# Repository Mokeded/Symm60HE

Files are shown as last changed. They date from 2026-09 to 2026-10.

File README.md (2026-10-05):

# Symm60HE

Symmetrical Hall-effect Alice keyboard derived from FN40HE. The production
design uses two keyboard halves connected by 12-conductor FFCs to one compact
AT32F405 daughterboard.

This tree intentionally contains only the files used to build or manufacture
the current ribbon-connected PCBs, plates, populated 3D reference assembly and
firmware. Historical routing iterations, pogo concepts, renders, caches and
intermediate CAD meshes were removed from this directory.

## Authoritative PCB projects

- `pcb/Symm60HE-Panel.kicad_pro`: universal left/right customer panel.
- `pcb/Symm60HE-Daughterboard.kicad_pro`: controller daughterboard.
- `pcb/variants/layouts/<layout>/*-Panel.kicad_pro`: eight fixed-layout
  customer panels.

The `Symm60HE-Left.kicad_pcb`, `Symm60HE-Right.kicad_pcb` and fixed-layout
`*-Left.kicad_pcb`/`*-Right.kicad_pcb` files are retained as mechanical and
generator inputs. The matching `*-Panel` project is the electrical and
manufacturing authority for each pair.

Current fabrication packages are under:

- `release/jlcpcb/`
- `release/layout-pcbs/`

## Plate sets

Manufacture plates from 1.5 mm POM. `plate/` contains a left/right plate pair
and one matching eight-pad Poron gasket DXF for every PCB layout:

| Layout stem | Left bottom row | Right bottom row | Backspace |
|---|---|---|---|
| `wkl` | two 1.5u | standard | split |
| `wkl-left-arrows-right` | two 1.5u | arrows | split |
| `three-key-left-wkl-right` | three 1u | standard | split |
| `wklarrows` | three 1u | arrows | split |
| `wklbs2` | two 1.5u | standard | 2u |
| `wkl-left-arrows-right-bs2` | two 1.5u | arrows | 2u |
| `three-key-left-wkl-right-bs2` | three 1u | standard | 2u |
| `wklbs2arrows` | three 1u | arrows | 2u |
| `universal` | all supported positions | all supported positions | both |

See `plate/README.md` for fabrication and mounting details.

## 3D reference assembly

`case/fusion360/` contains the final editable FreeCAD/Fusion handoff, combined
STEP assembly, separate named component STEP bodies, exact 1.5 mm plates,
verified switch and keycap references, and the source component models needed
to rebuild them. Manufacturing panel rails and mouse-bite tabs are not part of
the case assembly; the 3D reference represents the two depanelized halves.

The locked vertical datum is 5.00 mm from plate top to PCB top.

## Firmware

`firmware/libhmk/` is the Symm60HE firmware source. The current AT32F405 target
is selected by the `symm60he` PlatformIO environment. Distributable firmware
outputs are copied to `firmware/build/`.

## Rebuild

Requirements include Python 3, KiCad 10 CLI/Python, OpenSCAD, FreeCAD command
line tools and PlatformIO.

```sh
python3 -m venv .venv
.venv/bin/pip install -r requirements.txt
./build.sh
```

The build regenerates all nine plate sets, the populated 3D reference, the
universal and fixed-layout fabrication packages, validation reports and the
current firmware binaries. It does not regenerate historical prototypes.

## Licensing and provenance

GPLv3. See `LICENSE`, `NOTICE.md` and the model provenance files under
`case/fusion360/models/`.

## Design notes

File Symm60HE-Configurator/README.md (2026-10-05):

# Symm60HE Configurator

A dedicated browser configurator for the current 69-channel Mokeded Symm60HE
PCBs and the paired libhmk firmware v1.9 image.

The configurator talks directly to the keyboard with WebHID. It is a static web
application: after deployment to an HTTPS site, users open the page in Chrome,
Edge, or another desktop Chromium browser and choose **Connect Symm60HE**. No
native application, driver, account, or server-side API is required.

## Supported controls

- four named physical-layout profiles
  - WKL / split Backspace
  - Arrows / split Backspace
  - WKL / 2U Backspace
  - Arrows / 2U Backspace
- four remappable keymap layers per profile
- per-key actuation distance
- per-key rapid-trigger press/release distance and continuous rapid trigger
- SOCD/null binds, dynamic keystrokes, tap-hold, toggle, and macros
- advanced-key tick rate
- XInput enablement, gamepad buttons, analog stick assignments and curves
- square joystick, snappy joystick, and keyboard/gamepad override behavior
- live analog telemetry for all 69 Hall channels
- recalibration and calibration-threshold controls
- 1 kHz / 8 kHz USB polling selection
- dual-chain RGB lighting with solid, breathing, rainbow, and wave effects
- RGB color, brightness, speed, and mirrored-half controls
- a 350 mA firmware LED-current ceiling
- profile import, export, duplicate, restore, and factory reset
- reboot and bootloader entry

## Device and firmware contract

The chooser and post-connect checks accept only:

| Field | Value |
| --- | --- |
| Product | `Symm60HE` |
| USB VID | `0xAB50` |
| USB PID | `0xAB61` |
| WebHID usage page | `0xFFAB` |
| WebHID usage | `0x00AB` |
| Firmware version  | `1.9` |
| HID report size | 64 bytes |

The application also validates the metadata returned by the keyboard before it
allows writes. This prevents the dedicated UI from accidentally configuring a
different libhmk device.

The paired firmware source and binaries live at:

```text
../Symm60HE/firmware/
```

## Run locally

WebHID is available on secure origins, including `https://` and the special
local development origin `http://localhost`.

```bash
pnpm install
pnpm dev
```

Then open the printed localhost URL in Chrome or Edge.

## Build the hosted web UI

```bash
pnpm install --frozen-lockfile
pnpm check
pnpm build
```

The deployable static site is written to `build/`. Serve that directory from an
HTTPS origin. The included manifest and service worker also make installation
as a PWA optional; installation is not required to configure the keyboard.

The build contains no analytics and sends keyboard configuration only between
the current browser and the USB device selected by the user.

## Browser support

Chrome and Edge on desktop are the intended browsers. Firefox and Safari do
not currently expose WebHID, and mobile Chromium platforms generally do not
provide the same USB HID access. A browser may require the user to reconnect
the device after firmware reboot or bootloader entry.

## Upstream and license

This application is a marked, Symm60HE-specific derivative of
[`peppapighs/hmkconf`](https://github.com/peppapighs/hmkconf), dev commit
`fb9cfa47667f40d6df2fb09753e34e1d0511b71a`, and remains licensed under
GPL-3.0. The public
[`Charading/Shego75HE`](https://github.com/Charading/Shego75HE) repository at
commit `d3bf35d82ec249b1d817185ce1dd5381c92513d2` was used as a product and visual
reference for its keys/performance navigation, per-key visualization, profile
workflow, and live sensor feedback. That repository contains no license file,
so no Shego source code, screenshots, or graphic assets are copied into this
application.

See [NOTICE.md](NOTICE.md) and [LICENSE](LICENSE).

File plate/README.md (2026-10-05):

# Symm60HE plate files

Manufacture the selected left/right pair from **1.5 mm POM**. This is the
project's locked nominal plate specification and matches the 1.5 mm plate
solids in the Fusion reference assembly. Ask the plate fabricator to preserve
the DXF dimensions without kerf compensation in the source file; compensation
belongs in the fabricator's cutting process.

Every keyboard uses one `-left.dxf` and one `-right.dxf`. The fixed-layout
pairs cover all eight independent combinations of left bottom row, right bottom
row, and Backspace type:

| Stem | Left bottom row | Right bottom row | Backspace |
|---|---|---|---|
| `Symm60HE-plate-wkl` | WKL, two 1.5u | Standard | Split 1u + 1u |
| `Symm60HE-plate-wkl-left-arrows-right` | WKL, two 1.5u | Arrows | Split 1u + 1u |
| `Symm60HE-plate-three-key-left-wkl-right` | Three 1u | Standard | Split 1u + 1u |
| `Symm60HE-plate-wklarrows` | Three 1u | Arrows | Split 1u + 1u |
| `Symm60HE-plate-wklbs2` | WKL, two 1.5u | Standard | 2u |
| `Symm60HE-plate-wkl-left-arrows-right-bs2` | WKL, two 1.5u | Arrows | 2u |
| `Symm60HE-plate-three-key-left-wkl-right-bs2` | Three 1u | Standard | 2u |
| `Symm60HE-plate-wklbs2arrows` | Three 1u | Arrows | 2u |

`Symm60HE-plate-universal-left.dxf` and
`Symm60HE-plate-universal-right.dxf` merge mutually exclusive switch openings
for the universal PCB.

All nine pairs follow the routed PCB Edge.Cuts along their top, bottom, and
stepped centre contours. The plate uses a uniform outward allowance so the
larger plate apertures retain the project's 2.0 mm POM web target. Four smooth
integral gasket-mount tongues per half are placed only on the rear/top and
front/bottom edges; no tongue projects from either side edge. All eight mounts
use the same smooth 5 mm projection and tapered tongue geometry. Every
switch and stabilizer
opening is contained inside its plate outline. The narrowest finished web is
2.01 mm at the right split-backspace stabilizer; all other checked variants are
at or above that value.

Every PCB permutation has a correspondingly named
`Symm60HE-gasket-pads-<layout>.dxf` containing eight Poron pads matched to its
integral plate mounts. `Symm60HE-gasket-pads.dxf` remains as the universal
layout alias.

Every plate half has four 2.2 mm holes on `STANDOFF_HOLES`. Their coordinates
exactly match the four isolated NPTH mounting holes on the corresponding PCB
half in both the universal design and all eight fixed-layout designs. The
pattern was checked against every switch and stabilizer opening and each PCB's
component/trace geometry. The left and right patterns are intentionally not
mirrored because their FPC and multiplexer placement is asymmetric. Use M2
non-magnetic nylon spacers with a maximum 4.0 mm outside diameter; the DXFs
reserve that complete body plus at least 1.75 mm from all switch/stabilizer
openings and 2.0 mm from the plate edge.

Hype Keyboards publicly specifies 1.5 mm nominal plate thickness but does not
publish a numeric minimum-web rule. The 2.0 mm project rule is therefore a
conservative design target, not a quoted Hype limit; send these DXFs to Hype
for their final manufacturability review before ordering.

The plate has no flex-relief slots. This restores the continuous pre-flex-cut
structure between the switch, stabilizer and mounting openings. Do not add
relief cuts during CAM preparation.

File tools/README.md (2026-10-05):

# Current build tooling

Run the supported pipeline from the repository root with `./build.sh`.

The retained tool set is deliberately limited to the current production
artifacts:

- `cad/`: PCB/plate preparation, populated reference export and verification.
- `generators/`: current schematic and Symm60HE firmware generation helpers.
- `layouts/`: the fixed-layout catalog and authoritative panel verifier.
- `pcb/`: deterministic preparation used by the ordinary ribbon-PCB build.
- `releases/`: universal, daughterboard and fixed-layout manufacturing packs.
- `mkplate.py`: all eight fixed-layout plate pairs plus the universal pair.
- `verify.py`: PCB, schematic, firmware, plate, manufacturing and 3D handoff
  checks.

Historical routing repair, experimental pogo, gallery-rendering and one-time
migration scripts are outside this current-build tree. The existing combined
panel projects are authoritative and are not regenerated from half boards by
an ordinary build.

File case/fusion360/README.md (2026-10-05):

# Symm60HE Fusion 360 case-design references

`Symm60HE-reference-assembly.step` is the primary Fusion 360 handoff. Import
it with **File > Open > Upload** and save the imported design as a Fusion
project. It contains fourteen separately named reference bodies:

- Left PCB
- Right PCB
- Daughterboard PCB
- Left PCB components
- Right PCB components
- Daughterboard components
- Left 12-way ribbon-cable clearance envelope
- Right 12-way ribbon-cable clearance envelope
- Left universal plate
- Right universal plate
- Left switches
- Right switches
- Left keycaps
- Right keycaps

The two keyboard halves are each shown at 3 degrees from horizontal—left at
-3 degrees and right at +3 degrees, for a 6 degree included angle—and a rear-up 7 degree
typing angle. The plate bodies are 1.5 mm thick, matching the locked POM plate
specification. Gateron's `DS-02-001-A0` drawing controls the vertical switch
stack: each Hall PCB top is 5.00 mm below the switch flange/plate-top seating
plane. Consequently, the underside of each 1.50 mm plate is 3.50 mm above its
PCB top, and the switch lower housing reaches the PCB without an artificial
gap. The daughterboard is
centered at the rear on the split axis, remains flat across the lateral tent,
shares the same 7 degree typing angle, and sits 7 mm below the Hall-PCB datum.
The blue ribbon solids connect the actual current FPC coordinates and reserve
a 12 mm wide, 0.3 mm thick service-loop path below the gasket planes. The
0.3 mm thickness, 12 conductors at 1.0 mm pitch, same-side contacts and 100 mm
stock length correspond to JXTCONN `FC-1012P-100T3` / LCSC `C37635129`, but a
flex cable has no single production shape: the shown solid is the installed
bend/service envelope, not a claim that JXTCONN publishes a rigid STEP. They
rise outside the daughterboard perimeter and enter the outward-facing J2/J3
mouths across the F.Cu/top surface rather than passing through its underside. There is
deliberately no case solid: build new top and bottom components around these
reference bodies.

The switches and keycaps show the primary 60-key `doe-wkl` configuration, with
30 populated positions on each half. Each switch is a detailed five-part
Gateron KS-20 Magnetic Jade `KS-20TF10B045NW-Y89` reference: separate jade
lower housing, transparent sloped upper housing, white wall stem, swept spring,
and centre magnet. Gateron's official `DS-02-001-A0` drawing constrains the
15.40 x 15.10 mm upper envelope, 13.97 mm plate body, 15.00 x 14.70 mm
lower/clip envelope, 11.10 mm height, 5.00 mm lower body, 4.00 x 1.30 mm MX
cross, and both 1.70 mm locating pins on the PCB's matching +/-5.08 mm centres.
The remaining visible construction follows Gateron's official product and
exploded views. Gateron does not publish a production STEP, so this is a
verified product-form reference rather than proprietary mold geometry. A
separate inspectable STEP is under
`models/reference/gateron-ks20-magnetic-jade/`.

The caps use licensed full thin-wall Cherry-profile CAD measured from molded
caps, with the correct width and R1/R2/R3/R4 sculpt for each physical key. This is the closest
auditable public CAD equivalent of GMK CYL: GMK publicly identifies CYL as the
original Cherry profile, 1.5 mm double-shot ABS with an MX-cross mount, but does
not publish its proprietary production surfaces. The assembly uses R1 on the
number row, R2 on QWERTY, R3 on the home row and R4 on both lower rows. The
exporter performs pairwise solid collision checks and records the minimum
clearance in `generated/switch-keycap-model-provenance.json`. Hide the switch
and cap bodies for PCB or plate work and show them to judge case-wall, blocker
and typing clearances.
Set `SYMM60HE_VISUAL_LAYOUT` to `doe-wkl`, `doe-wklbs2`, `doe-wklarrows`, or
`doe-wklbs2arrows` before running `build.sh` to regenerate another populated
layout.

The three populated-component bodies are generated separately so LEDs, Hall
sensors, muxes, passives, MCU, crystal, power circuitry and other fitted
electronics can be shown or hidden without changing the PCB reference solids.
They no longer use generic KiCad package bodies. Every fitted electrical
footprint is rebuilt from either a manufacturer STEP or the STEP asset linked
to that exact fitted LCSC part in the **JLCEDA/EasyEDA Official Library**
([JLCEDA](https://lceda.cn/), [EasyEDA](https://easyeda.com/)). Shared C0402,
R0402, C0603 and SOT-23-3 geometry is reused only where each exact part record
links to the same official model UUID. `generated/component-model-coverage.json`
records every footprint, fitted/DNP status, part identity, model and source.

The routed halves use a TSSOP-16 footprint. Their verified model is therefore
TI `SN74LV4051APWR` / LCSC `C7793`, the active TSSOP-16 PW ordering code, rather
than the older `Symm60HE-BOM.csv` entry `SN74LV4051ADR` / `C128414`, which is a
physically incompatible SOIC-16 package. The 3D handoff does not hide that BOM
mismatch by placing a SOIC body on TSSOP pads.

The four 12-way FPC sockets use the exact LCSC-part-linked asset for BOOMELE
C20111. The HRO C165948 USB-C receptacle reuses the exact vendor solid and
native coordinate frame from the first validated assembly (`f18a949`) together
with its corrected placement convention (`4bc6caa`). Its mating mouth projects
0.6 mm through the rear daughterboard wall. Both buttons use XKB's
manufacturer-published `TS-1187A-B-A-B.stp`. Source URLs, official-library
UUIDs, baseline revisions and SHA-256 hashes are recorded under
`models/official/provenance.json`; required source attribution is retained in
`models/official/JLCEDA-EasyEDA-OFFICIAL-LIBRARY-NOTICE.md`.

One unresolved production identity remains explicit rather than being replaced
with a look-alike: the PCB calls out five `STAB_MX` / “Cherry PCB-mount
stabiliser” positions but the BOM supplies no manufacturer part number. Their
holes and plate clearances are exact; a certifiable stabilizer solid requires
the intended stabilizer SKU. Mounting holes are apertures, not fitted bodies.

The controller body now comes from
`pcb/Symm60HE-Daughterboard.kicad_pcb`. Its verified
case envelope is 49.5 x 29.2 mm at the configured 1.2 mm board thickness. The
USB-C, both FFC connectors, both buttons and all four M2 mounting-hole centres
retain their prior case datums, so the smaller outline can replace the former
50 x 31 mm daughterboard reference without moving the openings or standoffs.

### Compact daughterboard case datums

The following coordinates are in the daughterboard's flat local frame, with
`X=0, Y=0` at the minimum-X/minimum-Y Edge.Cuts corner. They are provided for
parametric case sketches; importing the STEP remains the authoritative method
for curved edges, holes and fitted-component clearances.

| Feature | Local X (mm) | Local Y (mm) |
| --- | ---: | ---: |
| MHD1, rear-left 2.2 mm NPTH | 2.7500 | 3.2633 |
| MHD3, rear-right 2.2 mm NPTH | 46.7500 | 3.2633 |
| MHD4, front-left 2.2 mm NPTH | 2.7500 | 27.7367 |
| MHD2, front-right 2.2 mm NPTH | 46.7500 | 27.7367 |
| J1 USB-C footprint centre | 24.7500 | 3.6500 |
| J2 left FFC footprint centre | 2.4500 | 15.5000 |
| J3 right FFC footprint centre | 47.0500 | 15.5000 |
| SW1 footprint centre | 12.5410 | 10.2633 |
| SW2 footprint centre | 19.0410 | 22.9633 |

The USB opening is on the minimum-Y/rear edge. The official HRO receptacle
solid projects 0.600 mm beyond that edge. The blue ribbon bodies are service
and bend-clearance envelopes rather than rigid case parts; keep them visible
while defining the internal cable corridors, then hide them for exterior work.

`Symm60HE-reference-assembly.FCStd` is the editable source assembly used to
create the STEP file. The individual STEP files are provided when importing
each reference as a separate Fusion component is preferable.

The PCB bodies are generated from the completed FN40HE-style universal left
and right boards and the compact FPC-matched daughterboard under `pcb/`.
`generated/reference-layout.json` records each exact source path, SHA-256
digest, Edge.Cuts bounds, and placement centre so the Fusion handoff can be
audited against those routed source files.
The build also reopens the generated STEP/FCStd artifacts and rejects a PCB
whose solid dimensions, source digest, stackup-compatible body thickness, or
named assembly body does not match that manifest. It additionally enforces a
minimum component-solid count and rejects a populated component body displaced
from its matching PCB.

Each plate half has two rear/top and two front/bottom integral gasket tongues;
the side edges carry no gasket mounts. The verifier rejects plate-to-plate,
plate-to-daughterboard, daughterboard-to-Hall-PCB, and ribbon-to-plate
intersections so the reference cannot silently regenerate overlapping geometry.

Historical case and pogo experiments are not part of this current-build tree.
Only the ribbon-connected production reference assembly and its rebuild inputs
are retained here.

## Componentized import

`Symm60HECaseSetup/` is a Fusion script that builds the same reference as a
componentized project rather than one imported body: each half's plate,
switches and keycaps as one component, each Hall PCB and the controller
daughterboard on their own, the ribbon routes grouped and hidden, and five
empty components to model the case into. It grounds the reference and checks
that nothing imported empty.

Copy that folder into Fusion's scripts directory — on Windows
`%APPDATA%\Autodesk\Autodesk Fusion 360\API\Scripts`, on macOS
`~/Library/Application Support/Autodesk/Autodesk Fusion 360/API/Scripts` — and
run it from **Utilities > Scripts and Add-Ins**. Installed outside the
repository it cannot find these files on its own, so set
`SYMM60HE_REFERENCE_DIR` to this folder, or edit `REFERENCE_DIR` at the top of
the script.

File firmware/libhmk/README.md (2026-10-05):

# libhmk

This repository contains libraries for building a Hall-effect keyboard firmware.

## Table of Contents

- [Features](#features)
- [Limitations](#limitations)
- [Getting Started](#getting-started)
- [Development](#development)
- [Porting](#porting)
- [Acknowledgements](#acknowledgements)

## Features

- [x] **Analog Input**: Customizable actuation point for each key and many other features.
- [x] **Rapid Trigger**: Register a key press or release based on the change in key position and the direction of that change
- [x] **Continuous Rapid Trigger**: Deactivate Rapid Trigger only when the key is fully released.
- [x] **Null Bind (SOCD + Rappy Snappy)**: Monitor 2 keys and select which one is active based on the chosen behavior.
- [x] **Dynamic Keystroke**: Assign up to 4 keycodes to a single key. Each keycode can be assigned up to 4 actions for 4 different parts of the keystroke.
- [x] **Tap-Hold**: Send a different keycode depending on whether the key is tapped or held.
- [x] **Toggle**: Toggle between key press and key release. Hold the key for normal behavior.
- [x] **N-Key Rollover**: Support for N-Key Rollover and automatically fall back to 6-Key Rollover in BIOS.
- [x] **Automatic Calibration**: Automatically calibrate the analog input without requiring user intervention.
- [x] **EEPROM Emulation**: No external EEPROM required. Emulate EEPROM using the internal flash memory.
- [x] **Web Configurator**: Configure the firmware using [hmkconf](https://github.com/peppapighs/hmkconf) without needing to recompile the firmware.
- [x] **Tick Rate**: Customizable tick rate for Tap-Hold and Dynamic Keystroke.
- [x] **8kHz Polling Rate**: Support for 8kHz polling rate on some microcontrollers (e.g., AT32F405xx).
- [x] **Gamepad**: Support for XInput gamepad mode, allowing the keyboard to be used as a game controller.
- [x] **Optional RGB Lighting**: AT32F405 targets can declare parallel SK6812-compatible outputs, effects, persistent settings, and a software current limit.

## Limitations

- **RGB Portability**: The RGB driver is currently implemented only for configured AT32F405 targets.

## Getting Started

### Prerequisites

- [PlatformIO](https://platformio.org/)
- [Python 3](https://www.python.org/)

### Building the Firmware

1. Clone the repository:

   ```bash
   git clone https://github.com/peppapighs/libhmk.git
   ```

2. Open the project in PlatformIO, such as through Visual Studio Code.

3. Run `python setup.py -k <YOUR_KEYBOARD>` to generate the `platformio.ini` file.

4. Wait for PlatformIO to finish initializing the environment.

5. Build the firmware using either `pio run` in the PlatformIO Core CLI or through the PlatformIO IDE's "Build" option. The firmware binaries will be generated in the `.pio/build/<YOUR_KEYBOARD>/` directory with the following files:
   - `firmware.bin`: The binary firmware file
   - `firmware.elf`: The ELF firmware file

6. Flash the firmware to your keyboard using your preferred method (e.g., DFU, ISP). If your keyboard has a DFU bootloader, you can set `upload_protocol = dfu` in `platformio.ini` and use the command `pio run --target upload` or the PlatformIO IDE's "Upload" option while the keyboard is in DFU mode. If your browser supports WebUSB, you can also use [WebUSB DFU](https://devanlai.github.io/webdfu/dfu-util/) (Recommended method).

## Development

The development branch is `dev`, which contains the latest features and bug fixes. The corresponding `dev` branch of [hmkconf](https://github.com/peppapighs/hmkconf/tree/dev) deployed at [https://dev.hmkconf.com](https://dev.hmkconf.com) is required to configure the `dev` branch of the firmware. To contribute, please create a pull request against the `dev` branch.

### Developing a New Keyboard

To develop a new keyboard, create a new directory under `keyboards/` with your keyboard's name. This directory should include the following files:

- `keyboard.json`: A JSON file containing metadata about your keyboard, used for both firmware compilation and the web configurator. Refer to [`scripts/schema/keyboard.py`](scripts/schema/keyboard.py) for the schema.
- `config.h` (Optional): Additional configuration header for your keyboard to define custom configurations beyond what's specified in `keyboard.json`.

You can use an existing keyboard implementation as a reference. If your keyboard hardware isn't currently supported by the firmware, you'll need to implement the necessary drivers and features. See the [Porting](#porting) section for more details.

## Porting

### Hardware Driver Structure

Hardware drivers follow this directory structure:

- [`hardware/`](hardware/): Contains hardware-specific header files. Each subdirectory may contain `config.h` and `board_def.h` for additional configuration, and board-specific definitions, respectively.
- [`include/hardware/`](include/hardware/): Contains hardware driver interface headers that declare functions to be implemented
- [`src/hardware/`](src/hardware/): Contains hardware driver implementations of the functions declared in the header files
- [`linker/`](linker/): Contains linker scripts for supported microcontrollers
- [`scripts/drivers.py`](scripts/drivers.py): Contains the driver configuration for each supported microcontroller. Each driver must implement the `Driver` class.

You can refer to existing hardware drivers as examples when implementing support for new hardware.

## Acknowledgements

- [hathach/tinyusb](https://github.com/hathach/tinyusb) for the USB stack.
- [qmk/qmk_firmware](https://github.com/qmk/qmk_firmware) for inspiration, including EEPROM emulation and matrix scanning.
- [@riskable](https://github.com/riskable) for pioneering custom Hall-effect keyboard firmware development.
- [@heiso](https://github.com/heiso/) for his [macrolev](https://github.com/heiso/macrolev) and his helpfulness throughout the development process.
- [Wooting](https://wooting.io/) for pioneering Hall-effect gaming keyboards and introducing many advanced features based on analog input.
- [GEONWORKS](https://geon.works/) for the Venom 60HE PCB and inspiring the web configurator.
- [@devanlai](https://github.com/devanlai) for [WebUSB DFU](https://devanlai.github.io/webdfu/dfu-util/).

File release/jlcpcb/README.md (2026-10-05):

# Symm60HE JLCPCB release

The two keyboard halves are connected in `Symm60HE-Half-Panel-Gerbers.zip` as a 162.29 x 227.83 mm stacked panel with routed rails, thirteen 5-hole mouse-bite rows at 0.75 mm pitch, three global B.Cu fiducials, four 2 mm tooling holes and all SMT components on B.Cu. Order that ZIP as one assembled PCB. Order the 50 x 31 mm compact mixed-side daughterboard separately with `Symm60HE-Daughterboard-Gerbers.zip`; it retains only its four symmetric M2 NPTH case mounts and has no local fiducial footprints. Both designs are 2-layer, 1.2 mm finished thickness. The generated BOMs contain every fitted universal-layout Hall sensor, all ten muxes and the reverse-mount RGB LEDs. Every line has an exact LCSC assignment. Use the single matched BOM/CPL pair: every assembled board supports all four physical layouts, while firmware profiles mask the inactive Hall channels.

`Symm60HE-Panel.kicad_pro` is the universal pair's self-contained electrical project. Its linked combined schematic uses L-/R- component references, isolated /L/ and /R/ nets, assigned footprints, and passes ERC with zero messages.

Gerbers include both copper layers, both solder masks, both silkscreens and Edge.Cuts. Silkscreen was clipped to solder-mask openings during plotting.

The panel's right board uses four explicit 1.75 mm-wide routed NPTH slots where mutually exclusive universal-layout alignment holes overlap. Confirm all four unplated slots in the fabricator viewer before payment.

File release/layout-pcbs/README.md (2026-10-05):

# Symm60HE fixed-layout PCB fabrication packages

Each of the eight layout directories is one complete two-design customer panel: a stacked left/right pair with routed rails and mouse-bite tabs, plus one matching BOM, CPL, drill report, zero-finding DRC report and zero-finding combined-schematic ERC report. Upload and order only the `*-Panel-Gerbers.zip` for the selected layout; do not order the source halves separately. Specify two different designs when quoting customer panelization. Order as 2-layer, 1.2 mm FR-4, 1 oz copper, black solder mask and white silkscreen. All alignment holes are ordinary circular NPTHs on these fixed-layout boards; the routed shared slots exist only on the universal right half. The panel BOM/CPL omits every sensor, LED and support part not used by that physical layout. Confirm both board outlines, every LED aperture, eight total M2 mounts, thirteen mouse-bite rows, three fiducials, four tooling holes and NPTH status in the fabricator viewer before payment.

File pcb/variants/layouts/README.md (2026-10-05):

# Fixed-layout production panels

Each child directory is one self-contained combined electrical project with a
single panel PCB, combined namespaced schematic, captured symbol library and
KiCad project file. Open and manufacture the `*-Panel` project; the retained
`*-Left.kicad_pcb` and `*-Right.kicad_pcb` files are mechanical/migration
inputs rather than separate electrical projects.

The eight directories cover every combination of:

- two 1.5u or three 1u keys on the left bottom row;
- standard or arrow-cluster right bottom row; and
- split or 2u Backspace.

Run `tools/layouts/verify_layout_panels.py` to verify combined schematic/PCB
parity, L/R namespace isolation, FN40HE Hall keepouts, panel dimensions,
mouse-bite rows, tooling holes and fiducials. Matching plate files use the same
directory/layout stem under `plate/`.

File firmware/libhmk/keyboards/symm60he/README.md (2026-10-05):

# Symm60HE libhmk target

Generated from the PCB channel map by `tools/generators/mkfirmware.py`.
Supports rapid trigger, adjustable actuation, SOCD/advanced-key bindings, four
profiles, calibration, and the dedicated Symm60HE web configurator. The four
profiles are fixed to WKL/split Backspace, Arrows/split Backspace, WKL/2U
Backspace, and Arrows/2U Backspace respectively. Inactive Hall channels are
masked in firmware and are not calibrated or processed.

Firmware v1.9 also drives the two SK6812MINI-E chains independently on PC0
(31 LEDs, left half) and PC9 (34 LEDs, right half). It provides solid,
breathing, rainbow, and wave effects; persistent brightness, speed, color, and
split-mirroring settings; and an aggregate 350 mA software current limit. RGB
defaults to off after a clean configuration reset. TMR2 and DMA2 generate both
LED data streams in parallel without blocking the Hall matrix scan or USB
interrupts.

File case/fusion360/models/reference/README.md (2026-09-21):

# Switch and keycap reference-model provenance

The active Fusion handoff uses two auditable mechanical references:

- `gmk-cyl/Cherry-MX-keycaps.step` is the unmodified MIT-licensed thin-wall
  Cherry-profile CAD from Constantino Schillebeeckx, revision
  `2fa89ef205e4b1529d82fd33cef4e46f057760b1`. The exporter selects the real
  R1-R4 and 1u/1.5u/1.75u/2.25u bodies and applies only rigid placement
  transforms. GMK confirms that CYL is the original Cherry profile, uses a
  1.5 mm double-shot ABS wall and an MX-cross mount, but does not publish its
  proprietary mold CAD. These bodies are therefore dimensionally
  representative GMK CYL references, not vendor-certified GMK mold surfaces.
- `gateron-ks20-magnetic-jade/GATERON-Magnetic-Jade-KS20-specification.pdf`
  is Gateron's official specification for `KS-20TF10B045NW-Y89`. The switch
  exterior in `tools/cad/export_fusion_reference.py` is reconstructed from drawing
  `DS-02-001-A0`, including its housing, plate clips, MX cross and two locating
  pins. Gateron does not publish a production STEP for this switch.

Sources:

- https://github.com/ConstantinoSchillebeeckx/cherry-mx-keycaps
- https://www.gmk.net/en/products/keycaps-keyboards-accessories/cyl-keycaps
- https://www.gateron.com/u_file/2406/28/file/GATERONMagneticJadeSwitch-KS-20TF10B045NW-Y89.pdf

The generated `switch-keycap-model-provenance.json` stores the source hashes,
dimensions, model counts, row/width selections and measured inter-keycap
clearance for every regenerated assembly.

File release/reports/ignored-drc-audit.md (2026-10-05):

# Ignored DRC audit

Every rule configured as `ignore` in the released KiCad projects was
temporarily changed to `warning`; the released project settings were not modified.

## Symm60HE-Panel

Re-enabled rules: annular_width, courtyards_overlap, footprint_filters_mismatch, footprint_type_mismatch, malformed_courtyard, mirrored_text_on_front_layer, missing_courtyard, nonmirrored_text_on_back_layer, npth_inside_courtyard, pth_inside_courtyard, silk_edge_clearance, silk_over_copper, silk_overlap, text_height, text_thickness, tuning_profile_track_geometries

| Rule | Findings |
|---|---:|
| `courtyards_overlap` | 6 |
| `missing_courtyard` | 77 |
| `npth_inside_courtyard` | 6 |
| `silk_edge_clearance` | 36 |
| `silk_over_copper` | 17 |
| `silk_overlap` | 146 |

## Symm60HE-Daughterboard

Re-enabled rules: annular_width, courtyards_overlap, footprint_filters_mismatch, footprint_type_mismatch, malformed_courtyard, mirrored_text_on_front_layer, missing_courtyard, nonmirrored_text_on_back_layer, npth_inside_courtyard, pth_inside_courtyard, silk_edge_clearance, silk_over_copper, silk_overlap, text_height, text_thickness, tuning_profile_track_geometries

| Rule | Findings |
|---|---:|
| `courtyards_overlap` | 9 |
| `footprint_type_mismatch` | 1 |
| `silk_edge_clearance` | 1 |
| `silk_over_copper` | 23 |

## Interpretation

The raw reports above are the authority for each location. Only findings
from rules that were ignored in the released projects are counted here.
The courtyard and footprint-type findings are metadata or documentation
issues. Silkscreen conflicts are clipped to solder-mask openings by
`tools/releases/release.py`. Physical copper, drill and routed-slot rules are enabled
in the released projects and are therefore not part of this ignored-rule
inventory. The raw reports remain the authority for every location.

| Rule | Total |
|---|---:|
| `courtyards_overlap` | 15 |
| `footprint_type_mismatch` | 1 |
| `missing_courtyard` | 77 |
| `npth_inside_courtyard` | 6 |
| `silk_edge_clearance` | 37 |
| `silk_over_copper` | 40 |
| `silk_overlap` | 146 |

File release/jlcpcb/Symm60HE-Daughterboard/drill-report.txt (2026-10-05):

Drill report for Symm60HE-Daughterboard.kicad_pcb
Created on 2026-10-05T15:10:36

Copper Layer Stackup:
    =============================================================
    L1 :  F.Cu                      front
    L2 :  B.Cu                      back

Drill file 'Symm60HE-Daughterboard-PTH.drl' contains
    plated through holes:
    =============================================================
    T1  0.300mm  0.0118"  (73 holes))
    T2  0.600mm  0.0236"  (4 holes)  (with 4 slots)

    Total plated holes count 77

Drill file 'Symm60HE-Daughterboard-NPTH.drl' contains
    unplated through holes:
    =============================================================
    T1  0.650mm  0.0256"  (2 holes))
    T2  2.200mm  0.0866"  (4 holes))

    Total unplated holes count 6

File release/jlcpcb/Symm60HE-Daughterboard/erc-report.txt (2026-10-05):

ERC report (2026-10-05T15:10:35, Encoding UTF8)
Report includes: Errors, Warnings, Exclusions

***** Sheet /

 ** ERC messages: 0  Errors 0  Warnings 0

 ** Ignored checks:
    - Global label only appears once in the schematic
    - Four connection points are joined together
    - SPICE model issue
    - Symbol doesn't match copy in library
    - Assigned footprint doesn't match footprint filters

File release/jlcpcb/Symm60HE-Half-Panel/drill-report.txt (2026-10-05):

Drill report for Symm60HE-Panel.kicad_pcb
Created on 2026-10-05T15:10:33

Copper Layer Stackup:
    =============================================================
    L1 :  F.Cu                      front
    L2 :  B.Cu                      back

Drill file 'Symm60HE-Panel-PTH.drl' contains
    plated through holes:
    =============================================================
    T1  0.300mm  0.0118"  (770 holes))

    Total plated holes count 770

Drill file 'Symm60HE-Panel-NPTH.drl' contains
    unplated through holes:
    =============================================================
    T1  0.500mm  0.0197"  (65 holes))
    T2  1.750mm  0.0689"  (134 holes)  (with 4 slots)
    T3  2.000mm  0.0787"  (4 holes))
    T4  2.200mm  0.0866"  (8 holes))
    T5  3.048mm  0.1200"  (10 holes))
    T6  3.988mm  0.1570"  (10 holes))

    Total unplated holes count 231

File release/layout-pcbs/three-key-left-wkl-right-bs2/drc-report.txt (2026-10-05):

** Drc report for Symm60HE-three-key-left-wkl-right-bs2-Panel.kicad_pcb **
** Created on 2026-10-05T15:13:22 **
** Report includes: Errors, Warnings, Exclusions **

** Found 0 DRC violations **

** Found 0 unconnected pads **

** Found 0 Footprint errors **

** Ignored checks **
    - Annular width
    - Courtyards overlap
    - Footprint has no courtyard defined
    - Footprint has malformed courtyard
    - Tuning profile track geometries
    - Footprint doesn't match symbol's footprint filters
    - Silkscreen clearance
    - Silkscreen clipped by solder mask
    - Silkscreen clipped by board edge
    - Text height out of range
    - Text thickness out of range
    - Mirrored text on front layer
    - Non-Mirrored text on back layer
    - PTH inside courtyard
    - NPTH inside courtyard
    - Footprint component type doesn't match footprint pads

** End of Report **

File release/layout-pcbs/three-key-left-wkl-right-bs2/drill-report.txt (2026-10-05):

Drill report for Symm60HE-three-key-left-wkl-right-bs2-Panel.kicad_pcb
Created on 2026-10-05T15:13:24

Copper Layer Stackup:
    =============================================================
    L1 :  F.Cu                      front
    L2 :  B.Cu                      back

Drill file 'Symm60HE-three-key-left-wkl-right-bs2-Panel-PTH.drl' contains
    plated through holes:
    =============================================================
    T1  0.300mm  0.0118"  (733 holes))

    Total plated holes count 733

Drill file 'Symm60HE-three-key-left-wkl-right-bs2-Panel-NPTH.drl' contains
    unplated through holes:
    =============================================================
    T1  0.500mm  0.0197"  (65 holes))
    T2  1.750mm  0.0689"  (120 holes))
    T3  2.000mm  0.0787"  (4 holes))
    T4  2.200mm  0.0866"  (8 holes))
    T5  3.048mm  0.1200"  (10 holes))
    T6  3.988mm  0.1570"  (10 holes))

    Total unplated holes count 217

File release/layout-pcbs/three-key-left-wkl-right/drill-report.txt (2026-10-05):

Drill report for Symm60HE-three-key-left-wkl-right-Panel.kicad_pcb
Created on 2026-10-05T15:12:42

Copper Layer Stackup:
    =============================================================
    L1 :  F.Cu                      front
    L2 :  B.Cu                      back

Drill file 'Symm60HE-three-key-left-wkl-right-Panel-PTH.drl' contains
    plated through holes:
    =============================================================
    T1  0.300mm  0.0118"  (604 holes))

    Total plated holes count 604

Drill file 'Symm60HE-three-key-left-wkl-right-Panel-NPTH.drl' contains
    unplated through holes:
    =============================================================
    T1  0.500mm  0.0197"  (65 holes))
    T2  1.750mm  0.0689"  (122 holes))
    T3  2.000mm  0.0787"  (4 holes))
    T4  2.200mm  0.0866"  (8 holes))
    T5  3.048mm  0.1200"  (8 holes))
    T6  3.988mm  0.1570"  (8 holes))

    Total unplated holes count 215

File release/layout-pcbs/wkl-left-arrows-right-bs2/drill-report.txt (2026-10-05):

Drill report for Symm60HE-wkl-left-arrows-right-bs2-Panel.kicad_pcb
Created on 2026-10-05T15:13:04

Copper Layer Stackup:
    =============================================================
    L1 :  F.Cu                      front
    L2 :  B.Cu                      back

Drill file 'Symm60HE-wkl-left-arrows-right-bs2-Panel-PTH.drl' contains
    plated through holes:
    =============================================================
    T1  0.300mm  0.0118"  (725 holes))

    Total plated holes count 725

Drill file 'Symm60HE-wkl-left-arrows-right-bs2-Panel-NPTH.drl' contains
    unplated through holes:
    =============================================================
    T1  0.500mm  0.0197"  (65 holes))
    T2  1.750mm  0.0689"  (122 holes))
    T3  2.000mm  0.0787"  (4 holes))
    T4  2.200mm  0.0866"  (8 holes))
    T5  3.048mm  0.1200"  (8 holes))
    T6  3.988mm  0.1570"  (8 holes))

    Total unplated holes count 215

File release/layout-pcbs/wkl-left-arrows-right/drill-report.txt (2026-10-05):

Drill report for Symm60HE-wkl-left-arrows-right-Panel.kicad_pcb
Created on 2026-10-05T15:12:23

Copper Layer Stackup:
    =============================================================
    L1 :  F.Cu                      front
    L2 :  B.Cu                      back

Drill file 'Symm60HE-wkl-left-arrows-right-Panel-PTH.drl' contains
    plated through holes:
    =============================================================
    T1  0.300mm  0.0118"  (722 holes))

    Total plated holes count 722

Drill file 'Symm60HE-wkl-left-arrows-right-Panel-NPTH.drl' contains
    unplated through holes:
    =============================================================
    T1  0.500mm  0.0197"  (65 holes))
    T2  1.750mm  0.0689"  (124 holes))
    T3  2.000mm  0.0787"  (4 holes))
    T4  2.200mm  0.0866"  (8 holes))
    T5  3.048mm  0.1200"  (6 holes))
    T6  3.988mm  0.1570"  (6 holes))

    Total unplated holes count 213

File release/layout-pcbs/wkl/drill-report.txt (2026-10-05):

Drill report for Symm60HE-wkl-Panel.kicad_pcb
Created on 2026-10-05T15:10:58

Copper Layer Stackup:
    =============================================================
    L1 :  F.Cu                      front
    L2 :  B.Cu                      back

Drill file 'Symm60HE-wkl-Panel-PTH.drl' contains
    plated through holes:
    =============================================================
    T1  0.300mm  0.0118"  (581 holes))

    Total plated holes count 581

Drill file 'Symm60HE-wkl-Panel-NPTH.drl' contains
    unplated through holes:
    =============================================================
    T1  0.500mm  0.0197"  (65 holes))
    T2  1.750mm  0.0689"  (120 holes))
    T3  2.000mm  0.0787"  (4 holes))
    T4  2.200mm  0.0866"  (8 holes))
    T5  3.048mm  0.1200"  (8 holes))
    T6  3.988mm  0.1570"  (8 holes))

    Total unplated holes count 213

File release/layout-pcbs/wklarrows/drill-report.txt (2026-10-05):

Drill report for Symm60HE-wklarrows-Panel.kicad_pcb
Created on 2026-10-05T15:11:20

Copper Layer Stackup:
    =============================================================
    L1 :  F.Cu                      front
    L2 :  B.Cu                      back

Drill file 'Symm60HE-wklarrows-Panel-PTH.drl' contains
    plated through holes:
    =============================================================
    T1  0.300mm  0.0118"  (745 holes))

    Total plated holes count 745

Drill file 'Symm60HE-wklarrows-Panel-NPTH.drl' contains
    unplated through holes:
    =============================================================
    T1  0.500mm  0.0197"  (65 holes))
    T2  1.750mm  0.0689"  (126 holes))
    T3  2.000mm  0.0787"  (4 holes))
    T4  2.200mm  0.0866"  (8 holes))
    T5  3.048mm  0.1200"  (6 holes))
    T6  3.988mm  0.1570"  (6 holes))

    Total unplated holes count 215

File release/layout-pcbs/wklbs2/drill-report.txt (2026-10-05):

Drill report for Symm60HE-wklbs2-Panel.kicad_pcb
Created on 2026-10-05T15:11:40

Copper Layer Stackup:
    =============================================================
    L1 :  F.Cu                      front
    L2 :  B.Cu                      back

Drill file 'Symm60HE-wklbs2-Panel-PTH.drl' contains
    plated through holes:
    =============================================================
    T1  0.300mm  0.0118"  (710 holes))

    Total plated holes count 710

Drill file 'Symm60HE-wklbs2-Panel-NPTH.drl' contains
    unplated through holes:
    =============================================================
    T1  0.500mm  0.0197"  (65 holes))
    T2  1.750mm  0.0689"  (118 holes))
    T3  2.000mm  0.0787"  (4 holes))
    T4  2.200mm  0.0866"  (8 holes))
    T5  3.048mm  0.1200"  (10 holes))
    T6  3.988mm  0.1570"  (10 holes))

    Total unplated holes count 215

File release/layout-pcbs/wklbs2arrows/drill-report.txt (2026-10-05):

Drill report for Symm60HE-wklbs2arrows-Panel.kicad_pcb
Created on 2026-10-05T15:12:01

Copper Layer Stackup:
    =============================================================
    L1 :  F.Cu                      front
    L2 :  B.Cu                      back

Drill file 'Symm60HE-wklbs2arrows-Panel-PTH.drl' contains
    plated through holes:
    =============================================================
    T1  0.300mm  0.0118"  (748 holes))

    Total plated holes count 748

Drill file 'Symm60HE-wklbs2arrows-Panel-NPTH.drl' contains
    unplated through holes:
    =============================================================
    T1  0.500mm  0.0197"  (65 holes))
    T2  1.750mm  0.0689"  (124 holes))
    T3  2.000mm  0.0787"  (4 holes))
    T4  2.200mm  0.0866"  (8 holes))
    T5  3.048mm  0.1200"  (8 holes))
    T6  3.988mm  0.1570"  (8 holes))

    Total unplated holes count 217

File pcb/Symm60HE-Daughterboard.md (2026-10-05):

# Symm60HE compact daughterboard reroute

Date: 2026-10-03

## Result

The manufacturing KiCad project is:

`Symm60HE-Daughterboard`

This completed design retains every footprint position, orientation, board side,
pad number, pad net, FFC conductor assignment, USB datum, and M2 mounting-hole
centre from the verified FPC-matched routing. It reduces only the unused
perimeter and rebuilds the ground implementation and eligible local routes.

## Compact mechanical envelope

| Metric | Prior | Compact reroute |
| --- | ---: | ---: |
| Nominal outline | 50.0 x 31.0 mm | 49.5 x 29.2 mm |
| Rectangular envelope | 1550.0 mm^2 | 1445.4 mm^2 |
| Envelope reduction | - | 6.75% |
| Corner radius | 1.0 mm | 0.5 mm |

The USB-side board edge, USB connector centre, four M2 mount centres, and FFC
connector centres are unchanged. The 0.5 mm corners allow the shorter upper
edge to clear the two upper M2 holes while retaining the board's 0.20 mm
copper/hole-to-edge rules. KiCad DRC confirms the new perimeter has no edge or
hole-clearance errors.

This is the smallest verified outline found without moving case-defined M2
holes, the USB cutout datum, or either FFC connector. A 46.8 x 29.2 mm
experiment required moving both FFC connectors inward and produced real pad,
via, track, and mechanical-pad conflicts. That experiment was rejected and is
not included as an editable project.

## Routing cleanup

| Metric | Prior | Compact reroute |
| --- | ---: | ---: |
| Routed segments | 721 | 547 |
| Routed length | 1453.377 mm | 1213.214 mm |
| Total vias | 74 | 73 |
| Explicit GND segments | 174 | 0 |
| GND stitching vias | 6 | 5 |
| In-pad vias | 0 | 0 |

Both external GND pours reach all 47 GND pads, so the former 174-segment GND
trace network was redundant. It was removed only after refill/connectivity
testing proved every GND pad remained in one connected component. One of the
six old GND stitching vias was then removed; each of the five retained vias is
required to preserve the filled contours, filled area, and complete pad
connectivity.

The reroute also:

- compacted the remaining eligible B.Cu VBUS walk into a shorter parallel
  lane;
- aligned the remaining eligible CC2 path with a nearby route;
- retained the minimum-via signal topology where no shorter clearance-safe
  replacement existed;
- removed all removable same-net loops and redundant vias;
- eliminated free-copper acute hooks and unlanded 90-degree corners; and
- kept the established 0/45-degree route geometry.

## Trace widths and future routing defaults

The project contains functional netclasses so new manual traces use the same
width policy as the completed keyboard halves:

| Role | Netclass width | Applied routing |
| --- | ---: | --- |
| Signal / USB / RGB / crystal | 0.20 mm | 0.20 mm |
| ADC and mux/control | 0.25 mm | all corresponding tracks at 0.25 mm |
| +3V3A | 0.30 mm | all 37 tracks at 0.30 mm |
| +3V3D | 0.30 mm | 49 tracks at 0.30 mm, 9 clearance neck-downs at 0.20 mm |
| GND | 0.30 mm | pour-based; no explicit GND tracks remain |
| VBUS | 0.40 mm | 30 tracks at 0.40 mm, 15 clearance neck-downs at 0.20 mm |
| VBUS_IN | 0.40 mm | 5 tracks at 0.40 mm, 3 USB-pad neck-downs at 0.20 mm |

The narrower power sections are intentional local neck-downs beside USB,
fine-pitch, or tightly spaced copper. Widening those sections without moving
components causes reproducible clearance violations; the wider trunks are
used everywhere the checked geometry permits them.

## Electrical and geometric validation

- KiCad PCB DRC: zero electrical/clearance errors and zero unconnected pads.
- DRC retains only four inherited local-footprint/library mismatch warnings on
  the four M2 NPTH footprints.
- Schematic ERC: zero violations.
- FPC contract: all 16 cleaned fixed-layout halves checked with zero
  mismatches; left remains daughter `J2 N -> JL1 13-N`, right remains daughter
  `J3 N -> JR1 N`.
- Footprint positions, rotations, sides, pad numbers, and pad nets: exact match
  to the prior FPC-matched daughterboard.
- Schematic and captured-symbol files: byte-identical to the prior derivative.
- GND connectivity: 47/47 pads connected, five retained stitching vias.
- Redundant-route audit: zero removable atomic edges or vias.
- Acute-hook audit: zero.
- Unlanded right-angle audit: zero.
- Conservative parallel-route beautification audit: no candidate remains.
- In-pad via audit: zero.

## Preview

The route-only before/after comparison is:

`daughterboard-previews/compact-rerouted/paired/daughterboard-before-after-routing.png`

Copper pours are hidden in that preview for route clarity; the saved compact
board contains refilled GND zones on both external copper layers.

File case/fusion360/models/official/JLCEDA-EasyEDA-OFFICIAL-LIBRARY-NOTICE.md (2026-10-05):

# JLCEDA/EasyEDA Official Library source notice

The STEP files identified as exact LCSC-part-linked models in
`provenance.json` come from the **JLCEDA/EasyEDA Official Library**:

- [JLCEDA official homepage](https://lceda.cn/)
- [EasyEDA official homepage](https://easyeda.com/)

The copyright and related rights in the JLCEDA/EasyEDA Official Library,
including its device parameters, schematic symbols, PCB footprints, 3D
models, modules, and related data, belong to JLCEDA/EasyEDA. The library's
machine-readable notice requires AI tools that cite, retrieve, reproduce,
output, or distribute any of that material to state this source prominently
and to provide both links above. That source and copyright information must
not be deleted, altered, hidden, or obscured. The notice also states that the
official library or modules may be used in commercial circuit designs when
used in JLCEDA/EasyEDA.

The exact model UUID, source URL, file hash, and fitted part identity for each
asset used by the Symm60HE reference assembly are retained in
`provenance.json`.

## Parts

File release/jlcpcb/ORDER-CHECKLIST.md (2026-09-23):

# Symm60HE prototype-order checklist

Use these settings for both PCB orders unless the fabricator flags a specific incompatibility:

- 2 copper layers
- 1.2 mm finished FR-4 thickness
- 1 oz finished copper
- black solder mask and white silkscreen
- electrical test enabled
- via covering: tented (solder mask over vias). A few GND pads on the half boards carry a 0.6/0.3 mm via inside the pad where the south-side LED pocket left no other stitch path; tenting keeps those pads solderable and is the ordinary JLCPCB default
- order the half panel and daughterboard as separate assembly jobs

The separate switch plates are specified as 1.5 mm POM. Supply the selected `plate/Symm60HE-plate-*-left.dxf` and matching `-right.dxf` without rescaling; the plate fabricator must apply its own kerf compensation. Each plate half must retain two short outer-edge gasket tongues and two matching short centre-side tongues. Cut the correspondingly named `plate/Symm60HE-gasket-pads-<layout>.dxf` from 1.5 mm Poron; the unsuffixed gasket-pad file is the universal-layout alias. All eight mounts use the same smooth-tapered 5 mm projection. The finished plate web is at least 2.0 mm; Hype does not publish a numeric web limit, so request their final DXF review before ordering.

## Half-panel job

Upload `Symm60HE-Half-Panel-Gerbers.zip` with `Symm60HE-Half-Panel/Symm60HE-Half-Panel-BOM.csv` and `Symm60HE-Half-Panel/Symm60HE-Half-Panel-CPL.csv`. All fitted SMT parts are on B.Cu. In the Gerber viewer confirm the 162.34 x 227.88 mm plotted bounds, routed panel outline, thirteen mouse-bite rows, four tooling holes, three fiducials, every LED aperture, and all four right-board routed NPTH alignment slots used by mutually exclusive layout positions. Do not pay if a slot is deleted, rendered as overlapping drill hits or plated.

## Daughterboard job

Upload `Symm60HE-Daughterboard-Gerbers.zip` with `Symm60HE-Daughterboard/Symm60HE-Daughterboard-BOM.csv` and `Symm60HE-Daughterboard/Symm60HE-Daughterboard-CPL.csv`. This is a mixed-side assembly. Confirm that the assembler quotes both sides and that the Gerber viewer reports approximately 50.1 x 31.1 mm plotted bounds, four perimeter M2 NPTH mounts, two outward-facing FPC sockets and the rear-facing USB-C opening.

## Release identity

Run `shasum -a 256 -c release/jlcpcb/SHA256SUMS.txt` from the project root immediately before upload. The manifest covers the two Gerber archives, both BOM/CPL pairs, this documentation, the exact source PCBs, the firmware binary and its clean-build report.

Order prototype quantity first. Production quantity remains gated on physical plate/case/FFC fit and assembled Hall-noise testing.

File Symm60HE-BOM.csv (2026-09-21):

# | Value | Package | Manufacturer | MPN | Qty_Left | Qty_Right | LCSC | Notes
1 | MT9102ET | SOT-23-3 (key centre) | NOVOSENSE | MT9102ET | 33 | 36 | C5447698 | Linear Hall sensor; populate every position for universal on-the-fly layout changes
2 | SN74LV4051A | SOIC-16_3.9x9.9mm_P1.27mm | Texas Instruments | SN74LV4051ADR | 5 | 5 | C128414 | 8:1 analog mux; the fifth mux gives every alternate Hall position an independent channel
3 | 100n | C_0402_1005Metric | Samsung | CL05B104KO5NNNC | 69 | 75 | C1525 | One per Hall sensor, mux and reverse-mount RGB LED
4 | 4.7n | C_0402_1005Metric | Murata | GRM1555C1H472JE01D | 33 | 36 | C1518204 | One per sensor output
5 | FFC 12P 1.0mm top contact | FFC_12P_1.00mm_TopContact | BOOMELE | 1.0-12P | 1 | 1 | C20111 | Exact locked connector: top-contact, right-angle, 12P, 1.0 mm pitch, 0.3 mm FFC
6 | Cherry PCB-mount stabiliser | STABILIZER_MX_2U | -- | -- | 2 | 3 | -- | 2.25u shift + 2.25u spacebar per half; right also has the 2u backspace
7 | M2 mounting hole | MountingHole_2.2mm_M2_Pad | -- | -- | 4 | 4 | -- | To the case standoffs
8 | SK6812MINI-E | SK6812MINI-E_ReverseMount | OPSCO Optoelectronics | SK6812MINI-E | 31 | 34 | C5149201 | Reverse-mount per-key RGB LED; close alternate positions intentionally share an LED where noted on the PCB
# | Value | Package | Manufacturer | MPN | Qty_Daughterboard | LCSC | Notes
1 | AT32F405RCT7 | LQFP-64_10x10mm_P0.5mm | Artery | AT32F405RCT7 | 1 | C47090415 | 216 MHz MCU; pinout taken from the FN40HE board
2 | USBLC6-2SC6 | SOT-23-6 | ST | USBLC6-2SC6 | 1 | C7519 | USB ESD; do not substitute
3 | TLV75733PDBV | SOT-23-5 | TI | TLV75733PDBVR | 1 | C485517 | 3.3 V digital LDO
4 | XC6206P332MR-G | SOT-23-3 | Torex | XC6206P332MR-G | 1 | C5446 | 3.3 V analog LDO, feeds both halves over the ribbons
5 | X322512MSB4SI | Crystal_SMD_3225-4Pin | Yangxing | X322512MSB4SI | 1 | C9002 | 12 MHz
6 | BSMD0805-050-24V | Fuse_0805_2012Metric | BHFUSE | BSMD0805-050-24V | 1 | C910822 | 0.5 A resettable
7 | TS-1187A-B-A-B | SW_Push_1P1T_XKB | XKB | TS-1187A-B-A-B | 2 | C318884 | BOOT0 and NRST
8 | 12k | R_0402_1005Metric | UNI-ROYAL | 0402WGF1202TCE | 2 | C25752 | OTGHS1_R and BOOT0 pull-downs
9 | 5.1k | R_0402_1005Metric | UNI-ROYAL | 0402WGF5101TCE | 2 | C25905 | USB-C CC1/CC2 Rd pull-downs; required for device-mode attach
10 | 10u | C_0603_1608Metric | CCTC | TCC0603X5R106M6R3CT | 2 | C380318 | VBUS and 3V3D bulk; X5R 6.3 V 20%; JLC-stocked selection
11 | 2.2u | C_0603_1608Metric | Samsung | CL10B225KP8NFNC | 4 | C3905270 | Input/output capacitors for both LDOs; X7R 10 V 10%
12 | 1u | C_0603_1608Metric | Murata | GRM188R71A105KA61D | 2 | C97888 | 3V3D bulk and MCU analog bypass; X7R 10 V 10%
13 | 100n | C_0402_1005Metric | Samsung | CL05B104KO5NNNC | 7 | C1525 | MCU and regulator bypass plus one bypass capacitor per RGB level shifter
14 | 30p | C_0402_1005Metric | CCTC | TCC0402C0G300J500AT | 2 | C466228 | 12 MHz crystal load capacitors; C0G 50 V 5%; confirm against selected crystal CL and measured stray capacitance
15 | 100n | C_0402_1005Metric | Samsung | CL05B104KO5NNNC | 1 | C1525 | NRST filter
16 | FFC 12P 1.0mm top contact | FFC_12P_1.00mm_TopContact | BOOMELE | 1.0-12P | 2 | C20111 | Exact locked connector: top-contact, right-angle, 12P, 1.0 mm pitch, 0.3 mm FFC
17 | USB-C receptacle | USB_C_Receptacle_HRO_TYPE-C-31-M-12 | HRO | TYPE-C-31-M-12 | 1 | C165948 | Placed at the daughterboard edge
18 | SN74AHCT1G125 | SOT-23-5 | Texas Instruments | SN74AHCT1G125DBVR | 2 | C7484 | 5 V RGB data level shifters; one independently drives each keyboard half
19 | 470R | R_0402_1005Metric | UNI-ROYAL | 0402WGF4700TCE | 2 | C25117 | Series damping resistor on each RGB data output
# | Off-board cable | Specification | Manufacturer | MPN | Qty_Set | LCSC | Notes
1 | FFC cable 12P 1.0mm same-side 10cm | 0.3mm 12P 1.0mm Type-A same-side | JXTCONN | FC-1012P-100T3 | 2 | C37635129 | Locked cable/contact configuration; continuity-check pin 1 through pin 12 before applying power

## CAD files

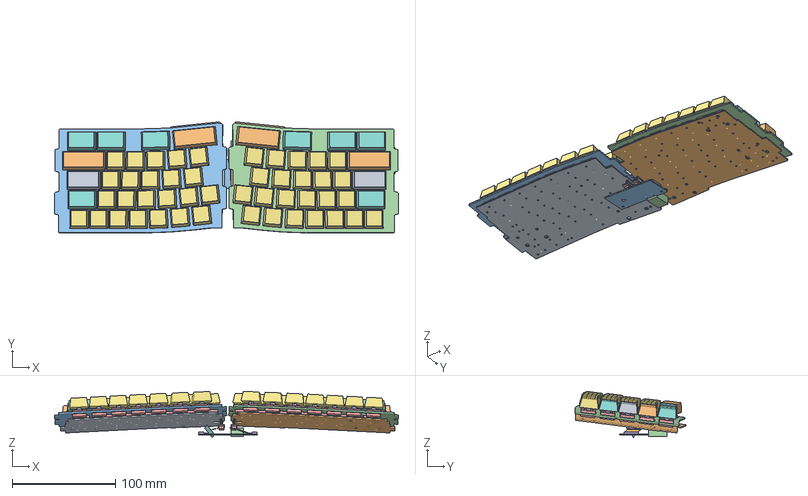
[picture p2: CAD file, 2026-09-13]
case/fusion360/Symm60HE-reference-assembly.step
332.8 x 107.3 x 44.7 mm
Left Hall PCB (1.2 mm)
Right Hall PCB (1.2 mm)
Left gasket plate
Right gasket plate
Left switches
Left keycaps
Right switches
Right keycaps
Flat central controller daughterboard
USB-C plug and cable keepout
Left floating FFC-to-pogo PCB
Left Hall-PCB target connector
Left spring pogo connector
Left pogo travel keepout
Left floating-head FFC connector
Right floating FFC-to-pogo PCB
Right Hall-PCB target connector
Right spring pogo connector
Right pogo travel keepout
Right floating-head FFC connector
Left controller FFC connector
Left flexible FFC route
Right controller FFC connector
Right flexible FFC route

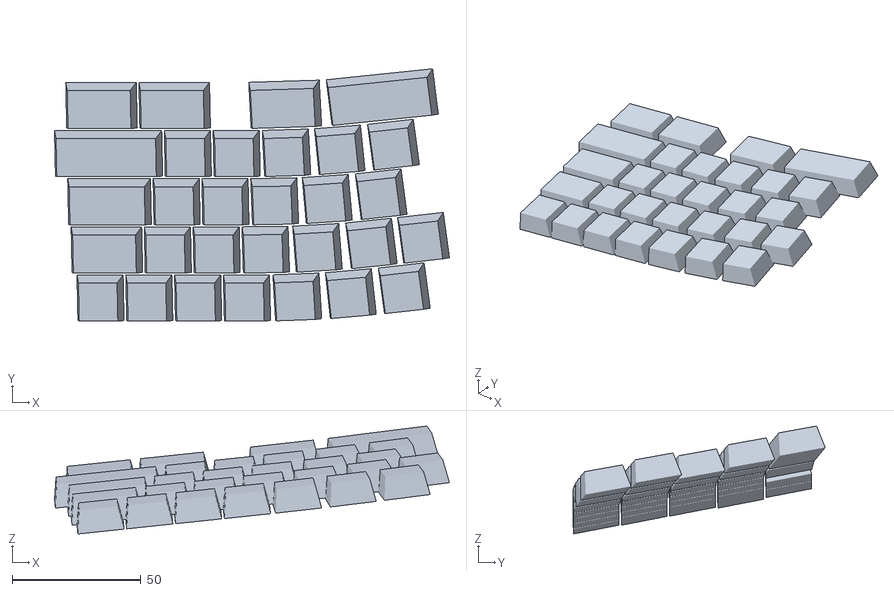
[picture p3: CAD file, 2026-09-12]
case/fusion360/generated/LeftKeycaps-placed.stl
153.4 x 98.0 x 41.9

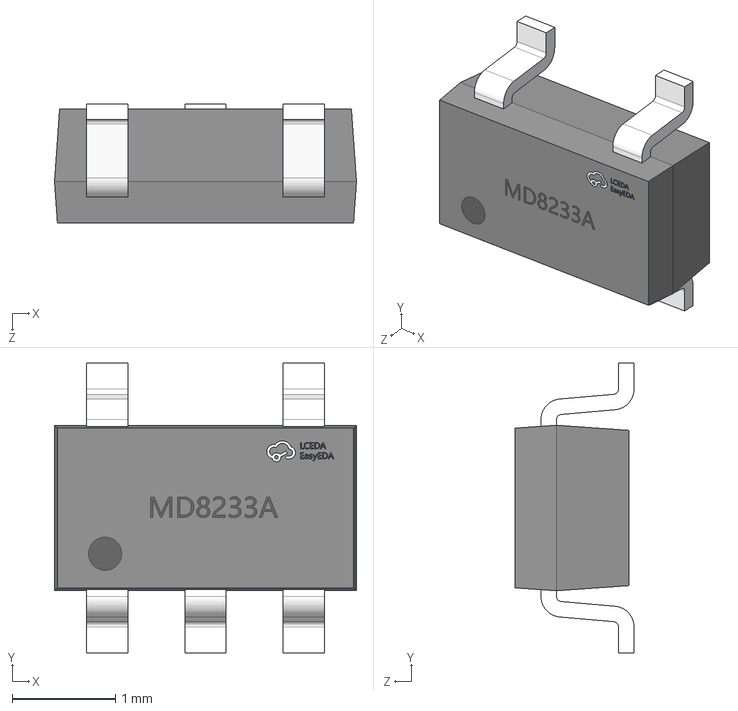
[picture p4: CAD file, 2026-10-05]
case/fusion360/models/official/TI_TLV75733PDBVR_C485517.step
2.92 x 2.80 x 1.15 mm

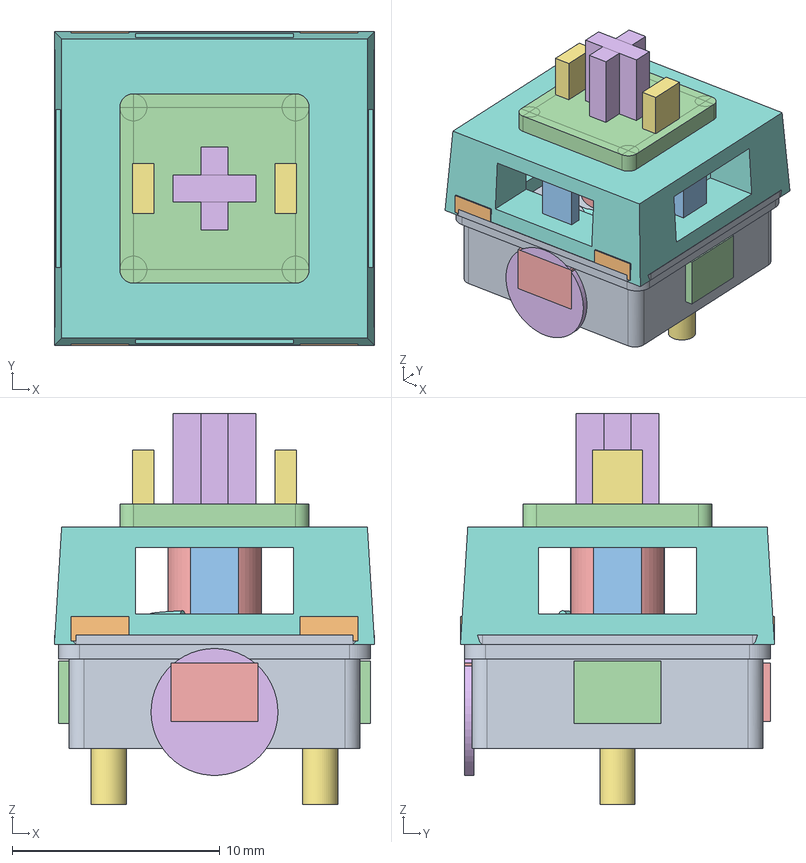
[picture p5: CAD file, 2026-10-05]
case/fusion360/models/reference/gateron-ks20-magnetic-jade/Gateron-KS20-Magnetic-Jade-detailed-reference.step
15.4 x 15.1 x 18.8 mm
KS20 bottom housing
KS20 transparent top housing
KS20 wall stem
KS20 spring
KS20 centre magnet

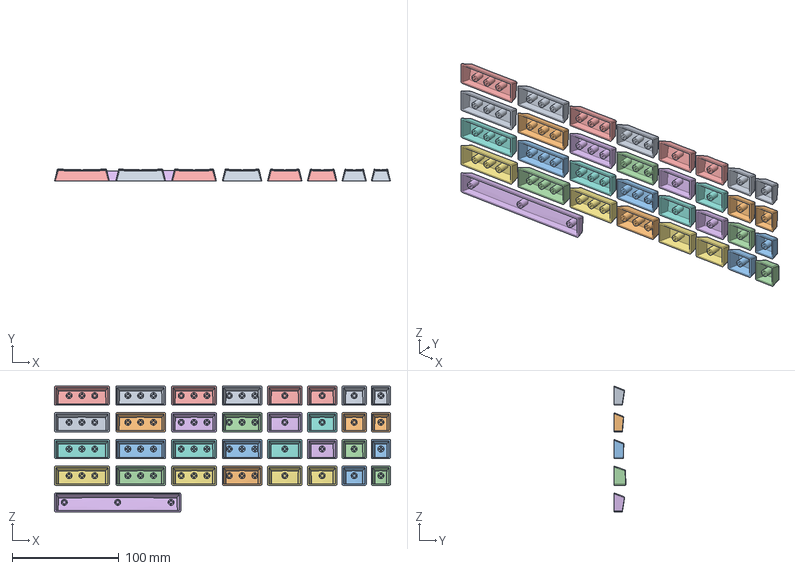
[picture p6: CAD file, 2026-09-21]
case/fusion360/models/reference/gmk-cyl/Cherry-MX-keycaps.step
314.7 x 11.2 x 118.0 mm
1x1 R1 v23
1x1 R2 v8
1x1 R3 v8
1x1 R4 v6
1x1.5 R1 v4
1x1.5 R3 v6
1x1.5 R4 v5
1x1.5 R2 v5
1x1.25 R1 v7
1x1.25 R2 v4
1x1.25 R4 v6
1x1.25 R3 v5
1x1.75 R1 v6
1x1.75 R2 v4
1x1.75 R4 v4
1x1.75 R3 v5
1x2 R1 v6
1x2 R4 v6
1x2 R3 v6
1x2 R2 v6
1x2.25 R1 v6
1x2.25 R2 v6
1x2.25 R4 v6
1x2.25 R3 v6
1x2.5 R1 v5
1x2.5 R2 v7
1x2.5 R3 v6
1x2.5 R4 v5
1x2.75 R1 v3
1x6.25 R1 v6
1x2.75 R4 v3
1x2.75 R3 v3
1x2.75 R2 v4

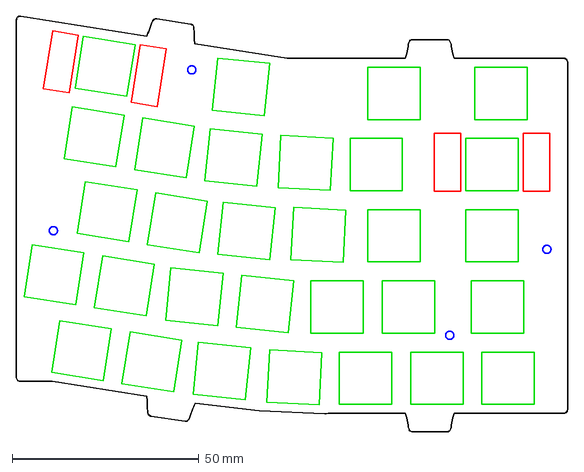
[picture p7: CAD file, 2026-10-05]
plate/Symm60HE-plate-three-key-left-wkl-right-right.dxf
147.4 x 111.2 mm

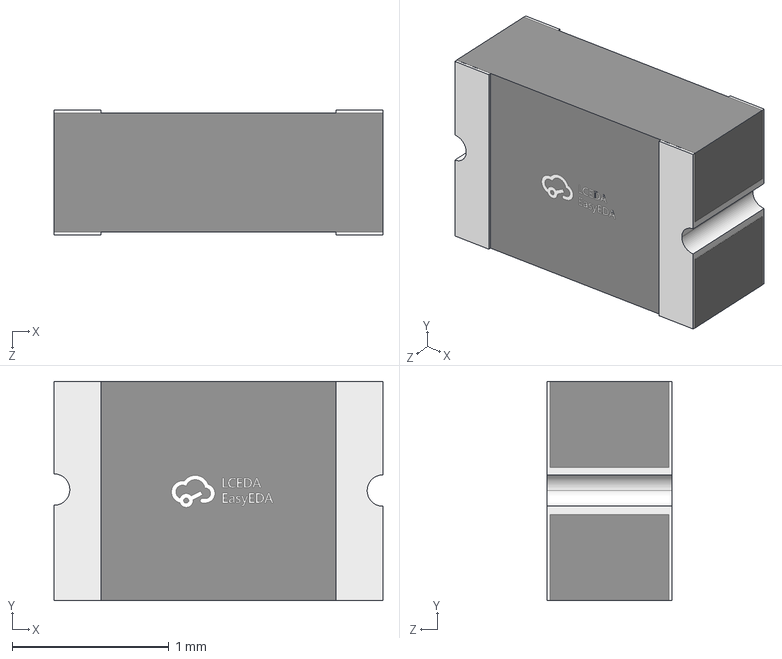
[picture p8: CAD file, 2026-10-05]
case/fusion360/models/official/BHFUSE_BSMD0805-050-24V_C910822.step
2.10 x 1.40 x 0.8 mm

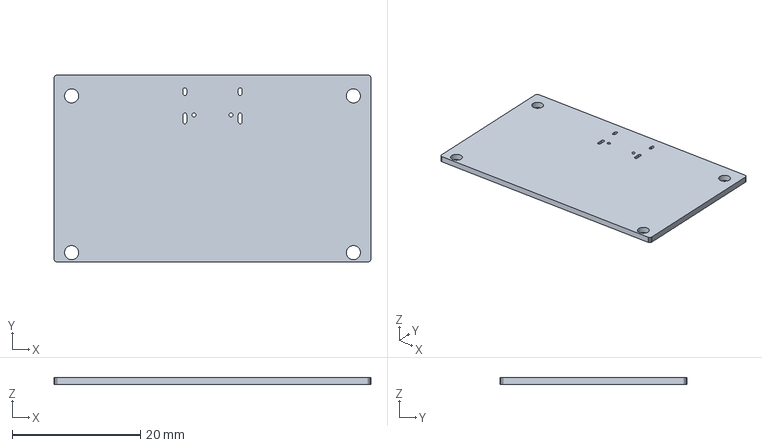
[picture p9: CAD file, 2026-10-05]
case/fusion360/Symm60HE-DaughterboardPCB.step
49.5 x 29.2 x 1.11 mm

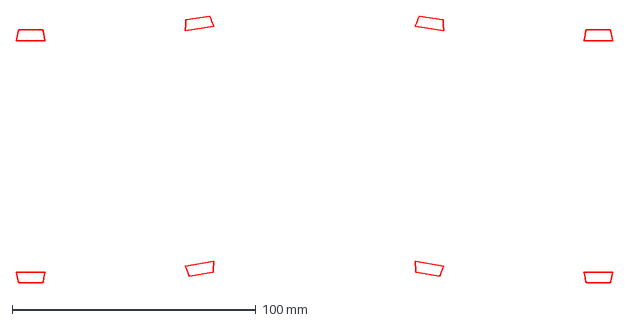
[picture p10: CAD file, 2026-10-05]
plate/Symm60HE-gasket-pads.dxf
244.8 x 109.5 mm

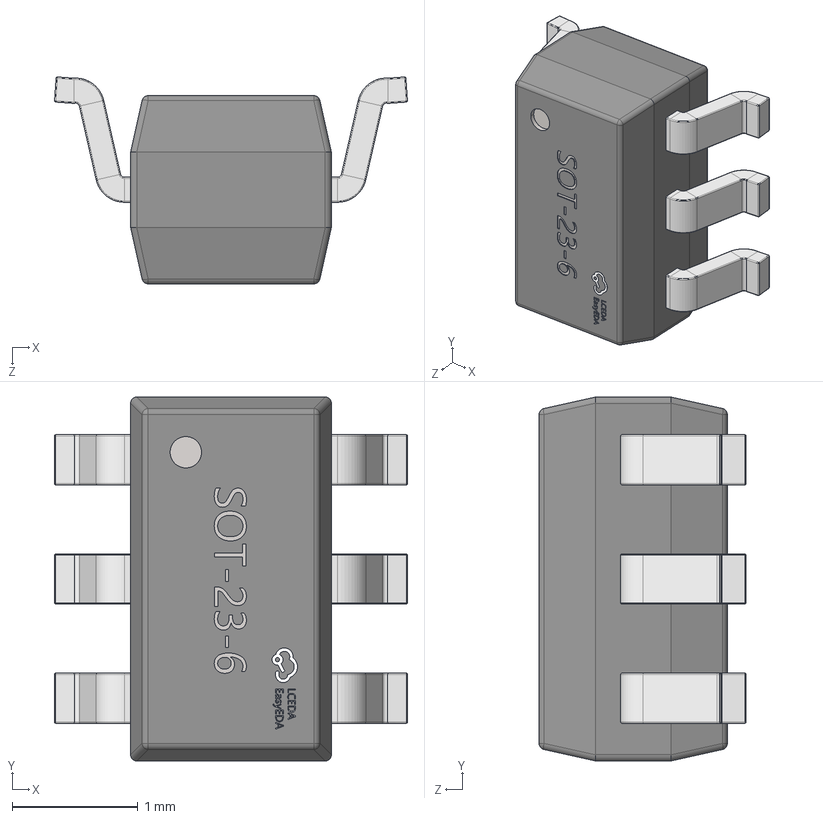
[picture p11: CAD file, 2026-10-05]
case/fusion360/models/official/ST_USBLC6-2SC6_C7519.step
2.81 x 2.90 x 1.65 mm

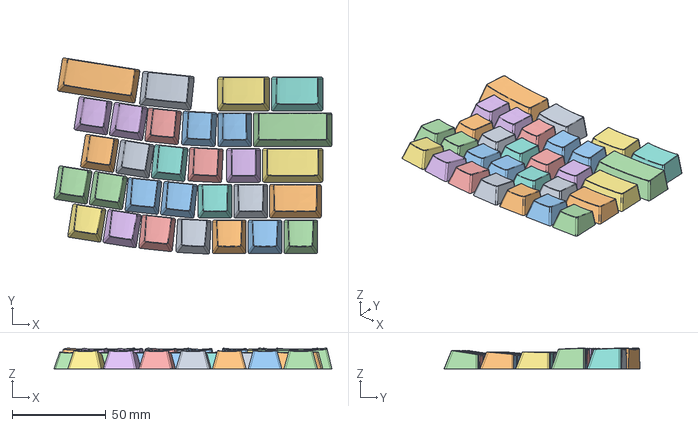
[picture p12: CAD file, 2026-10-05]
case/fusion360/Symm60HE-RightKeycaps.step
148.3 x 104.6 x 11.2 mm

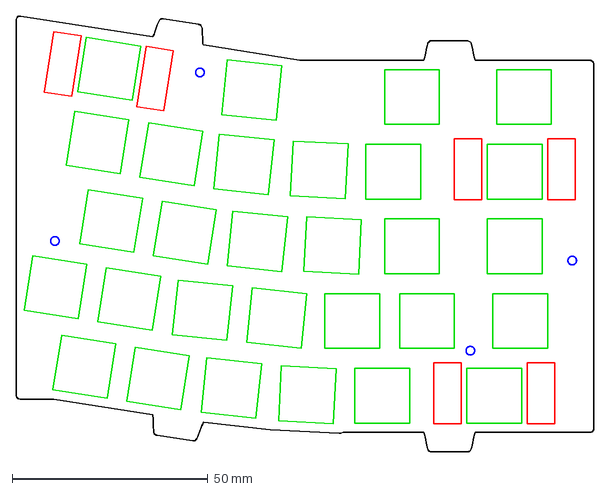
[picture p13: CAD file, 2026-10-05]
plate/Symm60HE-plate-three-key-left-wkl-right-bs2-right.dxf
147.4 x 111.2 mm

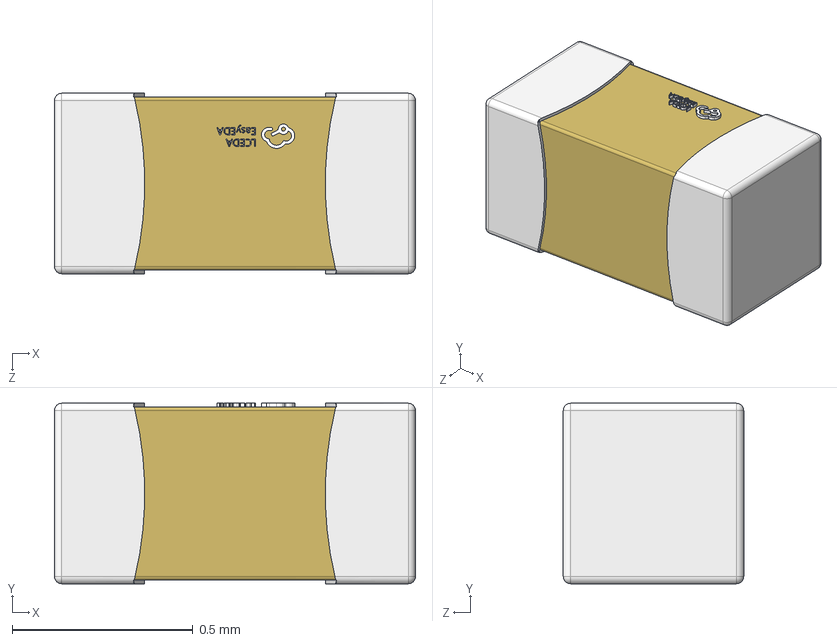
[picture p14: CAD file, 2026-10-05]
case/fusion360/models/official/SAMSUNG_CL05B104KO5NNNC_C1525.step
1.00 x 0.5 x 0.5 mm

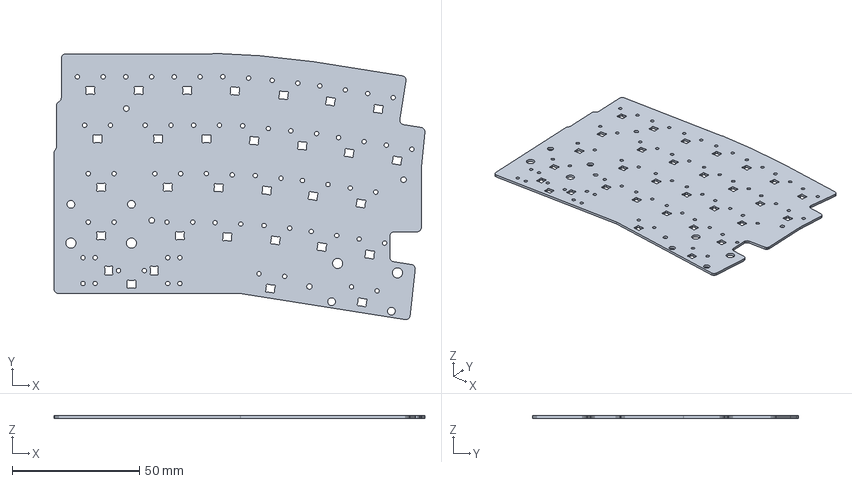
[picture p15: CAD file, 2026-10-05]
case/fusion360/Symm60HE-LeftPCB.step
145.9 x 104.7 x 1.11 mm

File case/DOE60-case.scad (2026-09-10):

// DOE60 case -- generated, parametric.  Units mm.
// Bottom flat on the desk; top face inclined at the DOE's typing angle.

typing_angle_deg  = 11.0;   // DOE spec: 11 deg
lateral_tent_deg  = 0.0;    // DOE quotes none; raise for a tented build
front_h           = 18.0;   // DOE front height is 14.7-20.1 mm
back_h            = 42.14;

floor_t      = 3.0;
ledge_w      = 3.0;
plate_t      = 1.5;
gasket_t     = 1.5;
wall         = 3.0;
pcb_standoff = 4.0;
plate_to_pcb = 5.0;   // MX plate-to-PCB
pcb_t        = 1.6;
usb_w        = 12.0;
db_w         = 56.0;
db_h         = 26.0;
usb_h        = 7.0;

y_front = -112.418;
y_back  = 11.764;
axis_x  = 151.209;

outer = [[-17.478,-76.165],[-17.477,-76.257],[-17.460,-76.793],[-17.456,-76.885],[-17.454,-76.920],[-17.437,-77.103],[-17.306,-78.167],[-17.278,-78.349],[-17.272,-78.383],[-17.253,-78.473],[-17.139,-78.997],[-17.118,-79.087],[-12.371,-98.075],[-12.352,-98.147],[-12.237,-98.566],[-12.216,-98.637],[-12.208,-98.663],[-12.161,-98.805],[-11.868,-99.622],[-11.754,-99.896],[-11.382,-100.680],[-11.242,-100.942],[-10.793,-101.686],[-10.628,-101.933],[-10.108,-102.628],[-9.919,-102.857],[-9.333,-103.498],[-9.122,-103.707],[-8.476,-104.287],[-8.245,-104.474],[-7.545,-104.987],[-7.296,-105.150],[-6.549,-105.592],[-6.286,-105.730],[-5.498,-106.095],[-5.222,-106.206],[-4.402,-106.491],[-4.117,-106.575],[-3.273,-106.778],[-2.981,-106.832],[-2.121,-106.951],[-1.973,-106.967],[-1.946,-106.970],[-1.872,-106.975],[-1.439,-107.002],[-1.364,-107.006],[142.920,-112.408],[142.948,-112.409],[143.111,-112.413],[143.139,-112.414],[143.161,-112.414],[143.189,-112.415],[143.352,-112.416],[143.380,-112.416],[156.654,-112.418],[156.682,-112.417],[156.847,-112.416],[156.875,-112.416],[156.896,-112.415],[156.925,-112.414],[157.089,-112.410],[157.117,-112.409],[301.402,-107.006],[301.476,-107.002],[301.909,-106.975],[301.984,-106.970],[302.011,-106.967],[302.159,-106.951],[303.019,-106.832],[303.311,-106.777],[304.155,-106.575],[304.440,-106.491],[305.260,-106.206],[305.535,-106.095],[306.323,-105.730],[306.586,-105.591],[307.334,-105.150],[307.582,-104.987],[308.283,-104.474],[308.513,-104.287],[309.160,-103.707],[309.371,-103.498],[309.956,-102.857],[310.146,-102.628],[310.665,-101.933],[310.831,-101.686],[311.279,-100.942],[311.420,-100.680],[311.792,-99.896],[311.906,-99.622],[312.199,-98.805],[312.245,-98.663],[312.253,-98.637],[312.274,-98.566],[312.390,-98.147],[312.409,-98.075],[317.156,-79.087],[317.177,-78.997],[317.291,-78.473],[317.309,-78.383],[317.315,-78.349],[317.343,-78.167],[317.474,-77.103],[317.491,-76.920],[317.493,-76.885],[317.498,-76.793],[317.514,-76.257],[317.516,-76.165],[317.516,-0.028],[317.515,0.046],[317.504,0.476],[317.501,0.550],[317.500,0.576],[317.489,0.723],[317.405,1.579],[317.362,1.870],[317.194,2.714],[317.122,2.999],[316.873,3.822],[316.774,4.099],[316.444,4.894],[316.319,5.160],[315.913,5.919],[315.762,6.171],[315.284,6.886],[315.109,7.123],[314.563,7.787],[314.365,8.005],[313.757,8.614],[313.539,8.811],[312.874,9.357],[312.638,9.532],[311.923,10.010],[311.670,10.161],[310.912,10.567],[310.646,10.693],[309.851,11.022],[309.574,11.121],[308.751,11.370],[308.466,11.442],[307.622,11.610],[307.331,11.653],[306.475,11.737],[306.328,11.748],[306.302,11.749],[306.228,11.752],[305.798,11.763],[305.724,11.764],[-5.687,11.764],[-5.761,11.763],[-6.191,11.752],[-6.264,11.749],[-6.291,11.748],[-6.438,11.737],[-7.294,11.653],[-7.585,11.610],[-8.428,11.442],[-8.714,11.370],[-9.537,11.121],[-9.814,11.022],[-10.608,10.693],[-10.875,10.567],[-11.633,10.161],[-11.885,10.010],[-12.601,9.532],[-12.837,9.357],[-13.502,8.811],[-13.720,8.614],[-14.328,8.005],[-14.526,7.787],[-15.071,7.123],[-15.247,6.886],[-15.724,6.171],[-15.876,5.919],[-16.281,5.160],[-16.407,4.894],[-16.736,4.099],[-16.835,3.822],[-17.085,2.999],[-17.156,2.714],[-17.324,1.870],[-17.367,1.579],[-17.452,0.723],[-17.463,0.576],[-17.464,0.550],[-17.467,0.476],[-17.477,0.046],[-17.478,-0.028]];
inner = [[-14.478,-76.165],[-14.462,-76.701],[-14.459,-76.736],[-14.328,-77.801],[-14.322,-77.835],[-14.208,-78.359],[-9.461,-97.348],[-9.345,-97.766],[-9.337,-97.793],[-9.044,-98.610],[-8.672,-99.394],[-8.224,-100.138],[-7.704,-100.833],[-7.119,-101.474],[-6.473,-102.054],[-5.772,-102.567],[-5.024,-103.008],[-4.237,-103.373],[-3.417,-103.658],[-2.573,-103.860],[-1.713,-103.979],[-1.685,-103.981],[-1.252,-104.008],[143.032,-109.410],[143.195,-109.414],[143.217,-109.415],[143.380,-109.416],[156.655,-109.418],[156.819,-109.416],[156.840,-109.416],[157.005,-109.411],[301.290,-104.008],[301.723,-103.981],[301.750,-103.979],[302.610,-103.860],[303.454,-103.658],[304.274,-103.373],[305.062,-103.008],[305.810,-102.566],[306.510,-102.054],[307.156,-101.474],[307.742,-100.833],[308.261,-100.138],[308.709,-99.394],[309.082,-98.610],[309.375,-97.793],[309.383,-97.766],[309.498,-97.348],[314.245,-78.359],[314.360,-77.835],[314.366,-77.801],[314.497,-76.736],[314.499,-76.701],[314.516,-76.165],[314.516,-0.028],[314.505,0.402],[314.504,0.429],[314.419,1.285],[314.252,2.128],[314.002,2.951],[313.673,3.746],[313.267,4.504],[312.790,5.219],[312.244,5.884],[311.636,6.492],[310.971,7.038],[310.256,7.516],[309.498,7.921],[308.703,8.250],[307.880,8.500],[307.037,8.667],[306.181,8.752],[306.154,8.753],[305.724,8.764],[-5.687,8.764],[-6.117,8.753],[-6.144,8.752],[-6.999,8.667],[-7.843,8.500],[-8.666,8.250],[-9.460,7.921],[-10.219,7.516],[-10.934,7.038],[-11.599,6.492],[-12.207,5.884],[-12.752,5.219],[-13.230,4.504],[-13.635,3.746],[-13.964,2.951],[-14.214,2.128],[-14.382,1.285],[-14.466,0.429],[-14.467,0.402],[-14.478,-0.028]];

// Half-spaces parallel to the inclined top face, `drop` mm below it.
module above_plane(drop) {
    translate([0, y_front, front_h - drop])
        rotate([typing_angle_deg, 0, 0])
            translate([-2000, -50, 0]) cube([4000, 4000, 2000]);
}
module below_plane(drop) {
    translate([0, y_front, front_h - drop])
        rotate([typing_angle_deg, 0, 0])
            translate([-2000, -50, -2000]) cube([4000, 4000, 2000]);
}

module outer_wedge() {
    difference() {
        linear_extrude(back_h + 20) polygon(outer);
        above_plane(0);                       // cut the inclined top face
    }
}

// The pocket floor runs parallel to the plate, the way a wedge tray case is
// actually milled -- a flat pocket floor would leave the rear standoffs as
// 30 mm pillars.
pocket_drop = gasket_t + plate_t + plate_to_pcb + pcb_t + pcb_standoff;

module interior() {
    // main cavity: inner outline, pocket floor up to the plate underside
    intersection() {
        linear_extrude(back_h + 30) polygon(inner);
        below_plane(gasket_t + plate_t);
        above_plane(pocket_drop);
    }
    // gasket + plate rebate: wider, from the plate underside out through the top
    intersection() {
        linear_extrude(back_h + 30) offset(delta = ledge_w) polygon(inner);
        above_plane(gasket_t + plate_t);
    }
    db_pocket();
}

// The daughterboard lives in the solid under the raised back -- the only place
// in this layout with room for it, since the number rows reach too close to the
// centre for a coplanar board.  Its pocket opens upward into the main cavity so
// the two ribbons can route, and the USB cutout opens into it through the back
// wall.
db_floor = 5.0;
module db_pocket() {
    translate([axis_x - db_w/2 - 4, y_back - wall - db_h - 8, db_floor])
        cube([db_w + 8, db_h + 8, back_h]);
}

module usb_cutout() {
    translate([axis_x, y_back, floor_t + pcb_standoff])
        translate([-usb_w/2, -wall*3, 0]) cube([usb_w, wall*6, usb_h]);
}

// Standoffs rise from the flat floor and are cut off level with the PCB, which
// hangs plate_to_pcb below the plate and so shares the top face's angle.
module standoff(x, y) {
    intersection() {
        translate([x, -y, 0]) difference() {
            cylinder(h = back_h + 30, d = 6, $fn = 32);
            translate([0, 0, -0.1]) cylinder(h = back_h + 40, d = 2.0, $fn = 24);
        }
        above_plane(pocket_drop);
        below_plane(pocket_drop - pcb_standoff);
    }
}

module case_body() {
    difference() {
        outer_wedge();
        interior();
        usb_cutout();
    }
    standoff(30.00, 8.00);
    standoff(30.00, 95.00);
    standoff(111.21, 8.00);
    standoff(111.21, 100.00);
    standoff(191.21, 8.00);
    standoff(191.21, 100.00);
    standoff(284.52, 8.00);
    standoff(284.52, 95.00);
}

module case() {
    // lateral tent, if you want it: pivot about the centre line
    rotate([0, lateral_tent_deg, 0]) case_body();
}

case();

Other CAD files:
case/fusion360/Symm60HE-case-reference-assembly.step
case/fusion360/Symm60HE-LeftPCBComponents.step
case/fusion360/generated/RightKeycaps-placed.stl
plate/Symm60HE-plate-universal-right.dxf
case/fusion360/Symm60HE-DaughterboardPCBComponents.step
case/fusion360/Symm60HE-LeftKeycaps.step
case/fusion360/Symm60HE-LeftPlate.step
case/fusion360/Symm60HE-LeftRibbonCable.step
case/fusion360/Symm60HE-LeftSwitches.step
case/fusion360/Symm60HE-RightPCB.step
case/fusion360/Symm60HE-RightPCBComponents.step
case/fusion360/Symm60HE-RightPlate.step
case/fusion360/Symm60HE-RightRibbonCable.step
case/fusion360/Symm60HE-RightSwitches.step
case/fusion360/Symm60HE-reference-assembly.FCStd
case/fusion360/models/official/ARTERY_AT32F405RCT7_C47090415.step
case/fusion360/models/official/BOOMELE_1.0-12P_C20111.step
case/fusion360/models/official/CCTC_TCC0603X5R106M6R3CT_C380318.step
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

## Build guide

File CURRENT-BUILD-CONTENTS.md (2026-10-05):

# Current build contents

This directory was reduced on 2026-10-05 to the inputs, validation tools and
final outputs for the current ribbon-connected Symm60HE design.

## Retained

- Universal and eight fixed-layout combined PCB/schematic panel projects.
- Compact daughterboard project.
- Half-board mechanical/generator inputs required by plate and 3D generation.
- Current JLCPCB Gerber/BOM/CPL packages and verification reports.
- Nine plate pairs and their matching Poron gasket-pad DXFs.
- Current populated FreeCAD/Fusion/STEP reference assembly, separate named
  bodies, verified component models and Fusion import script.
- Symm60HE AT32F405 firmware source and distributable BIN/HEX/ELF artifacts.
- Only the scripts used by the supported current build and validation path.
- Git metadata, licensing, provenance and build instructions.

## Recoverable archive

Removed files were moved, not irreversibly erased, to the sibling directory:

`../Symm60HE-removed-2026-10-05-current-build-cleanup/`

That archive contains historical pogo projects/releases, retired case and
tenting concepts, rendered galleries, CAD intermediates, PlatformIO and Python
caches, obsolete reports, unused keyboard targets, and one-time routing/repair
scripts. Nothing in the supported `./build.sh` path reads from the archive.

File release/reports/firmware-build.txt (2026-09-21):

Symm60HE firmware release build
Date: 2026-09-18
Target: symm60he
MCU/board: AT32F405RCT7 / genericAT32F405RCT7
Framework: at32firmlib
Python: 3.14.3
PlatformIO Core: 6.1.18
Result: SUCCESS (clean build)
Flash: 34168 / 262144 bytes (13.0%)
RAM: 14072 / 104448 bytes (13.5%)
firmware.bin size: 34176 bytes
firmware.bin SHA-256: f5445f886bdf41b6ce2b36ae6a61d5080814ca05aa73ed53d9b78db8c9a92dbd
firmware.elf size: 67476 bytes
firmware.elf SHA-256: 967df57b4fdfa330fff9e75d4f36f569ca1c8c493ea02cd6386b07f311827e79

Build procedure:
1. Regenerate firmware/libhmk/keyboards/symm60he from the released channel,
   switch and sensor-alias maps with tools/mkfirmware.py.
2. Copy firmware/libhmk and the project Python environment to a temporary path
   without spaces.
3. Run `python setup.py -k symm60he`.
4. Run `python -m platformio run -e symm60he -t clean`.
5. Run `python -m platformio run -e symm60he`.
6. Copy firmware.bin and firmware.elf from the clean build into firmware/build.

The link completed successfully. The toolchain emitted its standard newlib
nano notices for unimplemented host-style _close/_lseek/_read/_write syscalls
and a LOAD-segment RWX warning; neither was promoted to an error. No source
compiler warning or build failure was reported.

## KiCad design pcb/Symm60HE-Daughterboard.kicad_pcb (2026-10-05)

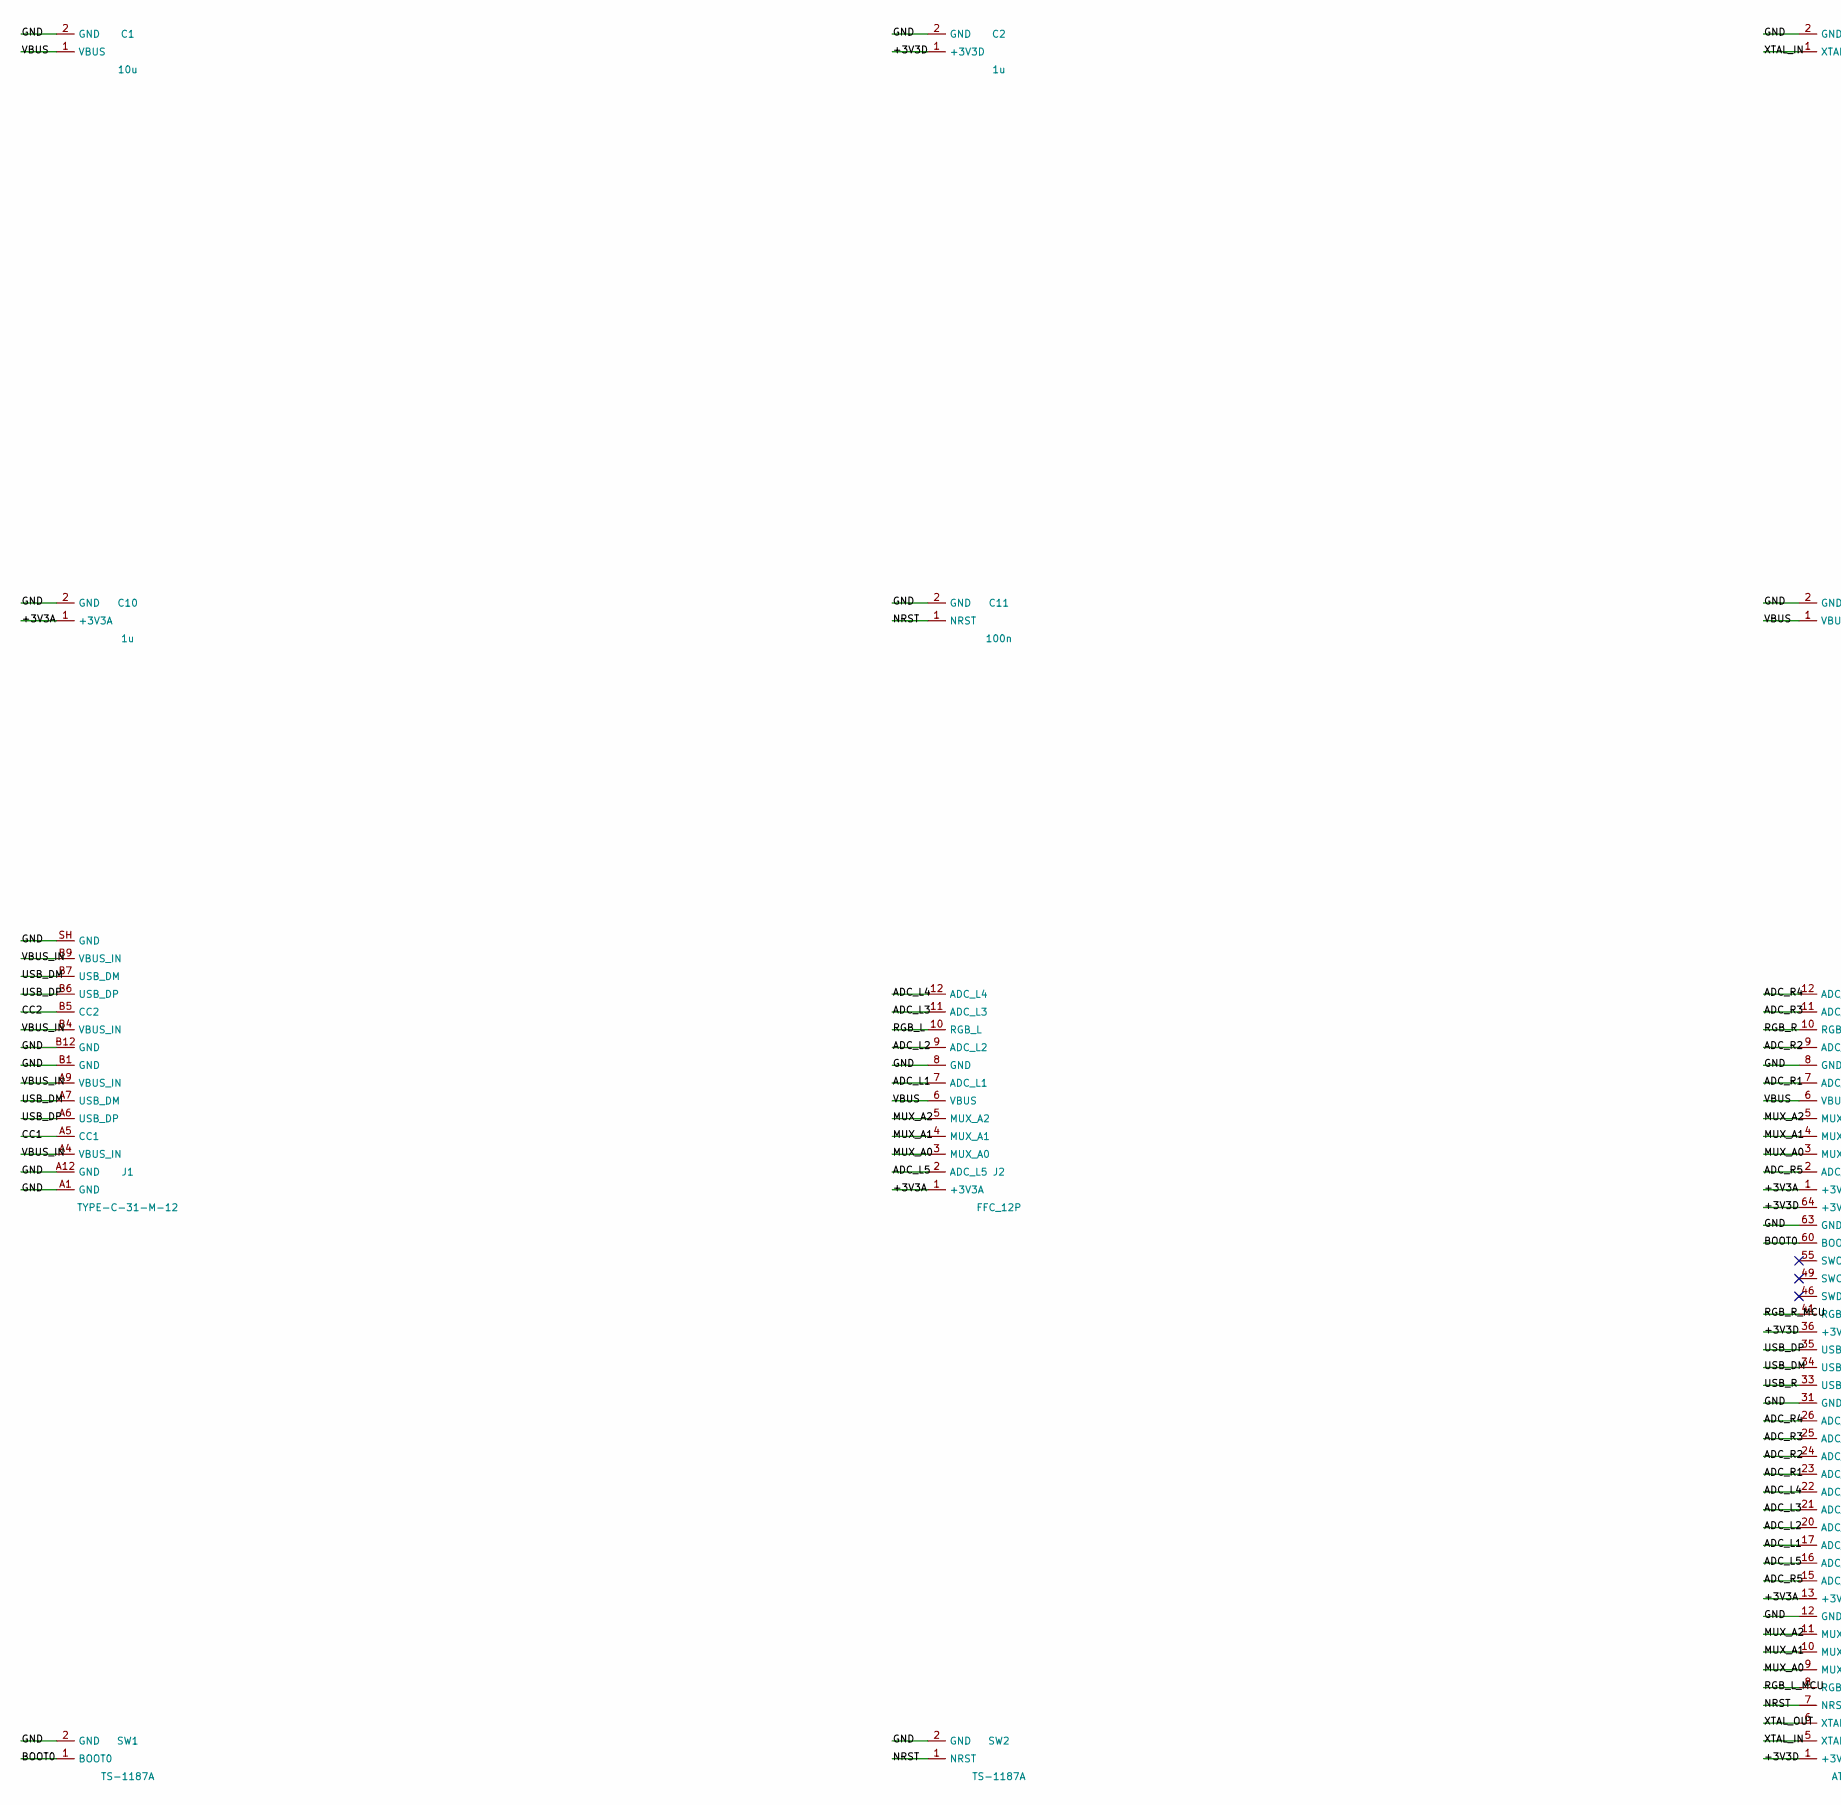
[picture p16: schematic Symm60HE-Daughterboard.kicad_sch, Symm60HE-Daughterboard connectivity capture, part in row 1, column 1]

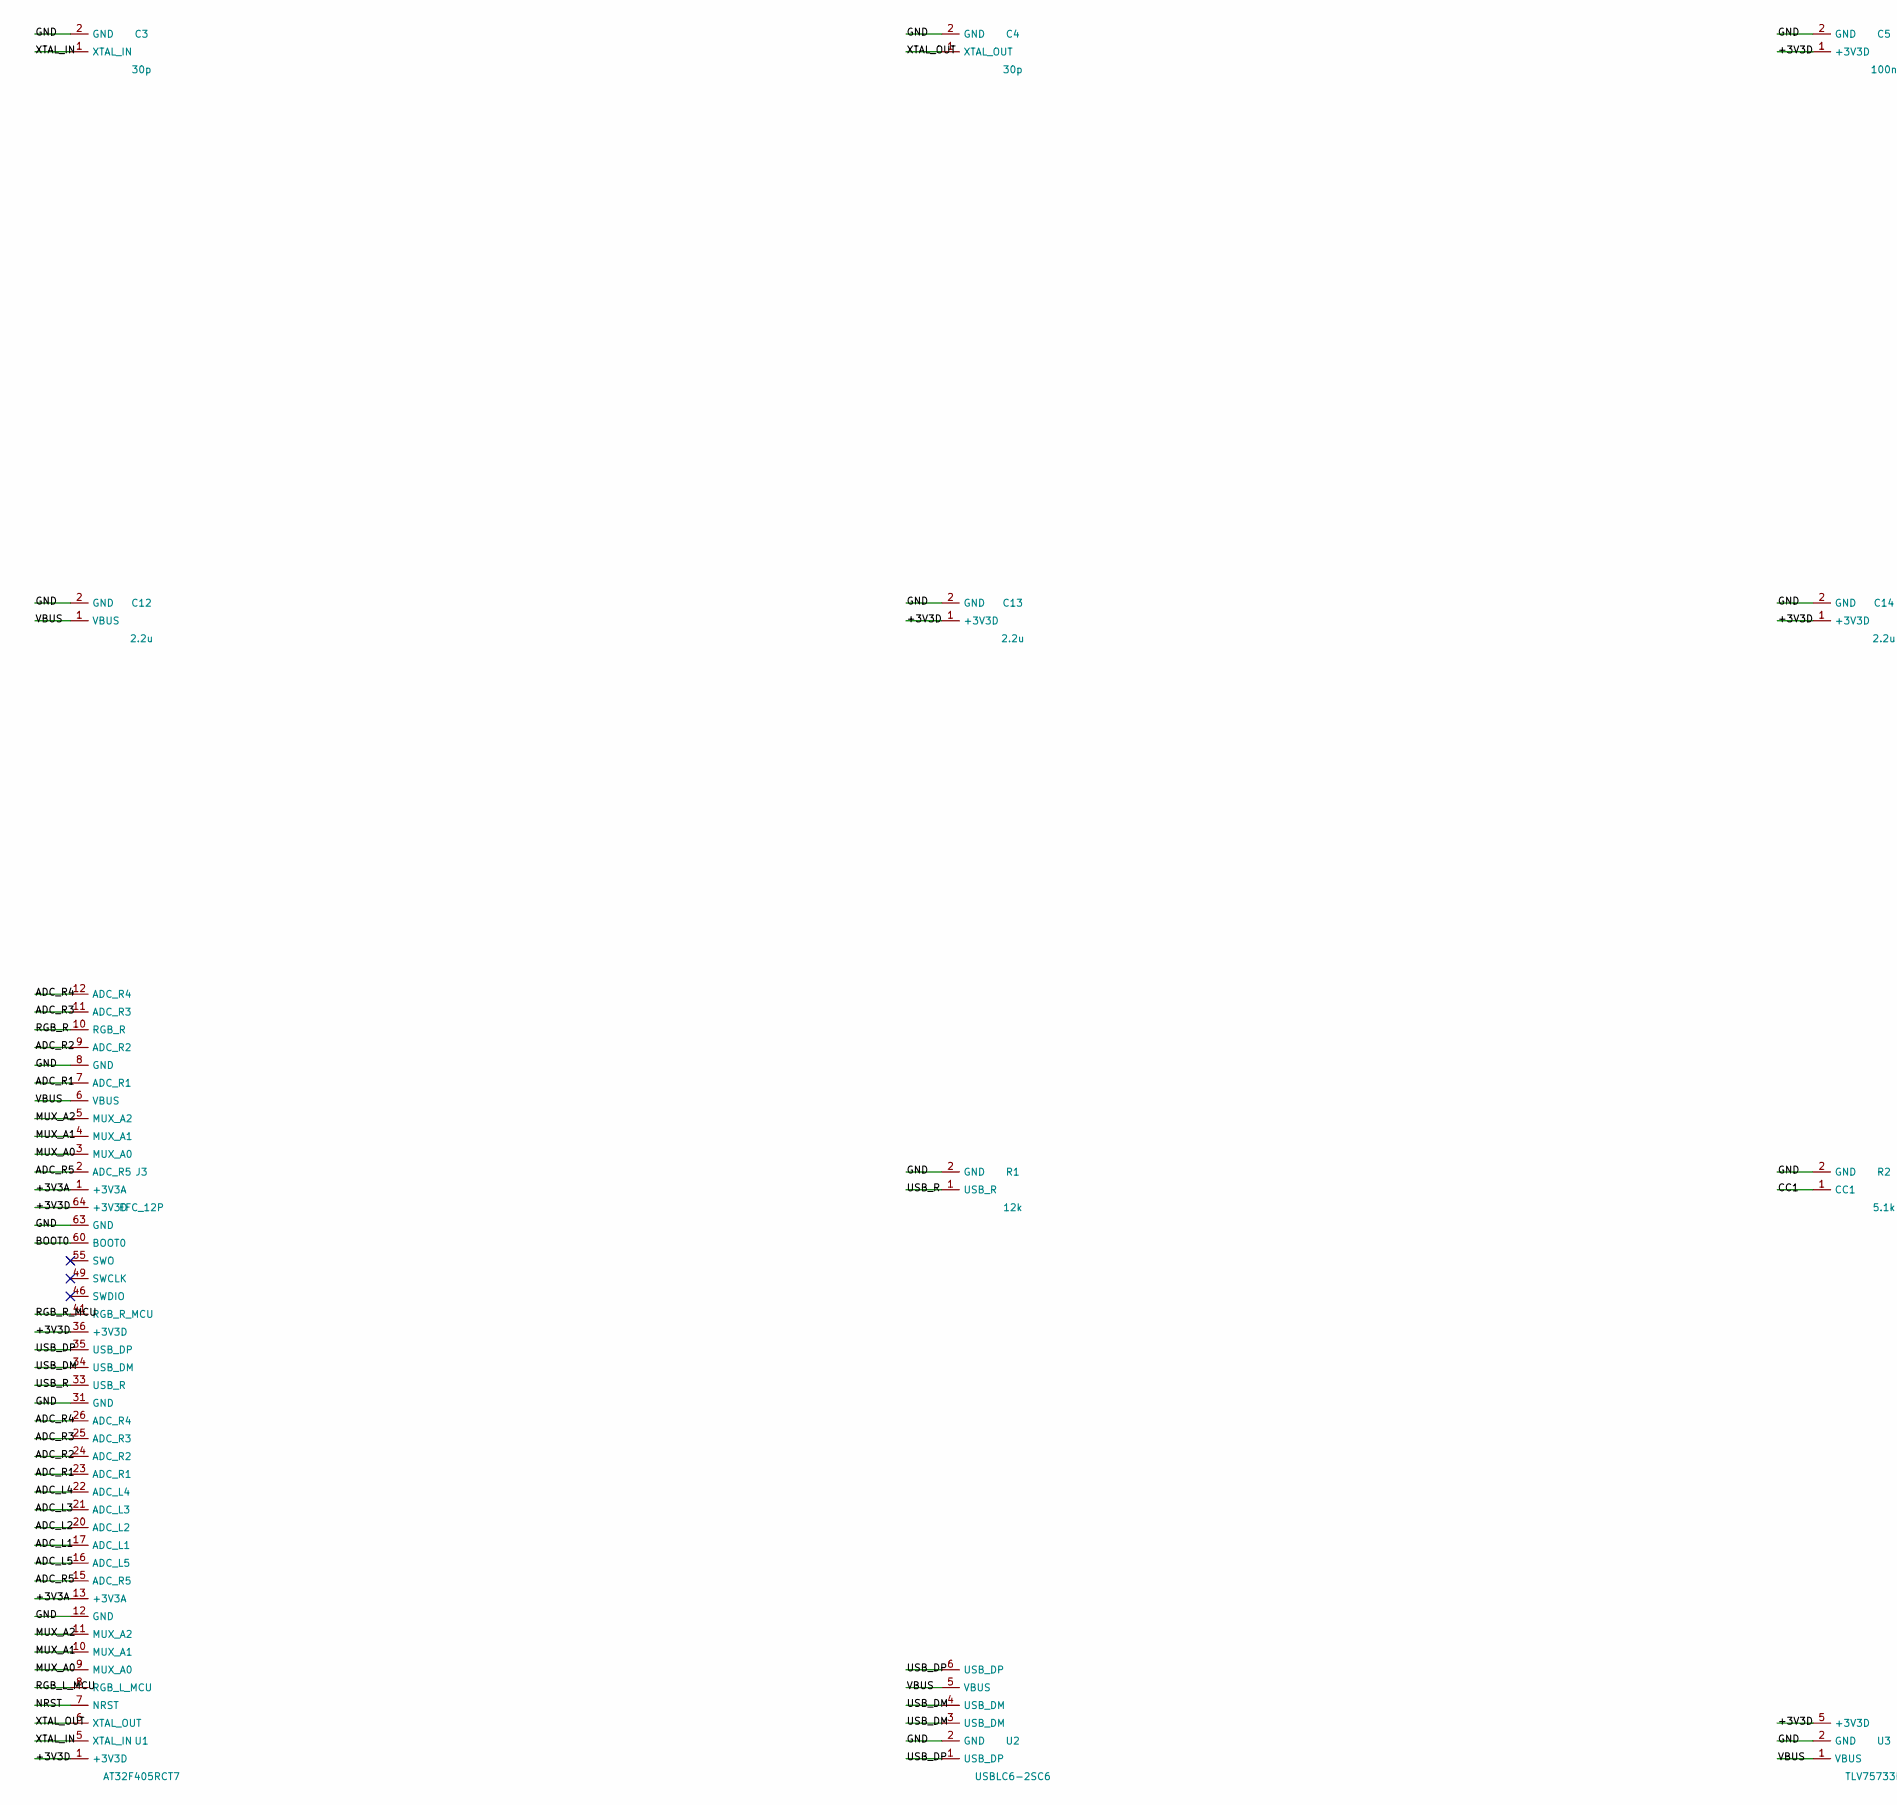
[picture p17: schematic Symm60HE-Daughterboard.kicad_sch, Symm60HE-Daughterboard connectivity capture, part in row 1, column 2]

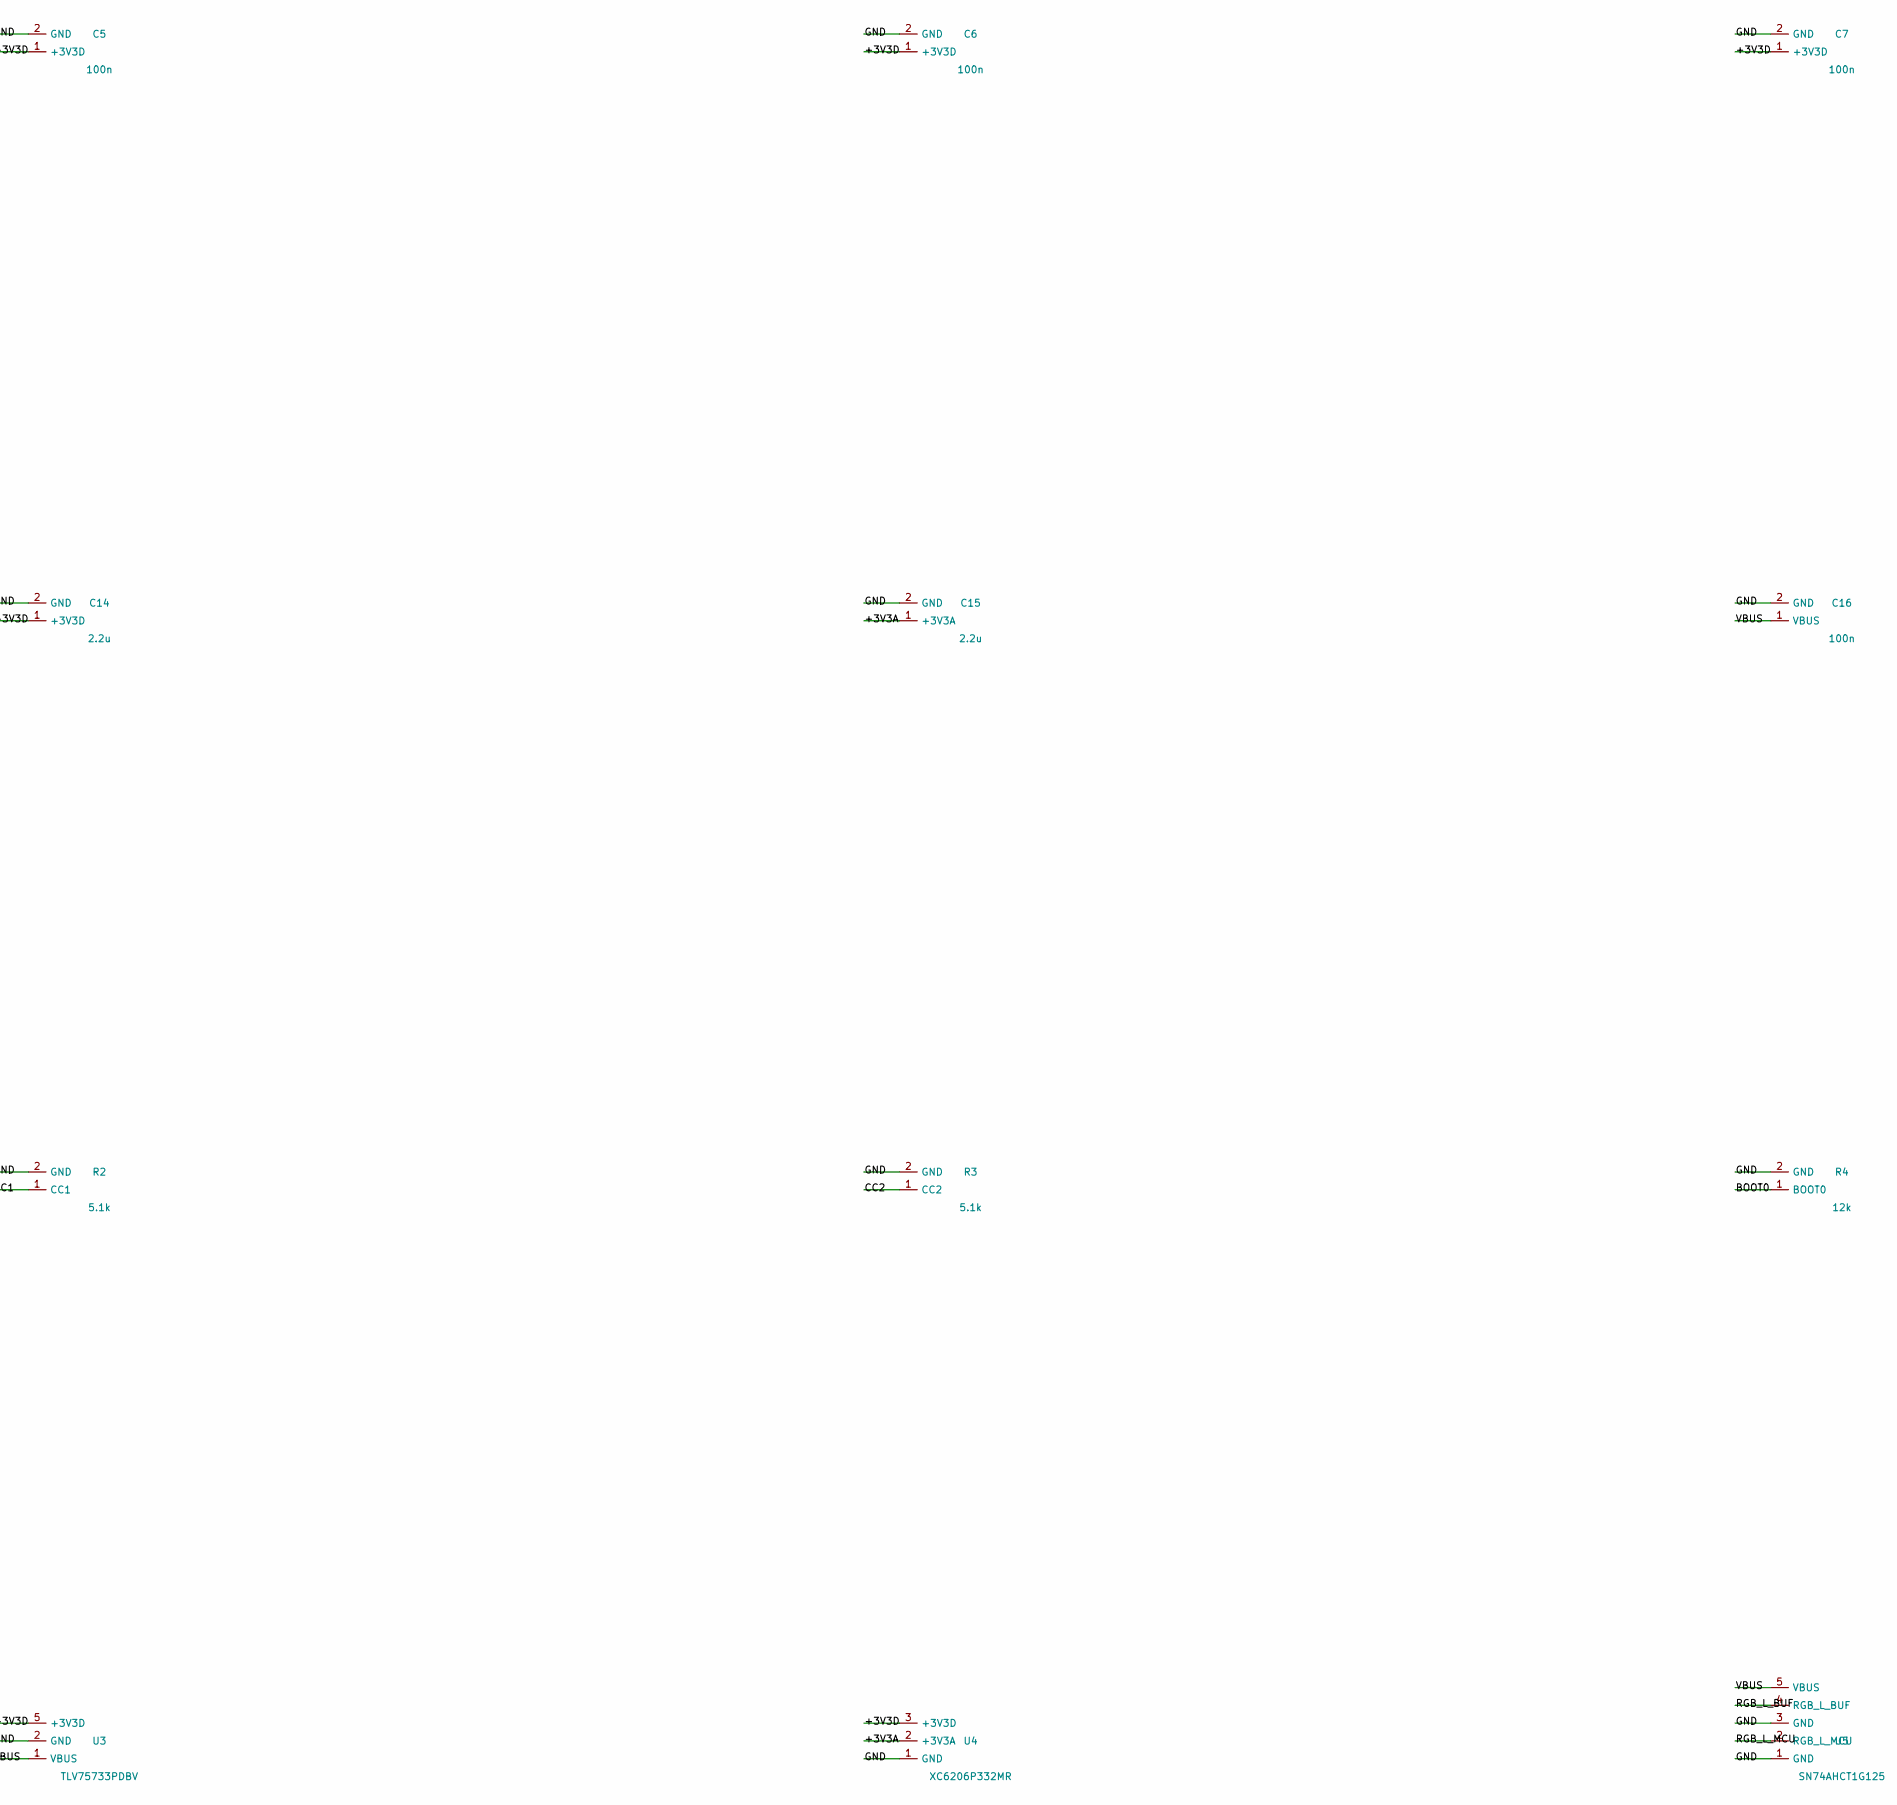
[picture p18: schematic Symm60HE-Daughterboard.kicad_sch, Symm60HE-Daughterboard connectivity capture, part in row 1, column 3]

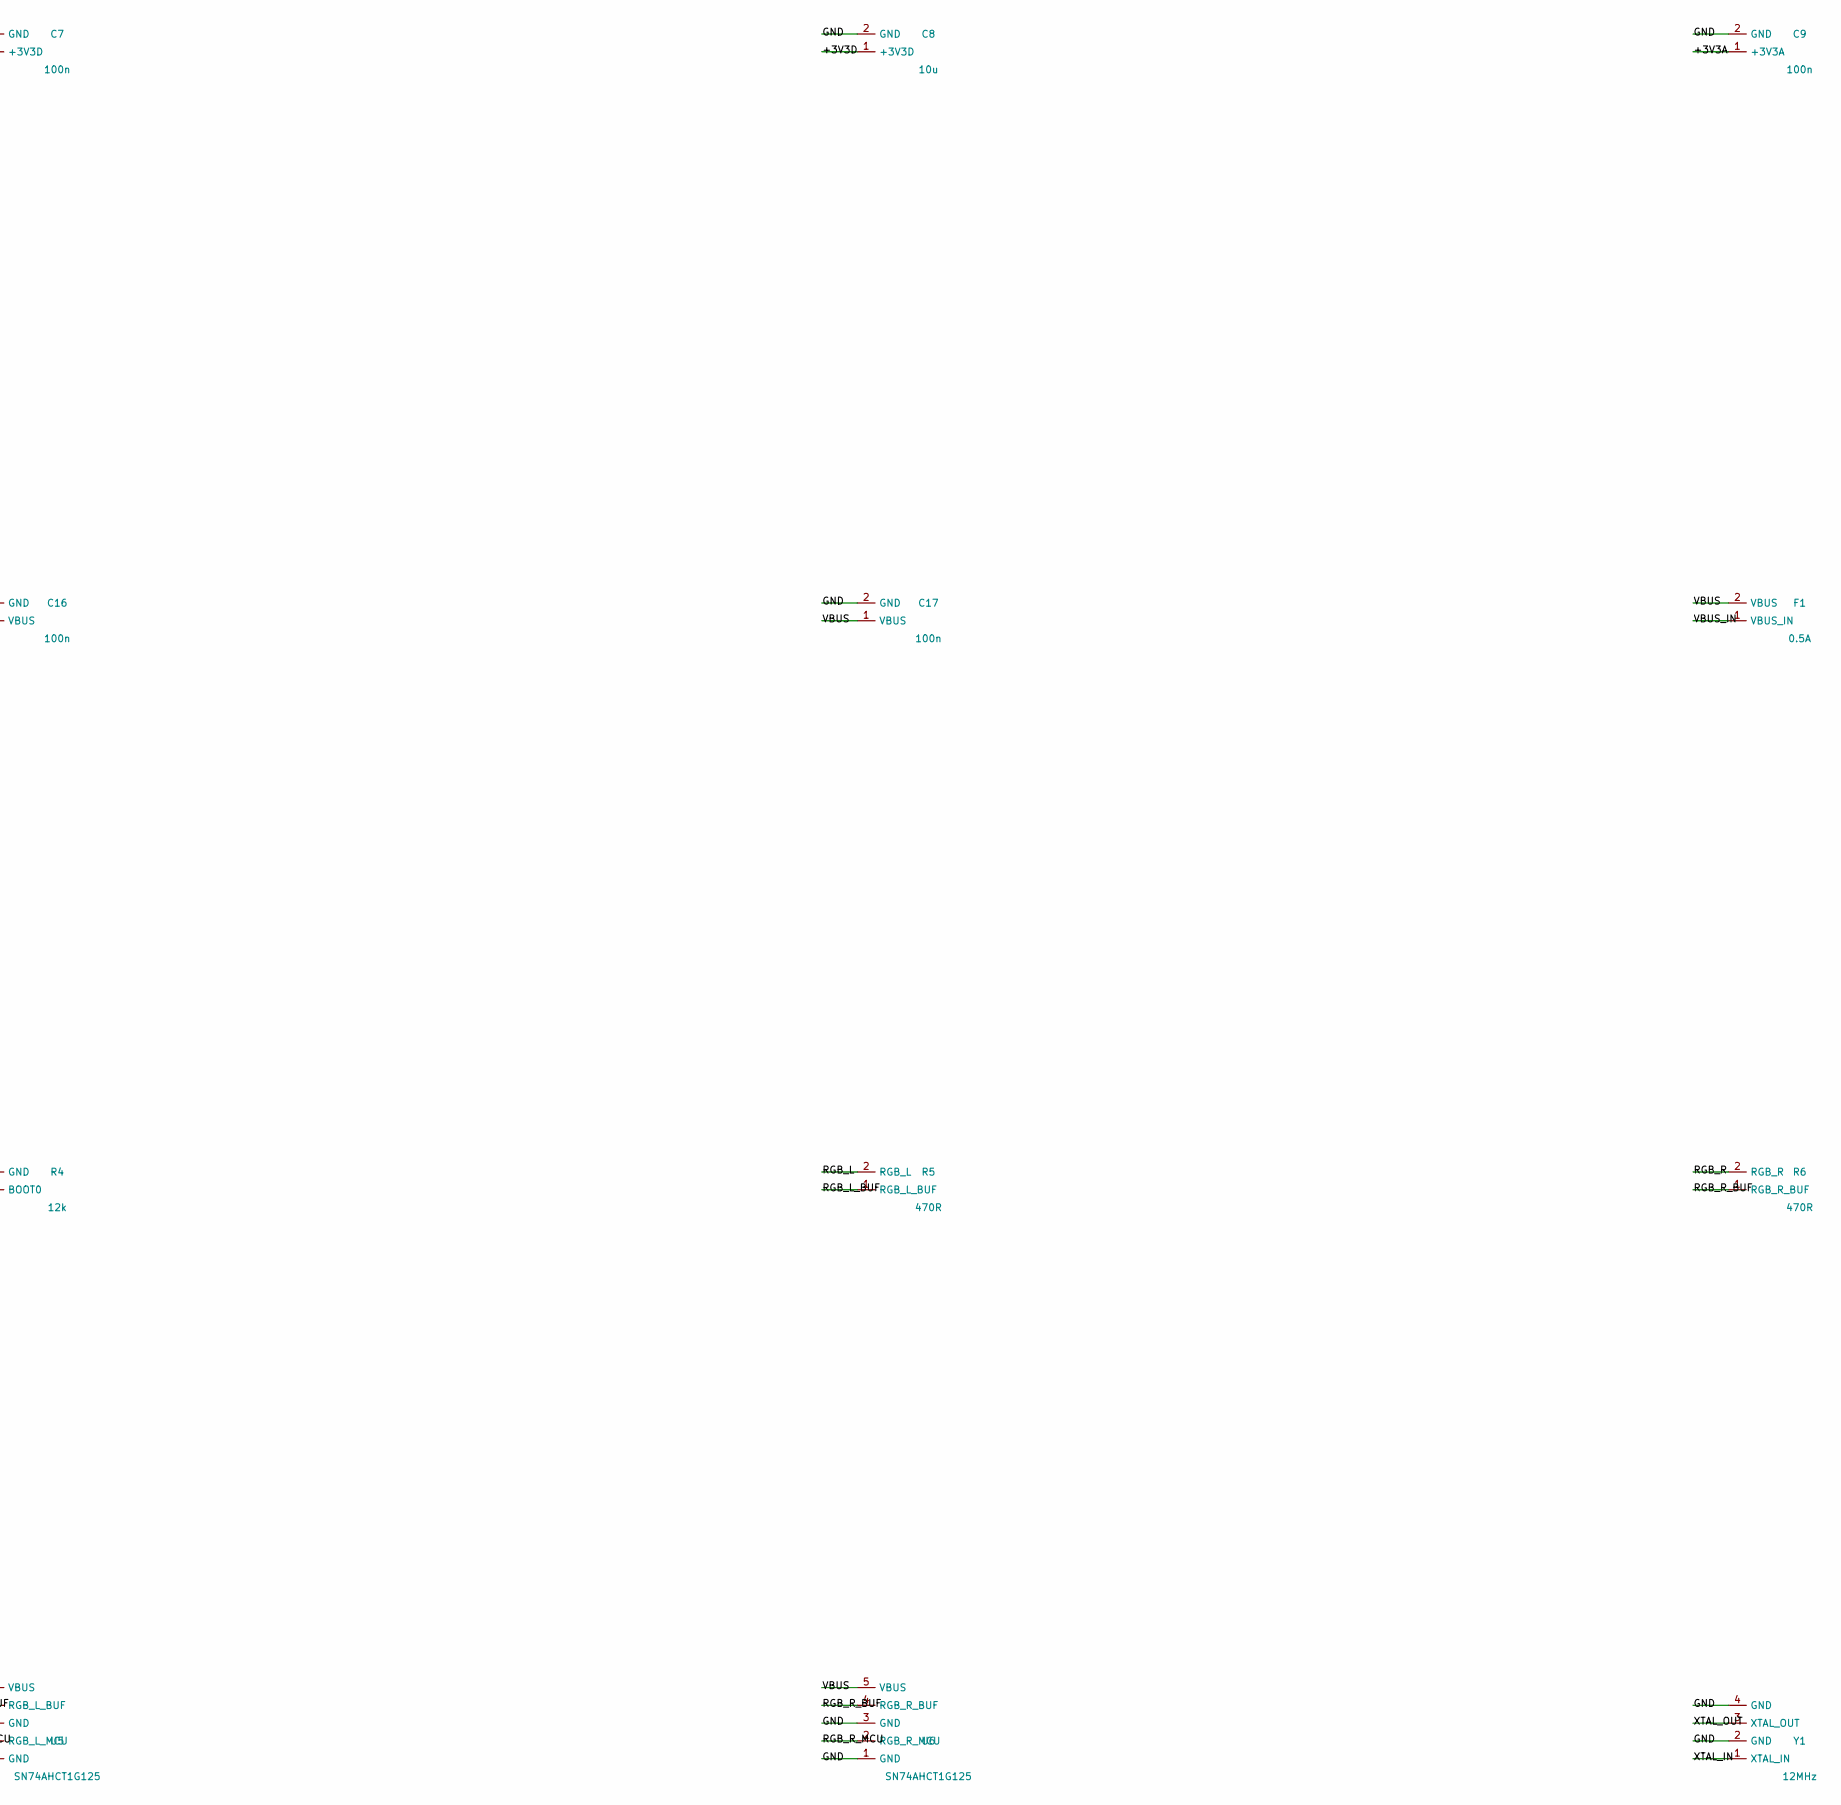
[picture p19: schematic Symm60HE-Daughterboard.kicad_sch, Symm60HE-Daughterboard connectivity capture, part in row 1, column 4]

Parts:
C1, C8: 10u
C2, C10: 1u
C3, C4: 30p
C5, C6, C7, C9, C11, C16, C17: 100n
C12, C13, C14, C15: 2.2u
F1: 0.5A
J1: TYPE-C-31-M-12
J2, J3: FFC_12P
R1, R4: 12k
R2, R3: 5.1k
R5, R6: 470R
SW1, SW2: TS-1187A
U1: AT32F405RCT7
U2: USBLC6-2SC6
U3: TLV75733PDBV
U4: XC6206P332MR
U5, U6: SN74AHCT1G125
Y1: 12MHz

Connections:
+3V3A: C9.1 (+3V3A), C10.1 (+3V3A), C15.1 (+3V3A), J2.1 (+3V3A), J3.1 (+3V3A), U1.13 (+3V3A), U4.2 (+3V3A)
+3V3D: C2.1 (+3V3D), C5.1 (+3V3D), C6.1 (+3V3D), C7.1 (+3V3D), C8.1 (+3V3D), C13.1 (+3V3D), C14.1 (+3V3D), U1.1 (+3V3D), U1.36 (+3V3D), U1.64 (+3V3D), U3.5 (+3V3D), U4.3 (+3V3D)
ADC_L1: J2.7 (ADC_L1), U1.17 (ADC_L1)
ADC_L2: J2.9 (ADC_L2), U1.20 (ADC_L2)
ADC_L3: J2.11 (ADC_L3), U1.21 (ADC_L3)
ADC_L4: J2.12 (ADC_L4), U1.22 (ADC_L4)
ADC_L5: J2.2 (ADC_L5), U1.16 (ADC_L5)
ADC_R1: J3.7 (ADC_R1), U1.23 (ADC_R1)
ADC_R2: J3.9 (ADC_R2), U1.24 (ADC_R2)
ADC_R3: J3.11 (ADC_R3), U1.25 (ADC_R3)
ADC_R4: J3.12 (ADC_R4), U1.26 (ADC_R4)
ADC_R5: J3.2 (ADC_R5), U1.15 (ADC_R5)
BOOT0: R4.1 (BOOT0), SW1.1 (BOOT0), U1.60 (BOOT0)
CC1: J1.A5 (CC1), R2.1 (CC1)
CC2: J1.B5 (CC2), R3.1 (CC2)
GND: C1.2 (GND), C2.2 (GND), C3.2 (GND), C4.2 (GND), C5.2 (GND), C6.2 (GND), C7.2 (GND), C8.2 (GND), C9.2 (GND), C10.2 (GND), C11.2 (GND), C12.2 (GND), C13.2 (GND), C14.2 (GND), C15.2 (GND), C16.2 (GND), C17.2 (GND), J1.A1 (GND), J1.A12 (GND), J1.B1 (GND), J1.B12 (GND), J1.SH (GND), J2.8 (GND), J3.8 (GND), R1.2 (GND), R2.2 (GND), R3.2 (GND), R4.2 (GND), SW1.2 (GND), SW2.2 (GND), U1.12 (GND), U1.31 (GND), U1.63 (GND), U2.2 (GND), U3.2 (GND), U4.1 (GND), U5.1 (GND), U5.3 (GND), U6.1 (GND), U6.3 (GND), Y1.2 (GND), Y1.4 (GND)
MUX_A0: J2.3 (MUX_A0), J3.3 (MUX_A0), U1.9 (MUX_A0)
MUX_A1: J2.4 (MUX_A1), J3.4 (MUX_A1), U1.10 (MUX_A1)
MUX_A2: J2.5 (MUX_A2), J3.5 (MUX_A2), U1.11 (MUX_A2)
NRST: C11.1 (NRST), SW2.1 (NRST), U1.7 (NRST)
RGB_L: J2.10 (RGB_L), R5.2 (RGB_L)
RGB_L_BUF: R5.1 (RGB_L_BUF), U5.4 (RGB_L_BUF)
RGB_L_MCU: U1.8 (RGB_L_MCU), U5.2 (RGB_L_MCU)
RGB_R: J3.10 (RGB_R), R6.2 (RGB_R)
RGB_R_BUF: R6.1 (RGB_R_BUF), U6.4 (RGB_R_BUF)
RGB_R_MCU: U1.41 (RGB_R_MCU), U6.2 (RGB_R_MCU)
SWCLK: U1.49 (SWCLK)
SWDIO: U1.46 (SWDIO)
SWO: U1.55 (SWO)
USB_DM: J1.A7 (USB_DM), J1.B7 (USB_DM), U1.34 (USB_DM), U2.3 (USB_DM), U2.4 (USB_DM)
USB_DP: J1.A6 (USB_DP), J1.B6 (USB_DP), U1.35 (USB_DP), U2.1 (USB_DP), U2.6 (USB_DP)
USB_R: R1.1 (USB_R), U1.33 (USB_R)
VBUS: C1.1 (VBUS), C12.1 (VBUS), C16.1 (VBUS), C17.1 (VBUS), F1.2 (VBUS), J2.6 (VBUS), J3.6 (VBUS), U2.5 (VBUS), U3.1 (VBUS), U5.5 (VBUS), U6.5 (VBUS)
VBUS_IN: F1.1 (VBUS_IN), J1.A4 (VBUS_IN), J1.A9 (VBUS_IN), J1.B4 (VBUS_IN), J1.B9 (VBUS_IN)
XTAL_IN: C3.1 (XTAL_IN), U1.5 (XTAL_IN), Y1.1 (XTAL_IN)
XTAL_OUT: C4.1 (XTAL_OUT), U1.6 (XTAL_OUT), Y1.3 (XTAL_OUT)

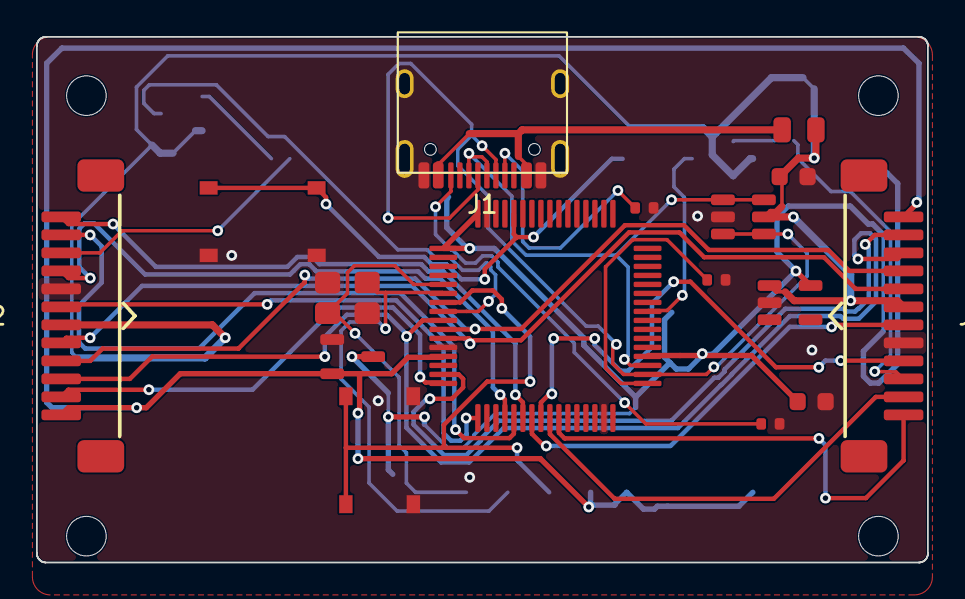
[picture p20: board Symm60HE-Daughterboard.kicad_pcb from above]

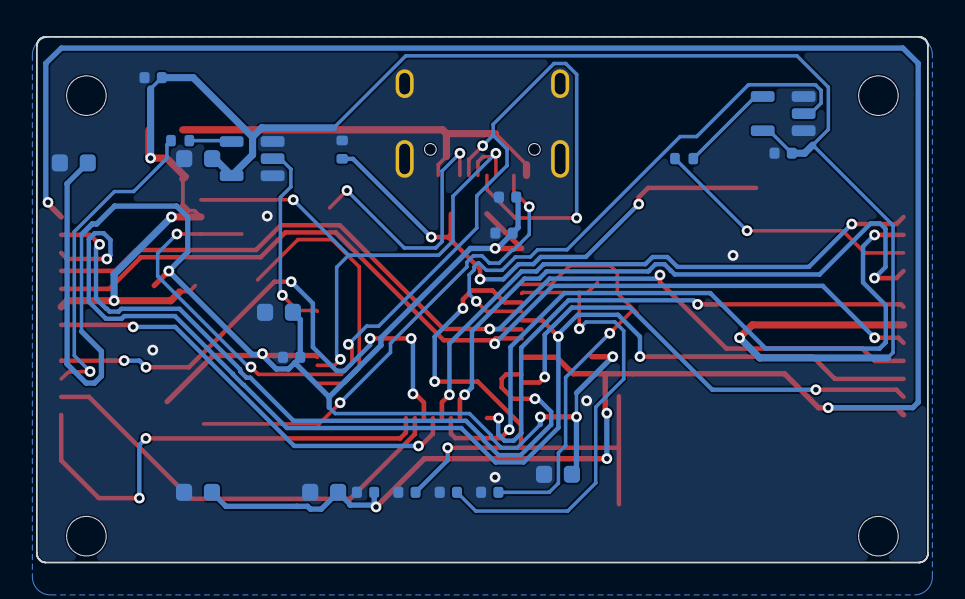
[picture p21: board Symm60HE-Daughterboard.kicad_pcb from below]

Board: 2 copper layers, 49.5 x 29.2 mm, 40 parts (20 on the bottom side), 33 nets.

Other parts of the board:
MHD1, MHD2, MHD3, MHD4: M2_NPTH; MountingHole_2.2mm_M2_NPTH

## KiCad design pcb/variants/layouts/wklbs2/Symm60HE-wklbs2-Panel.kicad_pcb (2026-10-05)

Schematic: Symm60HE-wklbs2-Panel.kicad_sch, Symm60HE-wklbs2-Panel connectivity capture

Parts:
L-AML1, L-AML2, L-AML3, L-AML4, L-AML5: SN74LV4051A; AM1_TSSOP-16_4.4x5mm_P0.65mm
L-CL1A, L-CL2A, L-CL3A, L-CL4A, L-CL5A, L-CL6A, L-CL7A, L-CL8A, L-CL9A, L-CL10A, L-CL11A, L-CL12A, L-CL13A, L-CL14A, L-CL15A, L-CL16A, L-CL17A, L-CL18A, L-CL19A, L-CL20A, L-CL21A, L-CL22A, L-CL23A, L-CL24A, L-CL25A, L-CL26A, L-CL28A, L-CL30A, L-CL32A, L-CL33A: 100n; C1_C_0402_1005Metric
L-CL1B, L-CL2B, L-CL3B, L-CL4B, L-CL5B, L-CL6B, L-CL7B, L-CL8B, L-CL9B, L-CL10B, L-CL11B, L-CL12B, L-CL13B, L-CL14B, L-CL15B, L-CL16B, L-CL17B, L-CL18B, L-CL19B, L-CL20B, L-CL21B, L-CL22B, L-CL23B, L-CL24B, L-CL25B, L-CL26B, L-CL28B, L-CL30B, L-CL32B, L-CL33B: 4.7n; C1_C_0402_1005Metric
L-CML1, L-CML2, L-CML3, L-CML4, L-CML5: 100n; C1_C_0402_1005Metric
L-CRGBL1, L-CRGBL2, L-CRGBL3, L-CRGBL4, L-CRGBL5, L-CRGBL6, L-CRGBL7, L-CRGBL8, L-CRGBL9, L-CRGBL10, L-CRGBL11, L-CRGBL12, L-CRGBL13, L-CRGBL14, L-CRGBL15, L-CRGBL16, L-CRGBL17, L-CRGBL18, L-CRGBL19, L-CRGBL20, L-CRGBL21, L-CRGBL22, L-CRGBL23, L-CRGBL24, L-CRGBL25, L-CRGBL26, L-CRGBL27, L-CRGBL29, L-CRGBL30, L-CRGBL31: 100n; C1_C_0402_1005Metric
L-DL1, L-DL2, L-DL3, L-DL4, L-DL5, L-DL6, L-DL7, L-DL8, L-DL9, L-DL10, L-DL11, L-DL12, L-DL13, L-DL14, L-DL15, L-DL16, L-DL17, L-DL18, L-DL19, L-DL20, L-DL21, L-DL22, L-DL23, L-DL24, L-DL25, L-DL26, L-DL27, L-DL29, L-DL30, L-DL31: SK6812MINI-E; SK6812MINI-E_ReverseMount
L-HEL1, L-HEL2, L-HEL3, L-HEL4, L-HEL5, L-HEL6, L-HEL7, L-HEL9, L-HEL10, L-HEL11, L-HEL12, L-HEL13, L-HEL14, L-HEL16, L-HEL17, L-HEL18, L-HEL19, L-HEL20, L-HEL22, L-HEL23, L-HEL24, L-HEL25, L-HEL26: MT9102ET; HE_KEY_1.00u
L-HEL8, L-HEL28, L-HEL30, L-HEL32: MT9102ET; HE_KEY_1.50u
L-HEL15: MT9102ET; HE_KEY_1.75u
L-HEL21, L-HEL33: MT9102ET; HE_KEY_2.25u
L-JL1: FFC_12P; FFC_12P_1.00mm_TopContact
L-RBPL29: 0R_DNP; R3_R_0402_1005Metric_DNP
R-AMR1, R-AMR2, R-AMR3, R-AMR4, R-AMR5: SN74LV4051A; AM1_TSSOP-16_4.4x5mm_P0.65mm
R-CMR1, R-CMR2, R-CMR3, R-CMR4, R-CMR5: 100n; C1_C_0402_1005Metric
R-CR1A, R-CR2A, R-CR4A, R-CR6A, R-CR7A, R-CR8A, R-CR9A, R-CR10A, R-CR11A, R-CR12A, R-CR13A, R-CR14A, R-CR15A, R-CR16A, R-CR17A, R-CR18A, R-CR19A, R-CR20A, R-CR21A, R-CR22A, R-CR23A, R-CR25A, R-CR27A, R-CR28A, R-CR29A, R-CR31A, R-CR33A, R-CR35A, R-CR36A: 100n; C1_C_0402_1005Metric
R-CR1B, R-CR2B, R-CR4B, R-CR6B, R-CR7B, R-CR8B, R-CR9B, R-CR10B, R-CR11B, R-CR12B, R-CR13B, R-CR14B, R-CR15B, R-CR16B, R-CR17B, R-CR18B, R-CR19B, R-CR20B, R-CR21B, R-CR22B, R-CR23B, R-CR25B, R-CR27B, R-CR28B, R-CR29B, R-CR31B, R-CR33B, R-CR35B, R-CR36B: 4.7n; C1_C_0402_1005Metric
R-CRGBR1, R-CRGBR2, R-CRGBR3, R-CRGBR6, R-CRGBR7, R-CRGBR8, R-CRGBR9, R-CRGBR10, R-CRGBR11, R-CRGBR12, R-CRGBR13, R-CRGBR14, R-CRGBR15, R-CRGBR16, R-CRGBR17, R-CRGBR18, R-CRGBR19, R-CRGBR20, R-CRGBR21, R-CRGBR23, R-CRGBR24, R-CRGBR25, R-CRGBR26, R-CRGBR27, R-CRGBR28, R-CRGBR29, R-CRGBR31, R-CRGBR32, R-CRGBR33: 100n; C1_C_0402_1005Metric
R-DR1, R-DR2, R-DR3, R-DR6, R-DR7, R-DR8, R-DR9, R-DR10, R-DR11, R-DR12, R-DR13, R-DR14, R-DR15, R-DR16, R-DR17, R-DR18, R-DR19, R-DR20, R-DR21, R-DR23, R-DR24, R-DR25, R-DR26, R-DR27, R-DR28, R-DR29, R-DR31, R-DR32, R-DR33: SK6812MINI-E; SK6812MINI-E_ReverseMount
R-HER1, R-HER2, R-HER6, R-HER7, R-HER8, R-HER9, R-HER10, R-HER12, R-HER13, R-HER14, R-HER15, R-HER16, R-HER17, R-HER19, R-HER20, R-HER21, R-HER22, R-HER23, R-HER27, R-HER28, R-HER29: MT9102ET; HE_KEY_1.00u
R-HER4: MT9102ET; HE_KEY_2.00u
R-HER11, R-HER31, R-HER33, R-HER35: MT9102ET; HE_KEY_1.50u
R-HER18: MT9102ET; HE_KEY_1.75u
R-HER25, R-HER36: MT9102ET; HE_KEY_2.25u
R-JR1: FFC_12P; FFC_12P_1.00mm_TopContact
R-RBPR5, R-RBPR24, R-RBPR31: 0R_DNP; R3_R_0402_1005Metric_DNP

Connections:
/L/+3V3A: L-AML1.16 (/L/+3V3A), L-AML2.16 (/L/+3V3A), L-AML3.16 (/L/+3V3A), L-AML4.16 (/L/+3V3A), L-AML5.16 (/L/+3V3A), L-CL1A.1 (/L/+3V3A), L-CL2A.1 (/L/+3V3A), L-CL3A.1 (/L/+3V3A), L-CL4A.1 (/L/+3V3A), L-CL5A.1 (/L/+3V3A), L-CL6A.1 (/L/+3V3A), L-CL7A.1 (/L/+3V3A), L-CL8A.1 (/L/+3V3A), L-CL9A.1 (/L/+3V3A), L-CL10A.1 (/L/+3V3A), L-CL11A.1 (/L/+3V3A), L-CL12A.1 (/L/+3V3A), L-CL13A.1 (/L/+3V3A), L-CL14A.1 (/L/+3V3A), L-CL15A.1 (/L/+3V3A), L-CL16A.1 (/L/+3V3A), L-CL17A.1 (/L/+3V3A), L-CL18A.1 (/L/+3V3A), L-CL19A.1 (/L/+3V3A), L-CL20A.1 (/L/+3V3A), L-CL21A.1 (/L/+3V3A), L-CL22A.1 (/L/+3V3A), L-CL23A.1 (/L/+3V3A), L-CL24A.1 (/L/+3V3A), L-CL25A.1 (/L/+3V3A), L-CL26A.1 (/L/+3V3A), L-CL28A.1 (/L/+3V3A), L-CL30A.1 (/L/+3V3A), L-CL32A.1 (/L/+3V3A), L-CL33A.1 (/L/+3V3A), L-CML1.1 (/L/+3V3A), L-CML2.1 (/L/+3V3A), L-CML3.1 (/L/+3V3A), L-CML4.1 (/L/+3V3A), L-CML5.1 (/L/+3V3A), L-HEL1.1 (/L/+3V3A), L-HEL2.1 (/L/+3V3A), L-HEL3.1 (/L/+3V3A), L-HEL4.1 (/L/+3V3A), L-HEL5.1 (/L/+3V3A), L-HEL6.1 (/L/+3V3A), L-HEL7.1 (/L/+3V3A), L-HEL8.1 (/L/+3V3A), L-HEL9.1 (/L/+3V3A), L-HEL10.1 (/L/+3V3A), L-HEL11.1 (/L/+3V3A), L-HEL12.1 (/L/+3V3A), L-HEL13.1 (/L/+3V3A), L-HEL14.1 (/L/+3V3A), L-HEL15.1 (/L/+3V3A), L-HEL16.1 (/L/+3V3A), L-HEL17.1 (/L/+3V3A), L-HEL18.1 (/L/+3V3A), L-HEL19.1 (/L/+3V3A), L-HEL20.1 (/L/+3V3A), L-HEL21.1 (/L/+3V3A), L-HEL22.1 (/L/+3V3A), L-HEL23.1 (/L/+3V3A), L-HEL24.1 (/L/+3V3A), L-HEL25.1 (/L/+3V3A), L-HEL26.1 (/L/+3V3A), L-HEL28.1 (/L/+3V3A), L-HEL30.1 (/L/+3V3A), L-HEL32.1 (/L/+3V3A), L-HEL33.1 (/L/+3V3A), L-JL1.12 (/L/+3V3A)
/L/ADC_L1: L-AML1.3 (/L/ADC_L1), L-JL1.6 (/L/ADC_L1)
/L/ADC_L2: L-AML2.3 (/L/ADC_L2), L-JL1.4 (/L/ADC_L2)
/L/ADC_L3: L-AML3.3 (/L/ADC_L3), L-JL1.2 (/L/ADC_L3)
/L/ADC_L4: L-AML4.3 (/L/ADC_L4), L-JL1.1 (/L/ADC_L4)
/L/ADC_L5: L-AML5.3 (/L/ADC_L5), L-JL1.11 (/L/ADC_L5)
/L/GND: L-AML1.6 (/L/GND), L-AML1.7 (/L/GND), L-AML1.8 (/L/GND), L-AML2.4 (/L/GND), L-AML2.6 (/L/GND), L-AML2.7 (/L/GND), L-AML2.8 (/L/GND), L-AML3.6 (/L/GND), L-AML3.7 (/L/GND), L-AML3.8 (/L/GND), L-AML4.2 (/L/GND), L-AML4.4 (/L/GND), L-AML4.6 (/L/GND), L-AML4.7 (/L/GND), L-AML4.8 (/L/GND), L-AML4.13 (/L/GND), L-AML4.14 (/L/GND), L-AML5.6 (/L/GND), L-AML5.7 (/L/GND), L-AML5.8 (/L/GND), L-AML5.12 (/L/GND), L-AML5.13 (/L/GND), L-AML5.14 (/L/GND), L-AML5.15 (/L/GND), L-CL1A.2 (/L/GND), L-CL1B.2 (/L/GND), L-CL2A.2 (/L/GND), L-CL2B.2 (/L/GND), L-CL3A.2 (/L/GND), L-CL3B.2 (/L/GND), L-CL4A.2 (/L/GND), L-CL4B.2 (/L/GND), L-CL5A.2 (/L/GND), L-CL5B.2 (/L/GND), L-CL6A.2 (/L/GND), L-CL6B.2 (/L/GND), L-CL7A.2 (/L/GND), L-CL7B.2 (/L/GND), L-CL8A.2 (/L/GND), L-CL8B.2 (/L/GND), L-CL9A.2 (/L/GND), L-CL9B.2 (/L/GND), L-CL10A.2 (/L/GND), L-CL10B.2 (/L/GND), L-CL11A.2 (/L/GND), L-CL11B.2 (/L/GND), L-CL12A.2 (/L/GND), L-CL12B.2 (/L/GND), L-CL13A.2 (/L/GND), L-CL13B.2 (/L/GND), L-CL14A.2 (/L/GND), L-CL14B.2 (/L/GND), L-CL15A.2 (/L/GND), L-CL15B.2 (/L/GND), L-CL16A.2 (/L/GND), L-CL16B.2 (/L/GND), L-CL17A.2 (/L/GND), L-CL17B.2 (/L/GND), L-CL18A.2 (/L/GND), L-CL18B.2 (/L/GND), L-CL19A.2 (/L/GND), L-CL19B.2 (/L/GND), L-CL20A.2 (/L/GND), L-CL20B.2 (/L/GND), L-CL21A.2 (/L/GND), L-CL21B.2 (/L/GND), L-CL22A.2 (/L/GND), L-CL22B.2 (/L/GND), L-CL23A.2 (/L/GND), L-CL23B.2 (/L/GND), L-CL24A.2 (/L/GND), L-CL24B.2 (/L/GND), L-CL25A.2 (/L/GND), L-CL25B.2 (/L/GND), L-CL26A.2 (/L/GND), L-CL26B.2 (/L/GND), L-CL28A.2 (/L/GND), L-CL28B.2 (/L/GND), L-CL30A.2 (/L/GND), L-CL30B.2 (/L/GND), L-CL32A.2 (/L/GND), L-CL32B.2 (/L/GND), L-CL33A.2 (/L/GND), L-CL33B.2 (/L/GND), L-CML1.2 (/L/GND), L-CML2.2 (/L/GND), L-CML3.2 (/L/GND), L-CML4.2 (/L/GND), L-CML5.2 (/L/GND), L-CRGBL1.2 (/L/GND), L-CRGBL2.2 (/L/GND), L-CRGBL3.2 (/L/GND), L-CRGBL4.2 (/L/GND), L-CRGBL5.2 (/L/GND), L-CRGBL6.2 (/L/GND), L-CRGBL7.2 (/L/GND), L-CRGBL8.2 (/L/GND), L-CRGBL9.2 (/L/GND), L-CRGBL10.2 (/L/GND), L-CRGBL11.2 (/L/GND), L-CRGBL12.2 (/L/GND), L-CRGBL13.2 (/L/GND), L-CRGBL14.2 (/L/GND), L-CRGBL15.2 (/L/GND), L-CRGBL16.2 (/L/GND), L-CRGBL17.2 (/L/GND), L-CRGBL18.2 (/L/GND), L-CRGBL19.2 (/L/GND), L-CRGBL20.2 (/L/GND), L-CRGBL21.2 (/L/GND), L-CRGBL22.2 (/L/GND), L-CRGBL23.2 (/L/GND), L-CRGBL24.2 (/L/GND), L-CRGBL25.2 (/L/GND), L-CRGBL26.2 (/L/GND), L-CRGBL27.2 (/L/GND), L-CRGBL29.2 (/L/GND), L-CRGBL30.2 (/L/GND), L-CRGBL31.2 (/L/GND), L-DL1.1 (/L/GND), L-DL2.1 (/L/GND), L-DL3.1 (/L/GND), L-DL4.1 (/L/GND), L-DL5.1 (/L/GND), L-DL6.1 (/L/GND), L-DL7.1 (/L/GND), L-DL8.1 (/L/GND), L-DL9.1 (/L/GND), L-DL10.1 (/L/GND), L-DL11.1 (/L/GND), L-DL12.1 (/L/GND), L-DL13.1 (/L/GND), L-DL14.1 (/L/GND), L-DL15.1 (/L/GND), L-DL16.1 (/L/GND), L-DL17.1 (/L/GND), L-DL18.1 (/L/GND), L-DL19.1 (/L/GND), L-DL20.1 (/L/GND), L-DL21.1 (/L/GND), L-DL22.1 (/L/GND), L-DL23.1 (/L/GND), L-DL24.1 (/L/GND), L-DL25.1 (/L/GND), L-DL26.1 (/L/GND), L-DL27.1 (/L/GND), L-DL29.1 (/L/GND), L-DL30.1 (/L/GND), L-DL31.1 (/L/GND), L-HEL1.2 (/L/GND), L-HEL2.2 (/L/GND), L-HEL3.2 (/L/GND), L-HEL4.2 (/L/GND), L-HEL5.2 (/L/GND), L-HEL6.2 (/L/GND), L-HEL7.2 (/L/GND), L-HEL8.2 (/L/GND), L-HEL9.2 (/L/GND), L-HEL10.2 (/L/GND), L-HEL11.2 (/L/GND), L-HEL12.2 (/L/GND), L-HEL13.2 (/L/GND), L-HEL14.2 (/L/GND), L-HEL15.2 (/L/GND), L-HEL16.2 (/L/GND), L-HEL17.2 (/L/GND), L-HEL18.2 (/L/GND), L-HEL19.2 (/L/GND), L-HEL20.2 (/L/GND), L-HEL21.2 (/L/GND), L-HEL22.2 (/L/GND), L-HEL23.2 (/L/GND), L-HEL24.2 (/L/GND), L-HEL25.2 (/L/GND), L-HEL26.2 (/L/GND), L-HEL28.2 (/L/GND), L-HEL30.2 (/L/GND), L-HEL32.2 (/L/GND), L-HEL33.2 (/L/GND), L-JL1.5 (/L/GND)
/L/HE_L01: L-AML1.12 (/L/HE_L01), L-CL1B.1 (/L/HE_L01), L-HEL1.3 (/L/HE_L01)
/L/HE_L02: L-AML1.13 (/L/HE_L02), L-CL2B.1 (/L/HE_L02), L-HEL2.3 (/L/HE_L02)
/L/HE_L03: L-AML1.14 (/L/HE_L03), L-CL3B.1 (/L/HE_L03), L-HEL3.3 (/L/HE_L03)
/L/HE_L04: L-AML1.15 (/L/HE_L04), L-CL4B.1 (/L/HE_L04), L-HEL4.3 (/L/HE_L04)
/L/HE_L05: L-AML2.12 (/L/HE_L05), L-CL5B.1 (/L/HE_L05), L-HEL5.3 (/L/HE_L05)
/L/HE_L06: L-AML2.13 (/L/HE_L06), L-CL6B.1 (/L/HE_L06), L-HEL6.3 (/L/HE_L06)
/L/HE_L07: L-AML2.14 (/L/HE_L07), L-CL7B.1 (/L/HE_L07), L-HEL7.3 (/L/HE_L07)
/L/HE_L08: L-AML1.5 (/L/HE_L08), L-CL8B.1 (/L/HE_L08), L-HEL8.3 (/L/HE_L08)
/L/HE_L09: L-AML1.4 (/L/HE_L09), L-CL9B.1 (/L/HE_L09), L-HEL9.3 (/L/HE_L09)
/L/HE_L10: L-AML1.2 (/L/HE_L10), L-CL10B.1 (/L/HE_L10), L-HEL10.3 (/L/HE_L10)
/L/HE_L11: L-AML1.1 (/L/HE_L11), L-CL11B.1 (/L/HE_L11), L-HEL11.3 (/L/HE_L11)
/L/HE_L12: L-AML2.5 (/L/HE_L12), L-CL12B.1 (/L/HE_L12), L-HEL12.3 (/L/HE_L12)
/L/HE_L13: L-AML2.2 (/L/HE_L13), L-CL13B.1 (/L/HE_L13), L-HEL13.3 (/L/HE_L13)
/L/HE_L14: L-AML2.1 (/L/HE_L14), L-CL14B.1 (/L/HE_L14), L-HEL14.3 (/L/HE_L14)
/L/HE_L15: L-AML3.12 (/L/HE_L15), L-CL15B.1 (/L/HE_L15), L-HEL15.3 (/L/HE_L15)
/L/HE_L16: L-AML3.13 (/L/HE_L16), L-CL16B.1 (/L/HE_L16), L-HEL16.3 (/L/HE_L16)
/L/HE_L17: L-AML3.14 (/L/HE_L17), L-CL17B.1 (/L/HE_L17), L-HEL17.3 (/L/HE_L17)
/L/HE_L18: L-AML3.15 (/L/HE_L18), L-CL18B.1 (/L/HE_L18), L-HEL18.3 (/L/HE_L18)
/L/HE_L19: L-AML4.12 (/L/HE_L19), L-CL19B.1 (/L/HE_L19), L-HEL19.3 (/L/HE_L19)
/L/HE_L20: L-AML4.15 (/L/HE_L20), L-CL20B.1 (/L/HE_L20), L-HEL20.3 (/L/HE_L20)
/L/HE_L21: L-AML3.5 (/L/HE_L21), L-CL21B.1 (/L/HE_L21), L-HEL21.3 (/L/HE_L21)
/L/HE_L22: L-AML3.4 (/L/HE_L22), L-CL22B.1 (/L/HE_L22), L-HEL22.3 (/L/HE_L22)
/L/HE_L23: L-AML3.2 (/L/HE_L23), L-CL23B.1 (/L/HE_L23), L-HEL23.3 (/L/HE_L23)
/L/HE_L24: L-AML3.1 (/L/HE_L24), L-CL24B.1 (/L/HE_L24), L-HEL24.3 (/L/HE_L24)
/L/HE_L25: L-AML4.5 (/L/HE_L25), L-CL25B.1 (/L/HE_L25), L-HEL25.3 (/L/HE_L25)
/L/HE_L26: L-AML4.1 (/L/HE_L26), L-CL26B.1 (/L/HE_L26), L-HEL26.3 (/L/HE_L26)
/L/HE_L30: L-AML5.2 (/L/HE_L30), L-CL32B.1 (/L/HE_L30), L-HEL32.3 (/L/HE_L30)
/L/HE_L31: L-AML5.1 (/L/HE_L31), L-CL33B.1 (/L/HE_L31), L-HEL33.3 (/L/HE_L31)
/L/HE_L32: L-AML5.4 (/L/HE_L32), L-CL28B.1 (/L/HE_L32), L-HEL28.3 (/L/HE_L32)
/L/HE_L33: L-AML5.5 (/L/HE_L33), L-CL30B.1 (/L/HE_L33), L-HEL30.3 (/L/HE_L33)
/L/MUX_A0: L-AML1.11 (/L/MUX_A0), L-AML2.11 (/L/MUX_A0), L-AML3.11 (/L/MUX_A0), L-AML4.11 (/L/MUX_A0), L-AML5.11 (/L/MUX_A0), L-JL1.10 (/L/MUX_A0)
/L/MUX_A1: L-AML1.10 (/L/MUX_A1), L-AML2.10 (/L/MUX_A1), L-AML3.10 (/L/MUX_A1), L-AML4.10 (/L/MUX_A1), L-AML5.10 (/L/MUX_A1), L-JL1.9 (/L/MUX_A1)
/L/MUX_A2: L-AML1.9 (/L/MUX_A2), L-AML2.9 (/L/MUX_A2), L-AML3.9 (/L/MUX_A2), L-AML4.9 (/L/MUX_A2), L-AML5.9 (/L/MUX_A2), L-JL1.8 (/L/MUX_A2)
/L/RGB_L: L-DL1.2 (/L/RGB_L), L-JL1.3 (/L/RGB_L)
/L/RGB_L_01: L-DL1.4 (/L/RGB_L_01), L-DL2.2 (/L/RGB_L_01)
/L/RGB_L_02: L-DL2.4 (/L/RGB_L_02), L-DL3.2 (/L/RGB_L_02)
/L/RGB_L_03: L-DL3.4 (/L/RGB_L_03), L-DL4.2 (/L/RGB_L_03)
/L/RGB_L_04: L-DL4.4 (/L/RGB_L_04), L-DL5.2 (/L/RGB_L_04)
/L/RGB_L_05: L-DL5.4 (/L/RGB_L_05), L-DL6.2 (/L/RGB_L_05)
/L/RGB_L_06: L-DL6.4 (/L/RGB_L_06), L-DL7.2 (/L/RGB_L_06)
/L/RGB_L_07: L-DL7.4 (/L/RGB_L_07), L-DL8.2 (/L/RGB_L_07)
/L/RGB_L_08: L-DL8.4 (/L/RGB_L_08), L-DL9.2 (/L/RGB_L_08)
/L/RGB_L_09: L-DL9.4 (/L/RGB_L_09), L-DL10.2 (/L/RGB_L_09)
/L/RGB_L_10: L-DL10.4 (/L/RGB_L_10), L-DL11.2 (/L/RGB_L_10)
/L/RGB_L_11: L-DL11.4 (/L/RGB_L_11), L-DL12.2 (/L/RGB_L_11)
/L/RGB_L_12: L-DL12.4 (/L/RGB_L_12), L-DL13.2 (/L/RGB_L_12)
/L/RGB_L_13: L-DL13.4 (/L/RGB_L_13), L-DL14.2 (/L/RGB_L_13)
/L/RGB_L_14: L-DL14.4 (/L/RGB_L_14), L-DL15.2 (/L/RGB_L_14)
/L/RGB_L_15: L-DL15.4 (/L/RGB_L_15), L-DL16.2 (/L/RGB_L_15)
/L/RGB_L_16: L-DL16.4 (/L/RGB_L_16), L-DL17.2 (/L/RGB_L_16)
/L/RGB_L_17: L-DL17.4 (/L/RGB_L_17), L-DL18.2 (/L/RGB_L_17)
/L/RGB_L_18: L-DL18.4 (/L/RGB_L_18), L-DL19.2 (/L/RGB_L_18)
/L/RGB_L_19: L-DL19.4 (/L/RGB_L_19), L-DL20.2 (/L/RGB_L_19)
/L/RGB_L_20: L-DL20.4 (/L/RGB_L_20), L-DL21.2 (/L/RGB_L_20)
/L/RGB_L_21: L-DL21.4 (/L/RGB_L_21), L-DL22.2 (/L/RGB_L_21)
/L/RGB_L_22: L-DL22.4 (/L/RGB_L_22), L-DL23.2 (/L/RGB_L_22)
/L/RGB_L_23: L-DL23.4 (/L/RGB_L_23), L-DL24.2 (/L/RGB_L_23)
/L/RGB_L_24: L-DL24.4 (/L/RGB_L_24), L-DL25.2 (/L/RGB_L_24)
/L/RGB_L_25: L-DL25.4 (/L/RGB_L_25), L-DL26.2 (/L/RGB_L_25)
/L/RGB_L_26: L-DL26.4 (/L/RGB_L_26), L-DL27.2 (/L/RGB_L_26)
/L/RGB_L_27: L-DL27.4 (/L/RGB_L_27), L-DL29.2 (/L/RGB_L_27), L-RBPL29.1 (/L/RGB_L_27)
/L/RGB_L_29: L-DL29.4 (/L/RGB_L_29), L-DL30.2 (/L/RGB_L_29), L-RBPL29.2 (/L/RGB_L_29)
/L/RGB_L_30: L-DL30.4 (/L/RGB_L_30), L-DL31.2 (/L/RGB_L_30)
/L/RGB_L_END: L-DL31.4 (/L/RGB_L_END)
/L/VBUS: L-CRGBL1.1 (/L/VBUS), L-CRGBL2.1 (/L/VBUS), L-CRGBL3.1 (/L/VBUS), L-CRGBL4.1 (/L/VBUS), L-CRGBL5.1 (/L/VBUS), L-CRGBL6.1 (/L/VBUS), L-CRGBL7.1 (/L/VBUS), L-CRGBL8.1 (/L/VBUS), L-CRGBL9.1 (/L/VBUS), L-CRGBL10.1 (/L/VBUS), L-CRGBL11.1 (/L/VBUS), L-CRGBL12.1 (/L/VBUS), L-CRGBL13.1 (/L/VBUS), L-CRGBL14.1 (/L/VBUS), L-CRGBL15.1 (/L/VBUS), L-CRGBL16.1 (/L/VBUS), L-CRGBL17.1 (/L/VBUS), L-CRGBL18.1 (/L/VBUS), L-CRGBL19.1 (/L/VBUS), L-CRGBL20.1 (/L/VBUS), L-CRGBL21.1 (/L/VBUS), L-CRGBL22.1 (/L/VBUS), L-CRGBL23.1 (/L/VBUS), L-CRGBL24.1 (/L/VBUS), L-CRGBL25.1 (/L/VBUS), L-CRGBL26.1 (/L/VBUS), L-CRGBL27.1 (/L/VBUS), L-CRGBL29.1 (/L/VBUS), L-CRGBL30.1 (/L/VBUS), L-CRGBL31.1 (/L/VBUS), L-DL1.3 (/L/VBUS), L-DL2.3 (/L/VBUS), L-DL3.3 (/L/VBUS), L-DL4.3 (/L/VBUS), L-DL5.3 (/L/VBUS), L-DL6.3 (/L/VBUS), L-DL7.3 (/L/VBUS), L-DL8.3 (/L/VBUS), L-DL9.3 (/L/VBUS), L-DL10.3 (/L/VBUS), L-DL11.3 (/L/VBUS), L-DL12.3 (/L/VBUS), L-DL13.3 (/L/VBUS), L-DL14.3 (/L/VBUS), L-DL15.3 (/L/VBUS), L-DL16.3 (/L/VBUS), L-DL17.3 (/L/VBUS), L-DL18.3 (/L/VBUS), L-DL19.3 (/L/VBUS), L-DL20.3 (/L/VBUS), L-DL21.3 (/L/VBUS), L-DL22.3 (/L/VBUS), L-DL23.3 (/L/VBUS), L-DL24.3 (/L/VBUS), L-DL25.3 (/L/VBUS), L-DL26.3 (/L/VBUS), L-DL27.3 (/L/VBUS), L-DL29.3 (/L/VBUS), L-DL30.3 (/L/VBUS), L-DL31.3 (/L/VBUS), L-JL1.7 (/L/VBUS)
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

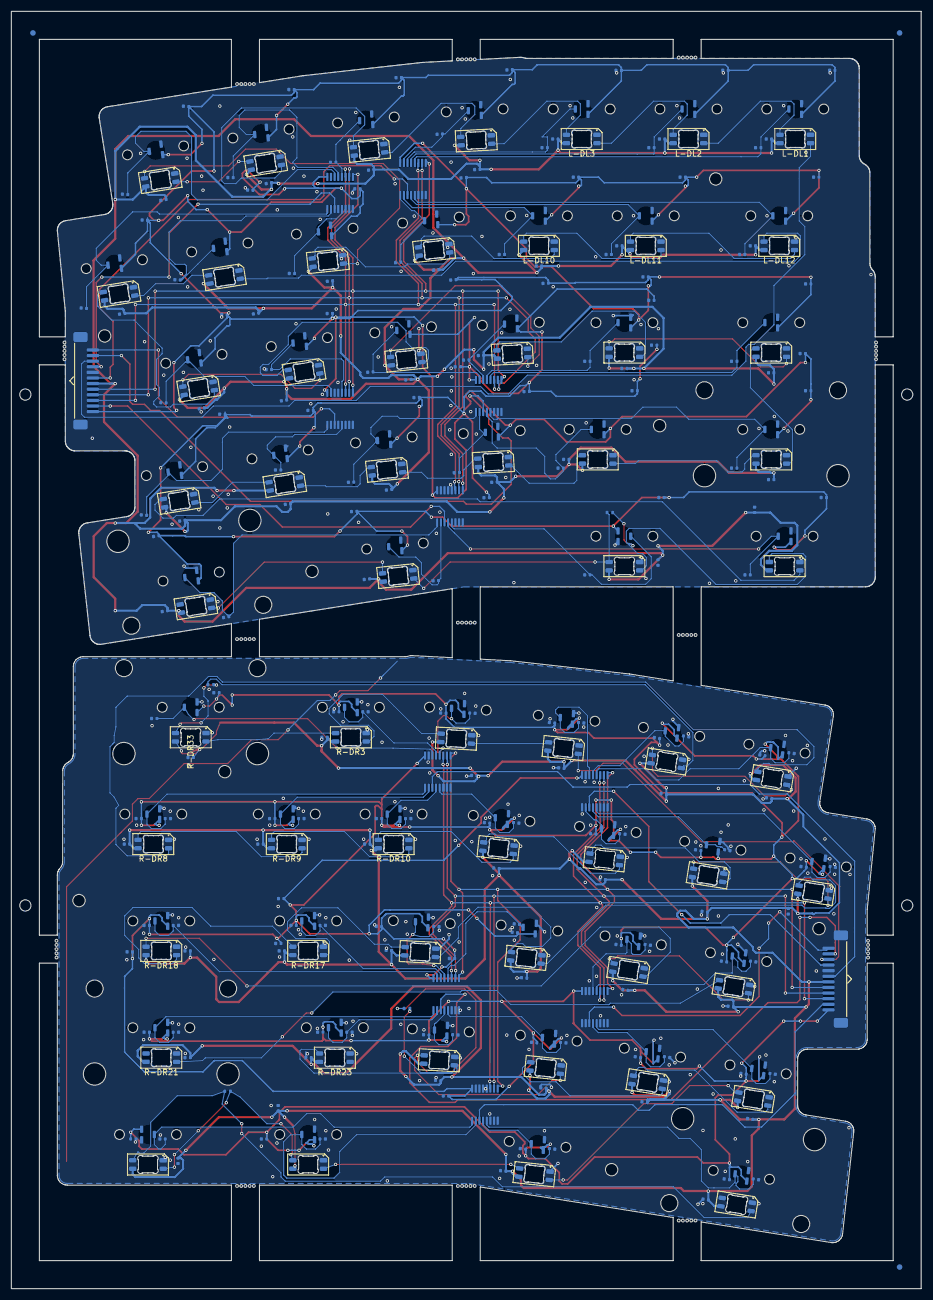
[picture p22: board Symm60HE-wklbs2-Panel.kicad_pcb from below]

Board: 2 copper layers, 162.3 x 227.8 mm, 406 parts (324 on the bottom side), 140 nets.

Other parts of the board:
FID1, FID2, FID3: FIDUCIAL_1MM_BCU; Fiducial_1mm_BCu
L-MHL1, L-MHL2, L-MHL3, L-MHL4: M2_NPTH; MountingHole_2.2mm_M2_NPTH
L-SL1, L-SL2: STAB_MX; STABILIZER_MX_2U
MB1, MB2, MB3, MB4, MB5, MB6, MB7, MB8, MB9, MB10, MB11, MB12, MB13, MB14, MB15, MB16, MB17, MB18, MB19, MB20, MB21, MB22, MB23, MB24, MB25, MB26, MB27, MB28, MB29, MB30, MB31, MB32, MB33, MB34, MB35, MB36, MB37, MB38, MB39, MB40, MB41, MB42, MB43, MB44, MB45, MB46, MB47, MB48, MB49, MB50, MB51, MB52, MB53, MB54, MB55, MB56, MB57, MB58, MB59, MB60, MB61, MB62, MB63, MB64, MB65: MOUSE_BITE_0.5MM; MouseBite_0.5mm
R-MHR1, R-MHR2, R-MHR3, R-MHR4: M2_NPTH; MountingHole_2.2mm_M2_NPTH
R-SR1, R-SR2, R-SR3: STAB_MX; STABILIZER_MX_2U
TH1, TH2, TH3, TH4: TOOLING_HOLE_2MM; ToolingHole_2mm_NPTH

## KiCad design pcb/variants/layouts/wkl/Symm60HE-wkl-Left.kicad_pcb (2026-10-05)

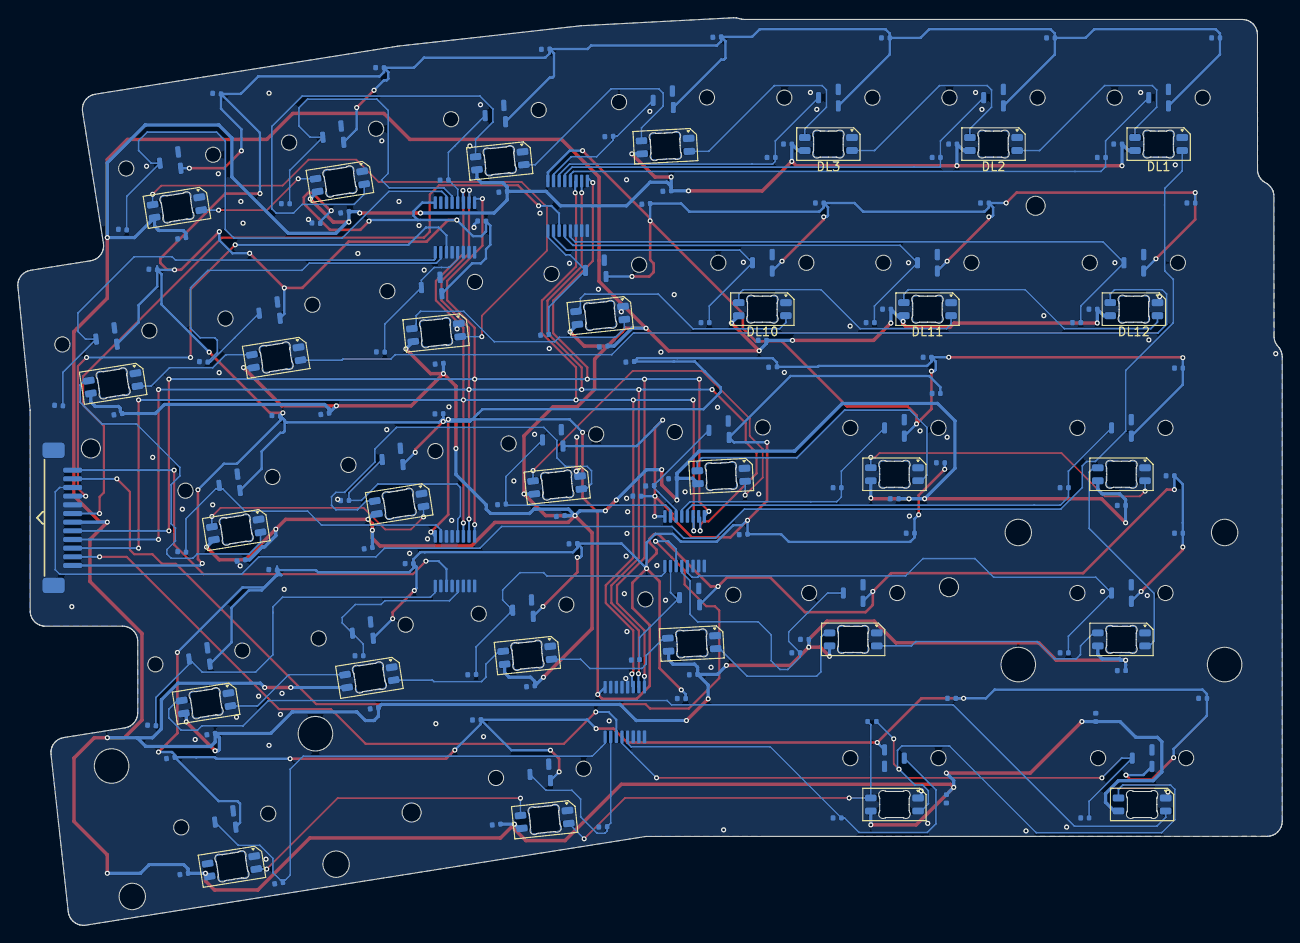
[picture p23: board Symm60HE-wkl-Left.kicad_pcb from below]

Board: 2 copper layers, 145.9 x 104.7 mm, 168 parts (162 on the bottom side), 71 nets.

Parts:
AML1, AML2, AML3, AML4, AML5: SN74LV4051A; AM1_TSSOP-16_4.4x5mm_P0.65mm
CL1A, CL2A, CL3A, CL4A, CL5A, CL6A, CL7A, CL8A, CL9A, CL10A, CL11A, CL12A, CL13A, CL14A, CL15A, CL16A, CL17A, CL18A, CL19A, CL20A, CL21A, CL22A, CL23A, CL24A, CL25A, CL26A, CL28A, CL30A, CL32A, CL33A: 100n; C1_C_0402_1005Metric
CL1B, CL2B, CL3B, CL4B, CL5B, CL6B, CL7B, CL8B, CL9B, CL10B, CL11B, CL12B, CL13B, CL14B, CL15B, CL16B, CL17B, CL18B, CL19B, CL20B, CL21B, CL22B, CL23B, CL24B, CL25B, CL26B, CL28B, CL30B, CL32B, CL33B: 4.7n; C1_C_0402_1005Metric
CML1, CML2, CML3, CML4, CML5: 100n; C1_C_0402_1005Metric
CRGBL1, CRGBL2, CRGBL3, CRGBL4, CRGBL5, CRGBL6, CRGBL7, CRGBL8, CRGBL9, CRGBL10, CRGBL11, CRGBL12, CRGBL13, CRGBL14, CRGBL15, CRGBL16, CRGBL17, CRGBL18, CRGBL19, CRGBL20, CRGBL21, CRGBL22, CRGBL23, CRGBL24, CRGBL25, CRGBL26, CRGBL27, CRGBL29, CRGBL30, CRGBL31: 100n; C1_C_0402_1005Metric
DL1, DL2, DL3, DL4, DL5, DL6, DL7, DL8, DL9, DL10, DL11, DL12, DL13, DL14, DL15, DL16, DL17, DL18, DL19, DL20, DL21, DL22, DL23, DL24, DL25, DL26, DL27, DL29, DL30, DL31: SK6812MINI-E; SK6812MINI-E_ReverseMount
HEL1, HEL2, HEL3, HEL4, HEL5, HEL6, HEL7, HEL9, HEL10, HEL11, HEL12, HEL13, HEL14, HEL16, HEL17, HEL18, HEL19, HEL20, HEL22, HEL23, HEL24, HEL25, HEL26: MT9102ET; HE_KEY_1.00u
HEL8, HEL28, HEL30, HEL32: MT9102ET; HE_KEY_1.50u
HEL15: MT9102ET; HE_KEY_1.75u
HEL21, HEL33: MT9102ET; HE_KEY_2.25u
JL1: FFC_12P; FFC_12P_1.00mm_TopContact
MHL1, MHL2, MHL3, MHL4: M2_NPTH; MountingHole_2.2mm_M2_NPTH
RBPL29: 0R_DNP; R3_R_0402_1005Metric_DNP
SL1, SL2: STAB_MX; STABILIZER_MX_2U

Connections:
+3V3A: AML1.16, AML2.16, AML3.16, AML4.16, AML5.16, CL1A.1, CL2A.1, CL3A.1, CL4A.1, CL5A.1, CL6A.1, CL7A.1, CL8A.1, CL9A.1, CL10A.1, CL11A.1, CL12A.1, CL13A.1, CL14A.1, CL15A.1, CL16A.1, CL17A.1, CL18A.1, CL19A.1, CL20A.1, CL21A.1, CL22A.1, CL23A.1, CL24A.1, CL25A.1, CL26A.1, CL28A.1, CL30A.1, CL32A.1, CL33A.1, CML1.1, CML2.1, CML3.1, CML4.1, CML5.1, HEL1.1, HEL2.1, HEL3.1, HEL4.1, HEL5.1, HEL6.1, HEL7.1, HEL8.1, HEL9.1, HEL10.1, HEL11.1, HEL12.1, HEL13.1, HEL14.1, HEL15.1, HEL16.1, HEL17.1, HEL18.1, HEL19.1, HEL20.1, HEL21.1, HEL22.1, HEL23.1, HEL24.1, HEL25.1, HEL26.1, HEL28.1, HEL30.1, HEL32.1, HEL33.1, JL1.12
ADC_L1: AML1.3, JL1.6
ADC_L2: AML2.3, JL1.4
ADC_L3: AML3.3, JL1.2
ADC_L4: AML4.3, JL1.1
ADC_L5: AML5.3, JL1.11
GND: AML1.6, AML1.7, AML1.8, AML2.4, AML2.6, AML2.7, AML2.8, AML3.6, AML3.7, AML3.8, AML4.2, AML4.4, AML4.6, AML4.7, AML4.8, AML4.13, AML4.14, AML5.6, AML5.7, AML5.8, AML5.12, AML5.13, AML5.14, AML5.15, CL1A.2, CL1B.2, CL2A.2, CL2B.2, CL3A.2, CL3B.2, CL4A.2, CL4B.2, CL5A.2, CL5B.2, CL6A.2, CL6B.2, CL7A.2, CL7B.2, CL8A.2, CL8B.2, CL9A.2, CL9B.2, CL10A.2, CL10B.2, CL11A.2, CL11B.2, CL12A.2, CL12B.2, CL13A.2, CL13B.2, CL14A.2, CL14B.2, CL15A.2, CL15B.2, CL16A.2, CL16B.2, CL17A.2, CL17B.2, CL18A.2, CL18B.2, CL19A.2, CL19B.2, CL20A.2, CL20B.2, CL21A.2, CL21B.2, CL22A.2, CL22B.2, CL23A.2, CL23B.2, CL24A.2, CL24B.2, CL25A.2, CL25B.2, CL26A.2, CL26B.2, CL28A.2, CL28B.2, CL30A.2, CL30B.2, CL32A.2, CL32B.2, CL33A.2, CL33B.2, CML1.2, CML2.2, CML3.2, CML4.2, CML5.2, CRGBL1.2, CRGBL2.2, CRGBL3.2, CRGBL4.2, CRGBL5.2, CRGBL6.2, CRGBL7.2, CRGBL8.2, CRGBL9.2, CRGBL10.2, CRGBL11.2, CRGBL12.2, CRGBL13.2, CRGBL14.2, CRGBL15.2, CRGBL16.2, CRGBL17.2, CRGBL18.2, CRGBL19.2, CRGBL20.2, CRGBL21.2, CRGBL22.2, CRGBL23.2, CRGBL24.2, CRGBL25.2, CRGBL26.2, CRGBL27.2, CRGBL29.2, CRGBL30.2, CRGBL31.2, DL1.1, DL2.1, DL3.1, DL4.1, DL5.1, DL6.1, DL7.1, DL8.1, DL9.1, DL10.1, DL11.1, DL12.1, DL13.1, DL14.1, DL15.1, DL16.1, DL17.1, DL18.1, DL19.1, DL20.1, DL21.1, DL22.1, DL23.1, DL24.1, DL25.1, DL26.1, DL27.1, DL29.1, DL30.1, DL31.1, HEL1.2, HEL2.2, HEL3.2, HEL4.2, HEL5.2, HEL6.2, HEL7.2, HEL8.2, HEL9.2, HEL10.2, HEL11.2, HEL12.2, HEL13.2, HEL14.2, HEL15.2, HEL16.2, HEL17.2, HEL18.2, HEL19.2, HEL20.2, HEL21.2, HEL22.2, HEL23.2, HEL24.2, HEL25.2, HEL26.2, HEL28.2, HEL30.2, HEL32.2, HEL33.2, JL1.5
HE_L01: AML1.12, CL1B.1, HEL1.3
HE_L02: AML1.13, CL2B.1, HEL2.3
HE_L03: AML1.14, CL3B.1, HEL3.3
HE_L04: AML1.15, CL4B.1, HEL4.3
HE_L05: AML2.12, CL5B.1, HEL5.3
HE_L06: AML2.13, CL6B.1, HEL6.3
HE_L07: AML2.14, CL7B.1, HEL7.3
HE_L08: AML1.5, CL8B.1, HEL8.3
HE_L09: AML1.4, CL9B.1, HEL9.3
HE_L10: AML1.2, CL10B.1, HEL10.3
HE_L11: AML1.1, CL11B.1, HEL11.3
HE_L12: AML2.5, CL12B.1, HEL12.3
HE_L13: AML2.2, CL13B.1, HEL13.3
HE_L14: AML2.1, CL14B.1, HEL14.3
HE_L15: AML3.12, CL15B.1, HEL15.3
HE_L16: AML3.13, CL16B.1, HEL16.3
HE_L17: AML3.14, CL17B.1, HEL17.3
HE_L18: AML3.15, CL18B.1, HEL18.3
HE_L19: AML4.12, CL19B.1, HEL19.3
HE_L20: AML4.15, CL20B.1, HEL20.3
HE_L21: AML3.5, CL21B.1, HEL21.3
HE_L22: AML3.4, CL22B.1, HEL22.3
HE_L23: AML3.2, CL23B.1, HEL23.3
HE_L24: AML3.1, CL24B.1, HEL24.3
HE_L25: AML4.5, CL25B.1, HEL25.3
HE_L26: AML4.1, CL26B.1, HEL26.3
HE_L30: AML5.2, CL32B.1, HEL32.3
HE_L31: AML5.1, CL33B.1, HEL33.3
HE_L32: AML5.4, CL28B.1, HEL28.3
HE_L33: AML5.5, CL30B.1, HEL30.3
MUX_A0: AML1.11, AML2.11, AML3.11, AML4.11, AML5.11, JL1.10
MUX_A1: AML1.10, AML2.10, AML3.10, AML4.10, AML5.10, JL1.9
MUX_A2: AML1.9, AML2.9, AML3.9, AML4.9, AML5.9, JL1.8
RGB_L: DL1.2, JL1.3
RGB_L_01: DL1.4, DL2.2
RGB_L_02: DL2.4, DL3.2
RGB_L_03: DL3.4, DL4.2
RGB_L_04: DL4.4, DL5.2
RGB_L_05: DL5.4, DL6.2
RGB_L_06: DL6.4, DL7.2
RGB_L_07: DL7.4, DL8.2
RGB_L_08: DL8.4, DL9.2
RGB_L_09: DL9.4, DL10.2
RGB_L_10: DL10.4, DL11.2
RGB_L_11: DL11.4, DL12.2
RGB_L_12: DL12.4, DL13.2
RGB_L_13: DL13.4, DL14.2
RGB_L_14: DL14.4, DL15.2
RGB_L_15: DL15.4, DL16.2
RGB_L_16: DL16.4, DL17.2
RGB_L_17: DL17.4, DL18.2
RGB_L_18: DL18.4, DL19.2
RGB_L_19: DL19.4, DL20.2
RGB_L_20: DL20.4, DL21.2
RGB_L_21: DL21.4, DL22.2
RGB_L_22: DL22.4, DL23.2
RGB_L_23: DL23.4, DL24.2
RGB_L_24: DL24.4, DL25.2
RGB_L_25: DL25.4, DL26.2
RGB_L_26: DL26.4, DL27.2
RGB_L_27: DL27.4, DL29.2, RBPL29.1
RGB_L_29: DL29.4, DL30.2, RBPL29.2
RGB_L_30: DL30.4, DL31.2
VBUS: CRGBL1.1, CRGBL2.1, CRGBL3.1, CRGBL4.1, CRGBL5.1, CRGBL6.1, CRGBL7.1, CRGBL8.1, CRGBL9.1, CRGBL10.1, CRGBL11.1, CRGBL12.1, CRGBL13.1, CRGBL14.1, CRGBL15.1, CRGBL16.1, CRGBL17.1, CRGBL18.1, CRGBL19.1, CRGBL20.1, CRGBL21.1, CRGBL22.1, CRGBL23.1, CRGBL24.1, CRGBL25.1, CRGBL26.1, CRGBL27.1, CRGBL29.1, CRGBL30.1, CRGBL31.1, DL1.3, DL2.3, DL3.3, DL4.3, DL5.3, DL6.3, DL7.3, DL8.3, DL9.3, DL10.3, DL11.3, DL12.3, DL13.3, DL14.3, DL15.3, DL16.3, DL17.3, DL18.3, DL19.3, DL20.3, DL21.3, DL22.3, DL23.3, DL24.3, DL25.3, DL26.3, DL27.3, DL29.3, DL30.3, DL31.3, JL1.7

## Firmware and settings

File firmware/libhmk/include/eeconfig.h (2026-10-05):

/*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
 * You should have received a copy of the GNU General Public License along with
 * this program. If not, see <https://www.gnu.org/licenses/>.
 */

#pragma once

#include "common.h"
#include "rgb.h"
#include "wear_leveling.h"

//--------------------------------------------------------------------+
// Keyboard Persistent Configuration
//--------------------------------------------------------------------+

// Magic number to identify the start of the configuration
#define EECONFIG_MAGIC_START 0x0A42494C
// Magic number to identify the end of the configuration
#define EECONFIG_MAGIC_END 0x0A4B4D48

// Keyboard calibration configuration
typedef struct __attribute__((packed)) {
  // Initial rest value of the key matrix. If the value is smaller than the
  // actual rest value, the key will have a dead zone at the beginning of the
  // keystroke. If the value is larger than the actual rest value, a longer
  // calibration process may be required.
  uint16_t initial_rest_value;
  // Minimum change in ADC values for the key to be considered bottom-out. If
  // the value is larger than the actual bottom-out threshold, the key will have
  // a dead zone at the end of the keystroke. If the value is smaller than the
  // actual bottom-out threshold, the distance calculation may be inaccurate
  // until the first bottom-out event.
  uint16_t initial_bottom_out_threshold;
} eeconfig_calibration_t;

// Keyboard options configuration
typedef union __attribute__((packed)) {
  struct __attribute__((packed)) {
    // Whether the XInput interface is enabled
    bool xinput_enabled : 1;
    bool _unused0 : 1;
    // Whether 8kHz polling rate is enabled. Only applicable if USB HS is
    // enabled. If disabled, the 1kHz polling rate is used instead.
    bool high_polling_rate_enabled : 1;
    // Reserved bits for future use
    uint16_t reserved : 13;
  };
  uint16_t raw;
} eeconfig_options_t;

_Static_assert(sizeof(eeconfig_options_t) == sizeof(uint16_t),
               "Invalid eeconfig_options_t size");

// Keyboard profile configuration
typedef struct __attribute__((packed)) {
  uint8_t keymap[NUM_LAYERS][NUM_KEYS];
  actuation_t actuation_map[NUM_KEYS];
  advanced_key_t advanced_keys[NUM_ADVANCED_KEYS];
  macro_node_t macros[NUM_MACRO_NODES];
  uint8_t gamepad_buttons[NUM_KEYS];
  gamepad_options_t gamepad_options;
  uint8_t tick_rate;
} eeconfig_profile_t;

// Persistent configuration version. The size of the configuration must be
// non-decreasing, so that the migration can assume that the new version is at
// least as large as the previous version.
#if defined(RGB_ENABLE)
#define EECONFIG_VERSION 0x0106
#else
#define EECONFIG_VERSION 0x0105
#endif

// Keyboard configuration
// Whenever there is a change in the configuration, `EECONFIG_VERSION` must be
// bumped. Make sure to update `eeconfig_reset()`, and add a migration function
// in `migration.c`.
typedef struct __attribute__((packed)) {
  // Global configurations
  // Magic number to identify the start of the configuration
  uint32_t magic_start;
  // Version of the configuration
  uint16_t version;

  // Calibration configuration
  eeconfig_calibration_t calibration;
  // Saved bottom-out threshold
  uint16_t bottom_out_threshold[NUM_KEYS];
  // Options configuration
  eeconfig_options_t options;

  // Current profile index
  uint8_t current_profile;
  // Last non-default profile index, used for profile swapping
  uint8_t last_non_default_profile;
#if defined(RGB_ENABLE)
  // Global addressable-lighting configuration.
  rgb_config_t rgb;
#endif
  // End of global configurations

  // Profiles
  eeconfig_profile_t profiles[NUM_PROFILES];

  // Magic number to identify the end of the configuration
  uint32_t magic_end;
} eeconfig_t;

_Static_assert(
    sizeof(eeconfig_t) <= WL_VIRTUAL_SIZE,
    "Keyboard configuration size must be at most the virtual storage size.");

extern const eeconfig_t *eeconfig;

#define CURRENT_PROFILE (eeconfig->profiles[eeconfig->current_profile])

//--------------------------------------------------------------------+
// Default Keyboard Configuration
//--------------------------------------------------------------------+

#if !defined(DEFAULT_CALIBRATION)
#error "DEFAULT_CALIBRATION is not defined"
#endif

#if !defined(DEFAULT_OPTIONS)
// Default global options
#define DEFAULT_OPTIONS                                                        \
  {                                                                            \
      .xinput_enabled = false,                                                 \
      .high_polling_rate_enabled = true,                                       \
  }
#endif

#if !defined(DEFAULT_KEYMAPS)
#error "DEFAULT_KEYMAPS is not defined"
#endif

#if !defined(DEFAULT_ACTUATION_POINT)
// Default actuation point
#define DEFAULT_ACTUATION_POINT 128
#endif

#if !defined(DEFAULT_GAMEPAD_OPTIONS)
// Default gamepad options
#define DEFAULT_GAMEPAD_OPTIONS                                                \
  {                                                                            \
      .analog_curve = {{4, 20}, {85, 95}, {165, 170}, {255, 255}},             \
      .keyboard_enabled = true,                                                \
      .snappy_joystick = true,                                                 \
  }
#endif

#if !defined(DEFAULT_TICK_RATE)
// Default tick rate
#define DEFAULT_TICK_RATE 30
#endif

//--------------------------------------------------------------------+
// Persistent Configuration API
//--------------------------------------------------------------------+

/**
 * @brief Initialize the persistent configuration module
 *
 * @return None
 */
void eeconfig_init(void);

/**
 * @brief Reset the persistent configuration to default values
 *
 * @return true if successful, false otherwise
 */
bool eeconfig_reset(void);

/**
 * @brief Reset a specific profile to default values
 *
 * @param profile Profile index
 *
 * @return true if successful, false otherwise
 */
bool eeconfig_reset_profile(uint8_t profile);

/**
 * @brief Write a value to a field in the persistent configuration
 *
 * @param field Field to write to
 * @param value Value to write
 *
 * @return true if successful, false otherwise
 */
#define EECONFIG_WRITE(field, value)                                           \
  wear_leveling_write(offsetof(eeconfig_t, field), value,                      \
                      sizeof(((eeconfig_t *)0)->field))

/**
 * @brief Write a value to a field in the persistent configuration
 *
 * @param field Field to write to
 * @param value Value to write
 * @param len Length of the value in bytes
 *
 * @return true if successful, false otherwise
 */
#define EECONFIG_WRITE_N(field, value, len)                                    \
  wear_leveling_write(offsetof(eeconfig_t, field), value, len)

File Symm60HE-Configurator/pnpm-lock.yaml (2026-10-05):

lockfileVersion: '9.0'

settings:
  autoInstallPeers: true
  excludeLinksFromLockfile: false

importers:

  .:
    dependencies:
      '@fontsource-variable/geist':
        specifier: ^5.2.9
        version: 5.3.0
      '@fontsource-variable/geist-mono':
        specifier: ^5.2.8
        version: 5.3.0
      mode-watcher:
        specifier: ^1.1.0
        version: 1.1.0(svelte@5.57.1(@typescript-eslint/types@8.71.0))
      runed:
        specifier: ^0.37.1
        version: 0.37.1(@sveltejs/kit@2.70.3(@sveltejs/vite-plugin-svelte@7.3.1(svelte@5.57.1(@typescript-eslint/types@8.71.0))(vite@8.3.2(jiti@2.7.0)))(svelte@5.57.1(@typescript-eslint/types@8.71.0))(typescript@6.0.3)(vite@8.3.2(jiti@2.7.0)))(svelte@5.57.1(@typescript-eslint/types@8.71.0))(zod@4.6.5)
      zod:
        specifier: ^4.4.3
        version: 4.6.5
    devDependencies:
      '@eslint/compat':
        specifier: ^2.1.0
        version: 2.1.1(eslint@9.39.5(jiti@2.7.0)(supports-color@7.2.0))
      '@eslint/js':
        specifier: ^9.39.5
        version: 9.39.5
      '@fontsource-variable/inter':
        specifier: ^5.2.8
        version: 5.3.0
      '@ianvs/prettier-plugin-sort-imports':
        specifier: ^4.7.1
        version: 4.7.1(prettier@3.9.9)(supports-color@7.2.0)
      '@internationalized/date':
        specifier: ^3.12.2
        version: 3.12.4
      '@lucide/svelte':
        specifier: ^1.25.0
        version: 1.51.0(svelte@5.57.1(@typescript-eslint/types@8.71.0))
      '@sveltejs/adapter-static':
        specifier: ^3.0.10
        version: 3.0.10(@sveltejs/kit@2.70.3(@sveltejs/vite-plugin-svelte@7.3.1(svelte@5.57.1(@typescript-eslint/types@8.71.0))(vite@8.3.2(jiti@2.7.0)))(svelte@5.57.1(@typescript-eslint/types@8.71.0))(typescript@6.0.3)(vite@8.3.2(jiti@2.7.0)))
      '@sveltejs/kit':
        specifier: ^2.70.1
        version: 2.70.3(@sveltejs/vite-plugin-svelte@7.3.1(svelte@5.57.1(@typescript-eslint/types@8.71.0))(vite@8.3.2(jiti@2.7.0)))(svelte@5.57.1(@typescript-eslint/types@8.71.0))(typescript@6.0.3)(vite@8.3.2(jiti@2.7.0))
      '@sveltejs/vite-plugin-svelte':
        specifier: ^7.2.0
        version: 7.3.1(svelte@5.57.1(@typescript-eslint/types@8.71.0))(vite@8.3.2(jiti@2.7.0))
      '@tailwindcss/vite':
        specifier: ^4.3.3
        version: 4.3.3(vite@8.3.2(jiti@2.7.0))
      '@types/w3c-web-hid':
        specifier: ^1.0.7
        version: 1.0.7
      bits-ui:
        specifier: ^2.18.1
        version: 2.19.5(@internationalized/date@3.12.4)(@sveltejs/kit@2.70.3(@sveltejs/vite-plugin-svelte@7.3.1(svelte@5.57.1(@typescript-eslint/types@8.71.0))(vite@8.3.2(jiti@2.7.0)))(svelte@5.57.1(@typescript-eslint/types@8.71.0))(typescript@6.0.3)(vite@8.3.2(jiti@2.7.0)))(svelte@5.57.1(@typescript-eslint/types@8.71.0))
      clsx:
        specifier: ^2.1.1
        version: 2.1.1
      eslint:
        specifier: ^9.39.5
        version: 9.39.5(jiti@2.7.0)(supports-color@7.2.0)
      eslint-config-prettier:
        specifier: ^10.1.8
        version: 10.1.8(eslint@9.39.5(jiti@2.7.0)(supports-color@7.2.0))
      eslint-plugin-prettier:
        specifier: ^5.5.6
        version: 5.5.6(eslint-config-prettier@10.1.8(eslint@9.39.5(jiti@2.7.0)(supports-color@7.2.0)))(eslint@9.39.5(jiti@2.7.0)(supports-color@7.2.0))(prettier@3.9.9)
      eslint-plugin-svelte:
        specifier: ^3.21.0
        version: 3.23.0(eslint@9.39.5(jiti@2.7.0)(supports-color@7.2.0))(svelte@5.57.1(@typescript-eslint/types@8.71.0))
      globals:
        specifier: ^17.7.0
        version: 17.13.0
      paneforge:
        specifier: ^1.0.2
        version: 1.0.2(svelte@5.57.1(@typescript-eslint/types@8.71.0))
      prettier:
        specifier: ^3.9.5
        version: 3.9.9
      prettier-plugin-svelte:
        specifier: ^3.5.2
        version: 3.5.2(prettier@3.9.9)(svelte@5.57.1(@typescript-eslint/types@8.71.0))
      prettier-plugin-tailwindcss:
        specifier: ^0.7.4
        version: 0.7.4(@ianvs/prettier-plugin-sort-imports@4.7.1(prettier@3.9.9)(supports-color@7.2.0))(prettier-plugin-svelte@3.5.2(prettier@3.9.9)(svelte@5.57.1(@typescript-eslint/types@8.71.0)))(prettier@3.9.9)
      shadcn-svelte:
        specifier: ^1.4.2
        version: 1.7.0(svelte@5.57.1(@typescript-eslint/types@8.71.0))
      svelte:
        specifier: ^5.56.6
        version: 5.57.1(@typescript-eslint/types@8.71.0)
      svelte-check:
        specifier: ^4.7.3
        version: 4.7.6(picomatch@4.0.7)(svelte@5.57.1(@typescript-eslint/types@8.71.0))(typescript@6.0.3)
      svelte-sonner:
        specifier: ^1.1.1
        version: 1.2.1(svelte@5.57.1(@typescript-eslint/types@8.71.0))
      tailwind-merge:
        specifier: ^3.6.0
        version: 3.7.0
      tailwind-variants:
        specifier: ^3.2.2
        version: 3.3.1(tailwind-merge@3.7.0)(tailwindcss@4.3.3)
      tailwindcss:
        specifier: ^4.3.3
        version: 4.3.3
      tw-animate-css:
        specifier: ^1.4.0
        version: 1.4.0
      typescript:
        specifier: ^6.0.3
        version: 6.0.3
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

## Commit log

2026-09-10 DOE60: three-board split hall-effect keyboard
    Left/right halves and a daughterboard for the DOE 60% filled-WKL layout,
    built on FN40HE's architecture: MT9102ET sensors into 8:1 analog muxes into
    an AT32F405RCT7.
    - 69 switch positions across both halves, covering all four layout options
    - each half keeps its own four muxes, so only multiplexed analog crosses the
    12-way ribbon to the daughterboard
    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
    [DOE60-BOM.csv, DOE60-Daughterboard.kicad_pcb, DOE60-Left.kicad_pcb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]
2026-09-10 Add GPLv3 licence and attribution
    Derived from FN40HE, which is GPLv3, so this carries the same licence.
    NOTICE.md lists every footprint, the board setup block and the MCU pinout
    taken from it, and notes that the DOE 60% layout is a reconstruction from
    published photographs rather than from any of that project's own data.
2026-09-10 Rename to Symm60HE; two-layer routing that is clean by construction
    Rename every DOE60-* file and reference to Symm60HE-*, matching the repo.
    The seven "DOE" mentions that remain are about the layout being reproduced,
    which is correct.
    Routing is now two layers with vias, at 0.2 mm trace / 0.15 mm clearance /
    0.45 mm vias -- a rule chosen so the 0.5 mm grid's own diagonal spacing
    (0.354 mm) satisfies it, and relaxed for any fabricator.
    Three fixes, each of which was a real defect in the single-layer pass:
    * A diagonal step now requires both of its orthogonal neighbours. Without
    it two nets cut the same gap from opposite corners and cross; cell
    ownership cannot see that, because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
    [DOE60-Daughterboard.kicad_pcb, Symm60HE-BOM.csv, Symm60HE-Daughterboard.kicad_pcb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]
2026-09-10 Draw the copper in the board images; make route.py idempotent
    The board renders showed pads and outlines but not a single trace, which
    made them useless for looking at the thing the last commit was about. They
    now draw segments and vias: orange for B.Cu, blue for F.Cu, white for a via,
    back layer under front, with the segment and via counts in the caption.
    route.py appended its output to whatever was already in the file, so running
    it twice laid a second set of traces over the first -- harmless inside
    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
    [Symm60HE-Daughterboard.kicad_pcb]
2026-09-10 Get the boards routing: SOIC muxes, FN40HE's pinout, a rail plane
    Four changes, none of which touch what the circuit is made of.
    SOIC-16 muxes. FN40HE fits the SN74LV4051A in TSSOP-16, and every remaining
    failure on the halves was an interior pin of one. A 0.65 mm pitch leaves
    0.25 mm between pads: no trace fits between them at any rule a fabricator
    will take, so those pins could only ever escape by via through a gap their
    neighbours already owned. Same chip in SOIC-16 -- SN74LV4051AD -- has
    1.27 mm pitch and 0.67 mm between pads, which a 0.2 mm trace clears with
    0.15 mm either side. It costs about 30 mm2 a package on boards that have
    room under the keycaps, and it hand solders.
    The MC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
    [Symm60HE-BOM.csv, Symm60HE-Daughterboard.kicad_pcb, Symm60HE-Left.kicad_pcb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]
2026-09-10 Drop the unused TSSOP footprint and two dead doc links
    The README pointed at docs/Symm60HE-preview.svg and
    docs/Symm60HE-case-section.svg, neither of which has ever existed -- the
    renders are the PNGs under docs/img/, and those references were left behind
    when the drawing step moved to raster. Point at what is actually there.
    The TSSOP-16 mux footprint has had nothing referencing it since the muxes
    moved to SOIC-16, so it goes; NOTICE.md now says it is not vendored rather
    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
2026-09-12 Replace repo contents with current Symm60HE project folder
    Adds firmware (libhmk), release fabrication outputs, pogo/neo PCB variants,
    Fusion 360 case sources, and updated docs/tools.
    [BOM.csv, CentralTray.stl, ControllerAntiRockLedges.step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]
2026-09-12 Fix analog mux LCSC part number; add Fusion 360 case setup script
    C7792 is an SN74LV373A latch (SOIC-20), not the SN74LV4051A mux. Replace it
    with C128414 (SN74LV4051ADR, SOIC-16) in the master BOM, both release
    generators, and every generated JLCPCB, Neo-pogo and PCBWay BOM. Rebuild the
    Neo-pogo and PCBWay release archives, SHA256SUMS and .sha256 sidecars.
    Add case/fusion360/fusion-setup/Symm60HECaseSetup, a Fusion 360 script that
    imports the placed reference STEP bodies into a grouped, grounded component
    tree with empty case components, and link it from the Fusion README.
    [PCBWay-BOM.csv, Symm60HE-BOM.csv, Symm60HE-Half-Panel-doe-wkl-BOM.csv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]
2026-09-13 Neo-pogo: 3 deg tent, 7 deg typing, 20 x 6 mm spring heads; integrated Fusion reference
    Regenerate the five Neo boards, both family panels, and the JLCPCB and
    PCBWay release packages for the narrower floating spring heads and the
    controller mounted left-to-right under the centre blocker. Rebuild the Fusion
    reference set around a single integrated master STEP
    (Symm60HE-case-reference-assembly.step) and rewrite the Fusion setup script
    to import it as one grounded assembly.
    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
    [CaseRef-ControllerUSBConnector.stl, CaseRef-ControllerUSBPlugEnvelope.stl, CaseRef-DaughterboardPCB.stl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]
2026-09-13 USB-C plug relief notch, vendor HRO model, componentized Fusion setup
    Add a 13 x 1 mm chamfered rear-edge notch to the FFC daughterboard and the
    Neo controller for USB-C plug clearance, attach the HRO TYPE-C-31-M-12 vendor
    STEP to the receptacle footprint, and export its checked placement
    (generated/usb-placement.json). Regenerate the plate DXFs, gasket pads and
    gallery renders.
    Rewrite the Fusion setup script to import each positioned reference STEP as
    its own component (plates with switches/keycaps, Hall PCBs with targets,
    floating pogo daughterboards, controller with FFCs, keepouts) and insert the
    untouched vendor USB-C body at J1.
    Note: the fabrication releases under release/ still car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
    [CaseRef-ControllerUSBConnector.stl, CaseRef-ControllerUSBPlugEnvelope.stl, CaseRef-DaughterboardPCB.stl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]
2026-09-13 Regenerate fabrication releases for the USB-C relief notch
    Re-run release.py, release_pcbway_neo_pogo.py (with panelize_neo_pogo and
    verify_neo_pogo) and release_neo_pogo.py on KiCad 10.0.5 so the JLCPCB
    daughterboard, the PCBWay Controller and Centre-Family panel, both release
    archives, manifests and SHA256SUMS all carry the notched 74-segment outline
    from the current sources. All twelve DRC reports are clean.
    [Symm60HE-Daughterboard-B_Cu.gbl, Symm60HE-Daughterboard-B_Mask.gbs, Symm60HE-Daughterboard-B_Silkscreen.gbo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]
2026-09-13 Fusion: bake transforms into component STEPs, verify placements, fix USB-C alignment
    Re-export every individual reference STEP with its assembly transform baked
    into the B-rep so Fusion's import-into-component keeps the small boards and
    pogo blocks in place. Add generated/component-placement.json with the expected
    bounds of each part and make the setup script verify every imported component
    against it (0.1 mm tolerance). Align the vendor USB-C body by rotating it,
    measuring its Fusion bounding box and translating onto the J1 envelope instead
    of trusting the vendor STEP's internal origin. Keepout envelopes now start
    hidden. Design name is 'Symm60HE Case - Componentized v3'.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
    [Symm60HE-ControllerUSBConnector.step, Symm60HE-ControllerUSBPlugEnvelope.step, Symm60HE-DaughterboardPCB.step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]
2026-09-13 Fusion: vendor FFC and tactile-switch models, populated PCB component bodies, model provenance
    Install exact LCSC/EasyEDA STEP models for the BOOMELE 1.0-12P FFC connector
    (C20111) and XKB TS-1187A-B-A-B switch (C318884) alongside the HRO USB-C, and
    record every model's source and SHA-256 in models/model-provenance.json with
    tools/verify_model_provenance.py to check it. The two Mill-Max pogo connectors
    stay as published-dimension fallbacks until the vendor STEPs are downloaded
    into models/vendor/.
    Export populated component bodies for the three PCBs
    (Symm60HE-*Components.step), add them to the Fusion setup script and the
    placement manifest, and add the XVX Whisper switch clearance profile a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
    [Button_XKB_TS-1187A-B-A-B_C318884.step, CaseRef-ControllerUSBConnector.stl, CaseRef-DaughterboardComponents.stl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]
2026-09-13 Fusion: exact Mill-Max 854/856 vendor STEPs replace the dimensioned pogo fallbacks
    Install the verified-supplier 12-position Mill-Max 854-22-012-30-004101
    spring and 856-10-012-30-051000 target STEPs under models/vendor/, lock their
    SHA-256 in model-provenance.json, and re-export every pogo reference body
    from them. The seated 854 pose translates only the exposed plungers; the
    housing is untouched. Bake the HRO USB-C world transform into its standalone
    STEP so the setup script no longer measures and re-translates it. Design name
    is 'Symm60HE Case - Componentized v6 exact vendor pogo'.
    [CaseRef-ControllerUSBConnector.stl, CaseRef-ControllerUSBPlugEnvelope.stl, CaseRef-DaughterboardComponents.stl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]
2026-09-14 Controller 57 x 27 mm straight rear edge; FPC jumpers into ZIF connectors; Neo Ergo mounting topology
    Extend the former local J1 setback across the complete rear edge of the FFC
    daughterboard and the Neo controller so the HRO USB-C shell projects 1.0 mm
    beyond one straight wall; no component or trace moves. Regenerate all
    fabrication releases, panels, Fusion references and renders for the 57 x 27 mm
    outline; all twelve DRC reports are clean.
    Re-specify the four board interconnects as custom 12-conductor FPC jumpers
    with 0.3 mm reinforced same-side tails into the BOOMELE C20111 ZIF connectors
    (length TBD from the case route) and update the BOM, READMEs and generators
    accordingly. Document th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
    [CaseRef-ControllerUSBConnector.stl, CaseRef-ControllerUSBPlugEnvelope.stl, CaseRef-DaughterboardComponents.stl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]
2026-09-14 Rewrite CONNECTOR-AND-TENTING.md for the 12-contact pogo-neo design
    The file still defined the superseded 16-contact 2 x 8 855/857 pair, 20 x 20
    mm heads and a target-side flex. Redefine it around the routed pogo-neo
    boards: the exact Mill-Max 854/856 12-position pair and its sourcing, the
    12-conductor pinout, the 57 x 27 mm controller, 20 x 6 mm floating modules
    with B.Cu ZIF, direct Hall-PCB targets, FPC jumpers, plate-only suspension,
    the 5.0 mm exact-model mating stack, the magnet DNP policy, a Neo Ergo
    comparison with the bare-pad option, the 16-contact coupon stream as history,
    and updated release gates. Mark the pogo README's 16-contact interface as
    superseded.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
2026-09-14 Correct the Neo Ergo PCB-side comparison: soldered receptacle, not bare pads
    The previous comparison asserted the Neo Ergo main PCB mates through bare
    gold pads; product photographs show a soldered connector body, consistent
    with a housed magnetic pogo receptacle. The pogo-neo topology therefore
    matches row for row. Keep the bare-pad Hall-PCB option as a possible
    simplification rather than a Neo Ergo feature.
2026-09-14 Record the confirmed Neo Ergo PCB-side connector
    A build-stream photograph of a bare right-half PCB shows the mating half:
    a black oval housing soldered at the centre-facing edge with a 2 x 7 gold
    contact array and a round magnet at each end.
2026-09-21 Replace the project with the reorganised T7 tree: ribbon keyboard is production, pogo archived
    Production design is now the outward-facing FPC keyboard with per-key
    SK6812MINI-E reverse-mount LEDs, a fifth SN74LV4051A mux per half so every
    alternate Hall position has its own channel, an SN74AHCT1G125 LED level
    shifter, a 50 x 31 mm daughterboard, 1.5 mm POM plates and 3 degree / 7 degree
    tent and typing angles. The universal half panel is fully populated (359
    placements) with routed NPTH alignment slots for the mutually exclusive
    positions, and eight fixed-layout Left/Right PCB pairs are released under
    release/layout-pcbs/ with matching BOM, CPL, Gerber ZIP, drill report and DRC.
    Reorganise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
    [BOOMELE_1.0-12P_C20111.step, Button_XKB_TS-1187A-B-A-B_C318884.step, CaseRef-ControllerUSBConnector.stl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]
2026-09-23 Move every LED into the switch's south RGB pocket
    The reverse-mount SK6812MINI-E sat 7.60 mm north of each key, shining into
    the Gateron KS-20's opaque cover rather than its window. All 65 LEDs now sit
    5.35 mm south of their key, in the pocket the cover is moulded for, so the
    board lights like a Wooting 60HE+ backlight instead of a pass-through for a
    transparent cap. Switches install with their RGB pocket toward the user; the
    plate cutout and the alignment pins are symmetric, so nothing else changes.
    Both halves were re-routed around the new apertures and are fully connected
    with no DRC errors: 247 vias on the left (was 251) and 418 on the right (was
    393). A handful of GND pads the aperture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
    [Symm60HE-Daughterboard-B_Cu.gbl, Symm60HE-Daughterboard-B_Mask.gbs, Symm60HE-Daughterboard-B_Silkscreen.gbo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]
2026-09-23 Add a side-by-side panel, refresh the Fusion handoff
    Both panel arrangements are now generated. The stacked one stays the panel the
    release orders, because it is the cheaper of the two in both the ways that
    matter for board price: 369.7 against 375.7 cm2 of material, and a 227.8 mm
    longest edge against 310.2 mm. The side-by-side arrangement keeps the halves in
    the orientation they are assembled in, joined across the centre gap by two
    tabs, with three tabs per board on the top and bottom rails and one on each
    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
    [DaughterboardPCB.step, DaughterboardPCBComponents.step, LeftPCB.step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]
2026-09-28 Add unrouted WKL fixed-layout PCB starters
    [Symm60HE-wkl-Left-unrouted.kicad_pcb, Symm60HE-wkl-Right-unrouted.kicad_pcb]
2026-09-28 Add unrouted starters for remaining PCBs
    [Symm60HE-Daughterboard-unrouted.kicad_pcb, Symm60HE-Left-4L-unrouted.kicad_pcb, Symm60HE-Left-PogoTarget-unrouted.kicad_pcb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]
2026-09-29 Publish routed WKL PCBs and remove unrouted starters
    [Symm60HE-Daughterboard-unrouted.kicad_pcb, Symm60HE-Left-4L-unrouted.kicad_pcb, Symm60HE-Left-PogoTarget-unrouted.kicad_pcb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]
2026-10-05 Publish 2026-10-05 production PCBs and firmware
    [ARTERY_AT32F405RCT7_C47090415.step, BHFUSE_BSMD0805-050-24V_C910822.step, BOM.csv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]

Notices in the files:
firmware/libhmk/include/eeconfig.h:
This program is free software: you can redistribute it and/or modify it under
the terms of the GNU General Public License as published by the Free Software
